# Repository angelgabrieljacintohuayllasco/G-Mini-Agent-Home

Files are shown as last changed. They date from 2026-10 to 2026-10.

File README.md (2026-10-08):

<p align="center">
  G-Mini Home: el compañero físico de G-Mini Agent
</p>

# G-Mini Home

**El compañero físico de [G-Mini Agent](https://github.com/angelgabrieljacintohuayllasco/G-Mini-Agent).**
Una carita con ojos animados que te escucha, te responde y muestra lo que
está haciendo el agente, mientras el trabajo real (controlar la PC, revisar el
correo, ejecutar tareas 24/7) corre en tu PC o en tu servidor.

Piensa en un "Alexa" con acceso a tu PC, tu laptop, tu celular y tu servidor:
el dispositivo pone la cara, el micrófono y el parlante; G-Mini pone el cerebro.

[English version](README.en.md)

## Variantes

| | Variante | Hardware | Dificultad | Costo aprox. | Guía |
|---|---|---|---|---|---|
| 1 | **Cara USB** | Arduino Uno o Nano + OLED 0,96" + 2 botones, conectado a la PC | Fácil | US$ 10-17 / S/ 55-95 | [usb-face](docs/guides/usb-face.md) |
| 2 | **Compañero WiFi** | ESP32-S3 + OLED (o TFT ST7789 / GC9A01) + micrófono I2S + parlante | Media | US$ 20-30 / S/ 115-185 | [esp32-wifi](docs/guides/esp32-wifi.md) |
| 3 | **Parlante con LEDs** | ESP32 + micrófono + parlante + anillo WS2812 (la cara son los LEDs) | Media | US$ 20-35 / S/ 115-220 | [speaker](docs/guides/speaker.md) |
| 4 | **Raspberry Pi** | Pi 4/5 o Zero 2 W + pantalla HDMI/SPI + audio USB | Fácil | US$ 75-140 / S/ 330-650 | [raspberry-pi](docs/guides/raspberry-pi.md) |
| 5 | **PC vieja o tablet** | El cliente de la Pi en cualquier PC, o la página de kiosco | Muy fácil | US$ 0 | [kiosk](docs/guides/kiosk.md) |
| | **Hologramas** | Pirámide y caja de Pepper, niebla, humo, LCD transparente, POV... | Variable | desde US$ 1 / S/ 3 | [hologramas](docs/holograms/README.md) |

<p align="center">
  Expresiones de la cara
</p>

## Cómo funciona

Arquitectura

Todos los dispositivos hablan con el núcleo de G-Mini por la **G-Mini Remote
API v1** (REST + WebSocket, puerto 8765):

- **Emparejamiento** con un código de 6 dígitos (o el enlace `gmini://pair?...`
  del QR): cada dispositivo tiene su propio token y se revoca por separado.
- **Estado del agente** por WebSocket (`idle`, `listening`, `thinking`,
  `acting`, `speaking` y la emoción) para animar los ojos, y avisos (`notify`).
- **Voz**: pulsar para hablar graba WAV de 16 kHz y lo envía a
  `/api/v1/voice/turn` (STT, agente y TTS en una sola llamada); la respuesta se
  reproduce mientras llega. "Oye G-Mini" opcional con `/api/v1/voice/wake`.
- **Superficies de nodo**: el agente puede usar el dispositivo (`display.face`,
  `display.text`, `led.set`, `relay.set`, `sensor.read`, `system.info`,
  `tts.speak`).

Los ojos salen de un mismo motor en C++ (AVR y ESP32), Python (Pi y PC) y
JavaScript (kiosco), generado desde [`common/expressions.json`](common/expressions.json):
parpadeo natural, mirada que se mueve, transiciones suaves a 30-40 cuadros por
segundo y nueve emociones. Detalles en [expresiones](docs/expressions.md).

## Empezar

Antes de nada: G-Mini tiene que ser accesible desde el dispositivo (modo
servidor o "Permitir conexiones" en Ajustes > Dispositivos > Este equipo). Ver
[conectar con G-Mini](docs/connect-gmini.md).

**Cara USB en 30 minutos** (Arduino + OLED + PC con G-Mini):

```bash
arduino-cli compile --fqbn arduino:avr:uno --library firmware/libraries/GMiniEyes firmware/arduino-usb-face
arduino-cli upload  --fqbn arduino:avr:uno -p COM5 firmware/arduino-usb-face
cd bridge && pip install -r requirements.txt
python gmini_serial_bridge.py --url http://127.0.0.1:8765 --pair 482913
```

**Compañero WiFi** (ESP32-S3): graba `gmini-home-esp32s3-oled-factory.bin` de
la release en `0x0` (o `pio run -e esp32s3-oled -t upload`), conéctate a la red
`G-Mini-Home-XXXX` (clave `gminihome`) y escribe tu WiFi, el servidor y el
código de emparejamiento.

**Raspberry Pi:**

```bash
cd raspberry-pi && sudo ./install.sh --url http://192.168.1.50:8765 --pair 482913
```

## Contenido del repositorio

```
firmware/
  esp32-companion/      firmware WiFi (PlatformIO, Arduino): 7 entornos + pruebas nativas
  arduino-usb-face/     sketch para Uno y Nano
  libraries/GMiniEyes   motor de ojos, rasterizado y protocolo serie (C++ portable)
  libraries/GMiniLink   HTTP, JSON, base64 y WAV en flujo, VAD (C++ portable)
bridge/                 puente serie <-> G-Mini en Python
raspberry-pi/           cliente pygame, instalador y servicio systemd
kiosk/                  página de kiosco para tablets (sin dependencias)
common/                 expressions.json y la biblioteca Python gmini_link
hardware/               BOM, cableado, carcasas OpenSCAD, STL, renders y plantillas
docs/                   guías, hologramas, seguridad, problemas y preguntas frecuentes
tools/                  generadores de presets, diagramas, plantillas y renders
tests/                  pruebas de Python (pytest)
```

## Desarrollo

```bash
pip install -r requirements-dev.txt
pytest                                                   # 87 pruebas de Python
ruff check common bridge raspberry-pi tools tests

cd firmware/esp32-companion
pio test -e native                                       # 41 pruebas en el host (motor, protocolo, HTTP/JSON/WAV)
pio run -e esp32s3-oled                                  # o cualquiera de los 7 entornos

python tools/codegen/gen_expressions.py                  # tras editar common/expressions.json
python tools/diagrams/build_all.py                       # diagramas SVG y tablas de cableado
python tools/templates/pepper_pyramid.py                 # plantillas de la pirámide
python tools/render_enclosures.py                        # STL y renders (necesita OpenSCAD)
python tools/e2e_smoke.py --url http://IP:8765 --pair CODIGO   # prueba contra un G-Mini real
```

La CI compila los 7 entornos del ESP32, el sketch para Uno, Nano y Nano con
bootloader viejo, corre las pruebas nativas y de Python, verifica que los
archivos generados estén al día y renderiza las carcasas con OpenSCAD. Cada
etiqueta `v*` publica una release con los binarios (imagen completa para `0x0`
y piezas sueltas), los `.hex`, los STL, los diagramas y los zips del puente y
del cliente de la Pi.

## Estado

Verificado en esta versión: compilación de todos los entornos del firmware
(tamaños en [grabación](docs/flashing.md)), pruebas nativas y de Python, y una
prueba de punta a punta contra un G-Mini real en modo servidor
(emparejamiento, `/me`, WebSocket con registro de nodo, TTS, STT y
`/voice/wake`). Falta probar con el hardware físico armado: audio I2S, cada
pantalla y el anillo LED se validan al construir el primer prototipo de cada
variante.

## Documentación

- [Conectar con G-Mini](docs/connect-gmini.md) y [protocolo serie](docs/serial-protocol.md)
- [Lista de materiales](hardware/bom.md), [cableado](hardware/README.md#cableado) y [carcasas](hardware/README.md#carcasas)
- [Grabar el firmware](docs/flashing.md)
- [Hologramas](docs/holograms/README.md)
- [Seguridad](docs/safety.md), [solución de problemas](docs/troubleshooting.md) y [preguntas frecuentes](docs/faq.md)
- [Cómo contribuir](CONTRIBUTING.md), [seguridad del proyecto](SECURITY.md) y [cambios](CHANGELOG.md)

## Licencia

Código bajo [MIT](LICENSE). Diseños de hardware y documentación bajo
[CC BY-SA 4.0](LICENSE-hardware.md).

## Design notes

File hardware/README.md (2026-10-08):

# Hardware

Todo lo físico de G-Mini Home: listas de materiales, cableado, carcasas
imprimibles y plantillas de corte. Licencia de estos diseños: CC BY-SA 4.0
([LICENSE-hardware.md](../LICENSE-hardware.md)).

| Carpeta | Contenido | Se genera con |
|---|---|---|
| [bom.md](bom.md) | Lista de materiales por variante con precios USD y PEN | a mano |
| [wiring/](wiring/) | Diagramas SVG y tablas de conexión por variante | `python tools/diagrams/build_all.py` |
| [enclosures/](enclosures/) | Carcasas paramétricas en OpenSCAD | a mano |
| [stl/](stl/) | Piezas listas para imprimir (STL binario) | `python tools/render_enclosures.py` |
| [renders/](renders/) | Imágenes de piezas y conjuntos | `python tools/render_enclosures.py` |
| [templates/](templates/) | Plantillas de corte de la pirámide de Pepper (SVG 1:1 y DXF) | `python tools/templates/pepper_pyramid.py` |

## Cableado

| Variante | Diagrama | Tabla |
|---|---|---|
| ESP32-S3 + OLED | [SVG](wiring/esp32s3-oled.svg) | [esp32s3-oled.md](wiring/esp32s3-oled.md) |
| ESP32-S3 + ST7789 / GC9A01 | [SVG](wiring/esp32s3-tft.svg) | [esp32s3-tft.md](wiring/esp32s3-tft.md) |
| ESP32-S3 parlante con LEDs | [SVG](wiring/esp32s3-speaker.svg) | [esp32s3-speaker.md](wiring/esp32s3-speaker.md) |
| ESP32-S3 + relés y LDR | [SVG](wiring/esp32s3-relays.svg) | [esp32s3-relays.md](wiring/esp32s3-relays.md) |
| ESP32 clásico (DevKit V1) | [SVG](wiring/esp32dev.svg) | [esp32dev.md](wiring/esp32dev.md) |
| Arduino Uno / Nano por USB | [SVG](wiring/arduino-usb-face.svg) | [arduino-usb-face.md](wiring/arduino-usb-face.md) |
| Raspberry Pi (botones) | [SVG](wiring/raspberry-pi.svg) | [raspberry-pi.md](wiring/raspberry-pi.md) |

Cableado ESP32-S3 + OLED

## Carcasas

| Modelo | Piezas | Vista |
|---|---|---|
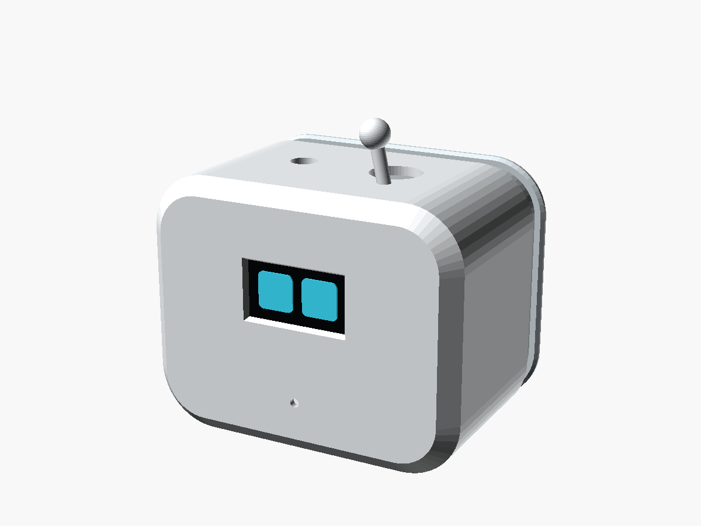
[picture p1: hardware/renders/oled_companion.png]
| [oled_companion.scad](enclosures/oled_companion.scad): cabecita para la OLED | [cuerpo](stl/oled_companion-shell.stl), [tapa](stl/oled_companion-back.stl) |  |
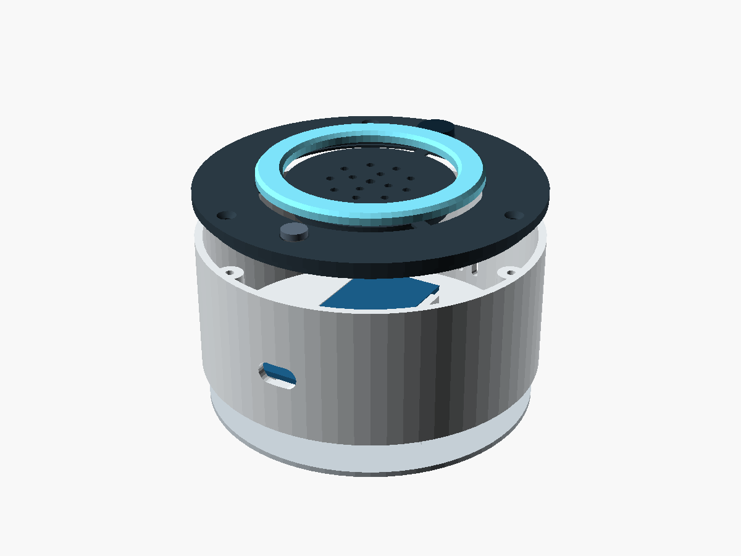
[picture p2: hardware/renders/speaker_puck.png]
| [speaker_puck.scad](enclosures/speaker_puck.scad): parlante con anillo LED | [cuerpo](stl/speaker_puck-base.stl), [tapa](stl/speaker_puck-top.stl), [difusor](stl/speaker_puck-diffuser.stl), [fondo](stl/speaker_puck-bottom.stl) |  |
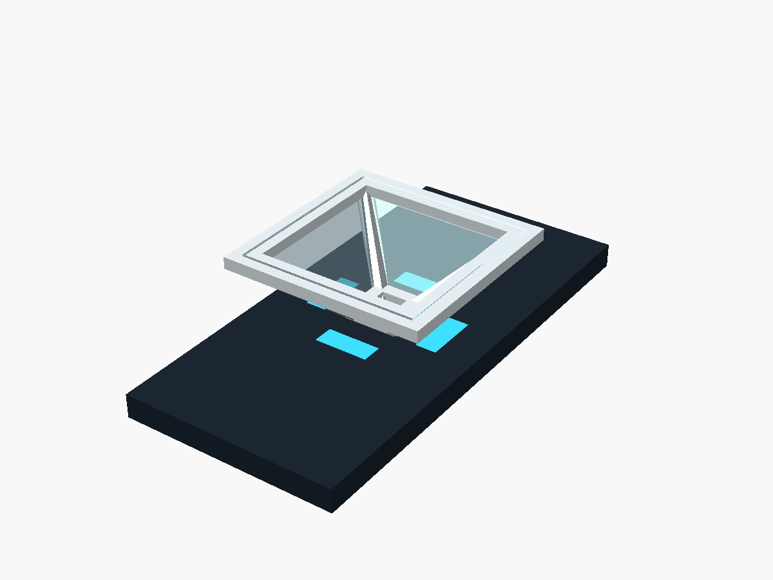
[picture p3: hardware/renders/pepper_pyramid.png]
| [pepper_pyramid.scad](enclosures/pepper_pyramid.scad): marco de la pirámide | [marco](stl/pepper_pyramid-frame.stl) |  |

### Impresión

- PLA o PETG, capa de 0,2 mm, 3 perímetros, 15-20 % de relleno.
- `oled_companion`: el cuerpo se imprime con la cara apoyada en la cama; la
  antena decorativa necesita un soporte pequeño (o ponla en `antenna = false`).
  La tapa se imprime con la cara exterior hacia abajo.
- `speaker_puck`: cuerpo y fondo sin soportes; la tapa boca abajo; el difusor
  en PETG natural o PLA blanco al 100 % de relleno para que la luz se reparta.
- `pepper_pyramid`: marco boca abajo (aro grande en la cama), sin soportes.
- Ajusta las medidas a tus módulos con el Customizer de OpenSCAD
  (Ventana > Personalizador): cada parámetro tiene un comentario.

### Exportar tus cambios

```bash
python tools/render_enclosures.py              # STL + PNG de todo
python tools/render_enclosures.py --only puck  # solo el parlante
```

El script busca OpenSCAD en `$OPENSCAD`, en el `PATH` o en
`E:\tools\openscad` (Windows). En Linux sin escritorio usa `xvfb-run`.

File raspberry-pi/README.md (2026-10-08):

# Cliente de pantalla de G-Mini Home

La cara de G-Mini a pantalla completa con voz, para Raspberry Pi (4, 5 o
Zero 2 W), mini PC o una PC vieja. Incluye la página de kiosco para tablets.

```bash
sudo ./install.sh --url http://192.168.1.50:8765 --pair 482913
```

Probar sin servidor: `python -m gmini_pi --demo --windowed` (desde esta
carpeta, con `PYTHONPATH=../common` si usas el repositorio).

| Archivo | Para qué |
|---|---|
| `install.sh` / `uninstall.sh` | Instala o quita el servicio `gmini-pi` |
| `config.example.toml` | Configuración comentada (se copia a `/etc/gmini-home/config.toml`) |
| `gmini-pi.service` | Plantilla del servicio de systemd |
| `gmini_pi/` | Código del cliente |

Guías: [Raspberry Pi](../docs/guides/raspberry-pi.md) y
[PC vieja o tablet](../docs/guides/kiosk.md).

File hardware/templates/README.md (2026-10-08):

# Plantillas de corte: pirámide de Pepper

Generadas por `tools/templates/pepper_pyramid.py` (no editar a mano). Todas las medidas en milímetros.
La guía completa está en [docs/holograms/pyramid.md](../../docs/holograms/pyramid.md).

| Pantalla | Lado corto útil | b (lado mayor) | a (lado menor) | Alto del trapecio | Altura | Material | Archivos |
|---|---|---|---|---|---|---|---|
| Teléfono 6,1" | 65 | 60 | 10 | 35.4 | 25.0 | PET o acetato de 0,5 mm (o tapa de CD) | [SVG](pyramid-phone-6.1-net.svg) · [DXF abanico](pyramid-phone-6.1-net.dxf) · [DXF piezas](pyramid-phone-6.1-pieces.dxf) |
| Teléfono 6,7" | 71 | 66 | 11 | 38.9 | 27.5 | PET o acetato de 0,5 mm | [SVG](pyramid-phone-6.7-net.svg) · [DXF abanico](pyramid-phone-6.7-net.dxf) · [DXF piezas](pyramid-phone-6.7-pieces.dxf) |
| Tablet 8" | 108 | 102 | 17 | 60.1 | 42.5 | PET de 0,5-0,75 mm | [SVG](pyramid-tablet-8-net.svg) · [DXF abanico](pyramid-tablet-8-net.dxf) · [DXF piezas](pyramid-tablet-8-pieces.dxf) |
| Tablet 10,1" | 136 | 128 | 21 | 75.7 | 53.5 | PET de 0,75 mm | [SVG](pyramid-tablet-10-net.svg) · [DXF abanico](pyramid-tablet-10-net.dxf) · [DXF piezas](pyramid-tablet-10-pieces.dxf) |
| Tablet 11" (4:3) | 168 | 158 | 26 | 93.3 | 66.0 | PET de 0,75-1 mm | [SVG](pyramid-tablet-11-net.svg) · [DXF abanico](pyramid-tablet-11-net.dxf) · [DXF piezas](pyramid-tablet-11-pieces.dxf) |
| Portátil 15,6" | 194 | 184 | 31 | 108.2 | 76.5 | PETG o acrílico de 2 mm | [SVG](pyramid-laptop-15.6-net.svg) · [DXF abanico](pyramid-laptop-15.6-net.dxf) · [DXF piezas](pyramid-laptop-15.6-pieces.dxf) |
| Monitor 24" | 299 | 282 | 47 | 166.2 | 117.5 | Acrílico de 2-3 mm | [SVG](pyramid-monitor-24-net.svg) · [DXF abanico](pyramid-monitor-24-net.dxf) · [DXF piezas](pyramid-monitor-24-pieces.dxf) |
| Monitor 27" | 336 | 318 | 53 | 187.4 | 132.5 | Acrílico de 3 mm | [SVG](pyramid-monitor-27-net.svg) · [DXF abanico](pyramid-monitor-27-net.dxf) · [DXF piezas](pyramid-monitor-27-pieces.dxf) |
| TV 32" | 398 | 378 | 63 | 222.7 | 157.5 | Acrílico de 3 mm con marco | [SVG](pyramid-tv-32-net.svg) · [DXF abanico](pyramid-tv-32-net.dxf) · [DXF piezas](pyramid-tv-32-pieces.dxf) |

- Las caras quedan a 45° de la pantalla: altura = (b - a) / 2 y alto del trapecio = altura x 1,414.
- Los lados del trapecio forman 54,74° con la base. En el abanico cada cara abre 70,53°.
- La imagen flotante puede medir como máximo la altura de la pirámide.
- Acrílico: las aristas se unen a 120°; bisela 30° los cantos laterales o une por fuera con cinta
  transparente o pegamento UV. Lámina fina: usa el abanico (SVG o DXF) y la pestaña de 8 mm.

## Caja de Pepper (una placa a 45°)

Pantalla boca arriba en el piso de una caja y una placa a 45° que cubre su profundidad.

| Pantalla | Pantalla (largo x ancho) | Placa (largo x ancho) | Alto interior mínimo |
|---|---|---|---|
| Teléfono 6,1" | 141 x 65 | 141 x 92 | 65 |
| Teléfono 6,7" | 155 x 71 | 155 x 101 | 71 |
| Tablet 8" | 172 x 108 | 172 x 152 | 108 |
| Tablet 10,1" | 218 x 136 | 218 x 192 | 136 |
| Tablet 11" (4:3) | 224 x 168 | 224 x 237 | 168 |
| Portátil 15,6" | 345 x 194 | 345 x 275 | 194 |
| Monitor 24" | 531 x 299 | 531 x 423 | 299 |
| Monitor 27" | 598 x 336 | 598 x 475 | 336 |
| TV 32" | 708 x 398 | 708 x 564 | 398 |

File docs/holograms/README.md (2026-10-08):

# Hologramas: la cara flotando en el aire

Ninguna de estas técnicas es holografía en sentido estricto (eso requiere
registrar la interferencia de un láser). Son ilusiones de **imagen flotante**:
reflejos en vidrio, proyección sobre medios casi invisibles o persistencia de la
visión. Bien hechas, convencen a cualquiera.

Todas usan las caras de G-Mini Home: el cliente de la Raspberry Pi o de una
PC (`display.layout = "pyramid"` o `"mirror"`), la página de kiosco en una
tablet (`?layout=pyramid`) o el video de la cara en un proyector o ventilador.

| Técnica | Dificultad | Costo (USD / PEN) | Tamaño | Lo mejor | Lo peor |
|---|---|---|---|---|---|
| [Pirámide de Pepper](pyramid.md) | Muy fácil | 1-25 / 3-90 | 3-15 cm | Barata, se ve desde 4 lados | Imagen chica, sala oscura |
| [Caja de Pepper](pepper-box.md) | Fácil | 10-40 / 35-150 | 10-40 cm | Muy brillante y nítida | Se ve desde un solo lado |
| [Pantalla de niebla](fog-screen.md) | Media | 60-200 / 220-750 | 30-100 cm | Imagen en el aire, se atraviesa | Agua, ruido, proyector |
| [Cortina de humo](smoke-curtain.md) | Media | 80-250 / 300-950 | 0,5-2 m | Grande, efecto de escenario | Humo, ventilación |
| [LCD transparente](transparent-lcd.md) | Media-alta | 0-60 / 0-230 | 15-60 cm | Imagen sobre objetos reales | Desarme delicado |
| [Ventilador POV](pov-fan.md) | Fácil (comprado) | 60-150 / 220-560 | 25-65 cm | Muy llamativo, en 3D aparente | Peligroso, ruidoso |
| [Volumétrica de barrido](volumetric.md) | Muy alta | 100-400 / 375-1500 | 10-20 cm | Volumen real, se ve desde todos lados | Proyecto de investigación |
| [Film o tul holográfico](holo-gauze.md) | Media | 30-150 / 110-560 | 0,5-3 m | Escala de escenario | Necesita proyector y oscuridad |
| [Imagen aérea](aerial-image.md) | Media | 30-70 / 110-260 | 5-20 cm | Imagen real "tocable" | Tenue, ángulo limitado |
| [Mirascopio con pantalla](mirascope.md) | Fácil | 15-40 / 55-150 | 3-6 cm | Imagen real nítida, curiosa | Muy chica |

Antes de empezar: [seguridad](../safety.md) (agua y niebla, humo, vidrio de
LCD, solventes, piezas giratorias).

## Recomendación

- **Primera vez:** pirámide de PET sobre el celular (15 minutos).
- **Para el escritorio:** caja de Pepper con una tablet o un monitor chico y el
  cliente en modo `mirror`: la mejor relación brillo/costo.
- **Para una feria o un evento:** cortina de niebla o tul con proyector.

Plantillas de corte de la pirámide: [hardware/templates/](../../hardware/templates/README.md).

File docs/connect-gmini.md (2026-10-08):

# Conectar un dispositivo con G-Mini

Todas las variantes hablan con el núcleo de G-Mini Agent por la
**G-Mini Remote API v1** (REST + WebSocket en el puerto `8765`). Esta página
explica qué tiene que estar listo del lado de G-Mini antes de armar nada.

## 1. ¿Dónde corre G-Mini?

| Núcleo | Quién puede conectarse | Uso típico |
|---|---|---|
| Escritorio (Windows), por defecto | Solo la misma PC (`127.0.0.1`) | Cara USB (variante 1) con el puente en esa PC |
| Escritorio con **Permitir conexiones** por Tailscale | Equipos de tu Tailscale (PC, Pi, celular) | Raspberry Pi, otra PC con el puente |
| Escritorio con **Permitir conexiones** en todas las redes | Cualquier equipo de tu red, incluido un ESP32 | ESP32 en la misma WiFi |
| Servidor 24/7 (`--headless --host 0.0.0.0`) | Tu red local (y Tailscale/VPN si lo configuras) | Todas las variantes |

"Permitir conexiones" está en **Ajustes > Dispositivos > Este equipo** de la
app de escritorio. Con Tailscale instalado, G-Mini escucha además en tu IP de
Tailscale sin abrirse a la WiFi. Un ESP32 **no puede** unirse a Tailscale:
para las variantes 2 y 3 usa "todas las redes" o un G-Mini en modo servidor en
tu red.

Modo servidor (Linux, mini PC o una laptop vieja):

```bash
python -m backend.main --headless --host 0.0.0.0 --port 8765
```

Comprueba desde otro equipo que responde (no necesita token):

```bash
curl http://IP-DEL-SERVIDOR:8765/api/v1/health
# {"ok": true, "protocol": 1, "mode": "server", ...}
```

Si no responde: firewall del sistema (permite el puerto TCP 8765 solo en tu red
privada), IP equivocada o el núcleo escuchando solo en `127.0.0.1`.

## 2. Emparejar

Cada dispositivo recibe su propio token y se puede revocar por separado.

1. En G-Mini: **Ajustes > Dispositivos > Este equipo > Emparejar un
   dispositivo**. Aparece un código de 6 dígitos y un QR con un enlace
   `gmini://pair?host=...&port=8765&code=...`. El código vence a los 5 minutos
   y sirve una sola vez.
2. En el dispositivo, según la variante:
   - ESP32: en el portal WiFi pega el código o el enlace completo, o por la
     consola serie: `emparejar 482913`.
   - Puente USB: `python gmini_serial_bridge.py --url http://IP:8765 --pair 482913`.
   - Raspberry Pi: `sudo ./install.sh --url http://IP:8765 --pair 482913`.
3. El dispositivo aparece en la lista de **Dispositivos**. Desde ahí lo
   revocas si lo pierdes o lo regalas.

Límites del servidor: 5 intentos por minuto por IP; al quinto fallo el código
se invalida. Pide uno nuevo.

Sin la app (por ejemplo, un servidor recién instalado), un token con permiso
`admin` puede pedir el código:

```bash
curl -X POST http://IP:8765/api/v1/pairing \
  -H "Authorization: Bearer $(cat ~/.local/share/g-mini/data/runtime/session_token)" \
  -H "Content-Type: application/json" \
  -d '{"label": "Cara de la sala", "device_type": "esp32", "scopes": ["chat", "voice", "node"]}'
```

## 3. Qué permisos usa cada variante

| Scope | Para qué |
|---|---|
| `voice` | Turnos de voz, palabra de activación y texto a voz |
| `chat` | Pedidos en texto después de "Oye G-Mini" y el turno de voz |
| `node` | Registrar la cara como superficie (`display.face`, `led.set`, `relay.set`...) |

`relay.set` controla cargas físicas: el agente lo pasa por su política de
aprobaciones igual que cualquier acción local.

## 4. Fuera de casa

Para usar un dispositivo fuera de tu red: Tailscale (PC, Pi) o un proxy con
TLS delante del servidor (Caddy, Nginx). El ESP32 acepta direcciones
`https://`, pero solo cifra: no verifica el certificado del servidor (ver
[seguridad](safety.md#red-y-tokens)). Nunca publiques el puerto 8765
directamente en tu router.

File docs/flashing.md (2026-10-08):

# Grabar el firmware

## ESP32 / ESP32-S3

### Entornos

| Entorno | Placa | Pantalla | Anillo |
|---|---|---|---|
| `esp32s3-oled` | ESP32-S3-DevKitC-1 N16R8 | SSD1306 128x64 | opcional |
| `esp32s3-sh1106` | ESP32-S3-DevKitC-1 N16R8 | SH1106 128x64 (1,3") | opcional |
| `esp32s3-st7789` | ESP32-S3-DevKitC-1 N16R8 | ST7789 240x280 | opcional |
| `esp32s3-gc9a01` | ESP32-S3-DevKitC-1 N16R8 | GC9A01 240x240 redonda | opcional |
| `esp32s3-speaker` | ESP32-S3-DevKitC-1 N16R8 | sin pantalla | sí |
| `esp32dev-oled` | ESP32 DevKit V1 (WROOM-32) | SSD1306 | opcional |
| `esp32dev-speaker` | ESP32 DevKit V1 (WROOM-32) | sin pantalla | sí |

### Con los binarios de la release

Cada release trae, por entorno:

- `gmini-home-<entorno>-factory.bin`: imagen completa, se graba en `0x0`.
- Las piezas sueltas por si prefieres grabarlas aparte:

| Archivo | ESP32-S3 | ESP32 clásico |
|---|---|---|
| `bootloader.bin` | `0x0` | `0x1000` |
| `partitions.bin` | `0x8000` | `0x8000` |
| `boot_app0.bin` | `0xe000` | `0xe000` |
| `firmware.bin` | `0x10000` | `0x10000` |

```bash
pip install esptool
# Imagen completa
esptool.py --chip esp32s3 --port COM7 --baud 921600 write_flash 0x0 gmini-home-esp32s3-oled-factory.bin
# Piezas sueltas (ESP32-S3)
esptool.py --chip esp32s3 --port COM7 --baud 921600 write_flash \
  0x0 bootloader.bin 0x8000 partitions.bin 0xe000 boot_app0.bin 0x10000 firmware.bin
```

Sin instalar nada: abre [esptool-js](https://espressif.github.io/esptool-js/)
en Chrome o Edge, conecta la placa, agrega el `factory.bin` en `0x0` y graba.

Si la placa no entra en modo de grabación: mantén **BOOT**, toca **RST** y
suelta BOOT. En el DevKitC-1 usa el conector USB marcado **UART** (o el
**USB** nativo; ambos sirven con esptool).

### Compilando con PlatformIO

```bash
pip install platformio
cd firmware/esp32-companion
pio run -e esp32s3-oled                 # compila
pio run -e esp32s3-oled -t upload       # compila y graba
pio device monitor                      # consola serie (115200)
pio test -e native                      # pruebas en la PC (necesita gcc)
```

Tamaños de referencia (PlatformIO, espressif32 7.1.3, Arduino-ESP32 2.0.17):

| Entorno | RAM | Flash |
|---|---|---|
| esp32s3-oled | 66,0 KB (20,1 %) | 1,09 MB de 6,25 MB (16,7 %) |
| esp32s3-st7789 / gc9a01 | 66,8 KB (20,4 %) | 1,17 MB (17,8 %) |
| esp32s3-speaker | 64,4 KB (19,6 %) | 1,06 MB (16,1 %) |
| esp32dev-oled | 66,1 KB (20,2 %) | 1,14 MB de 1,88 MB (58,0 %) |
| esp32dev-speaker | 64,5 KB (19,7 %) | 1,11 MB (56,2 %) |

Cambiar pines u opciones sin tocar el código: agrega `build_flags` al entorno,
por ejemplo `-DPIN_BTN_TALK=41 -DGMINI_RELAY_COUNT=0 -DGMINI_LED_COUNT=16`.
Todas las opciones están en `firmware/esp32-companion/include/config.h`.

## Arduino Uno / Nano

```bash
arduino-cli core install arduino:avr
arduino-cli lib install U8g2
arduino-cli compile --fqbn arduino:avr:uno --library firmware/libraries/GMiniEyes firmware/arduino-usb-face
arduino-cli upload  --fqbn arduino:avr:uno -p COM5 firmware/arduino-usb-face
```

La release incluye los `.hex` para Uno, Nano y Nano con bootloader viejo:

```bash
avrdude -p atmega328p -c arduino -P COM5 -b 115200 -U flash:w:arduino-usb-face-uno.hex:i
avrdude -p atmega328p -c arduino -P COM5 -b 57600  -U flash:w:arduino-usb-face-nano-old.hex:i
```

Tamaño: 29 300 bytes de flash (95 % de un Nano) y 1 644 bytes de RAM.

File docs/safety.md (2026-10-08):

# Seguridad

Lee esta página antes de construir. La mayoría de las variantes trabajan con
5 V de un cargador USB y son seguras; los riesgos reales están en los relés con
220 V, las baterías de litio, el agua cerca de la electricidad y los vidrios y
solventes de los hologramas.

## Tensión de red (relés)

- Los relés de los módulos para Arduino/ESP32 pueden conmutar 220 V, pero el
  **cableado de 220 V es peligroso**: una descarga puede matar y un mal empalme
  puede iniciar un incendio.
- Desenchufa todo antes de tocar los bornes. Usa caja cerrada (nada de
  protoboard con 220 V), cable de la sección adecuada, terminales con
  aislamiento, fusible y alivio de tensión en los cables.
- Respeta las distancias del módulo: no apoyes los bornes de 220 V sobre metal
  ni cerca de la placa del ESP32.
- Si no tienes experiencia, usa solo cargas de 5-12 V (tiras LED, ventiladores)
  o un enchufe inteligente comercial.
- `relay.set` pasa por la política de aprobaciones de G-Mini: no la desactives
  para cargas peligrosas (estufas, calentadores, bombas).

## Baterías de litio

- Usa celdas 18650 o LiPo con circuito de protección y un cargador para litio
  (TP4056 con protección, o un power bank). Nunca cargues una celda directa
  desde 5 V.
- No perfores, dobles ni aplastes baterías; si una se hincha, desconéctala y
  llévala a un punto de reciclaje.
- No dejes cargando sin supervisión dentro de carcasas cerradas de PLA: el PLA
  se deforma a ~60 °C.

## Herramientas y armado

- **Cautín**: superficie no inflamable, soporte, ventilación (el humo del
  flux irrita) y lávate las manos después de soldar (el estaño puede tener
  plomo).
- **Pistola de silicona**: la punta y la silicona queman (más de 150 °C).
  No la uses sobre cables de 220 V como aislante.
- **Cutter y acrílico**: regla metálica, corte hacia afuera del cuerpo, varias
  pasadas suaves. Lentes de protección al romper acrílico por la marca.
- **Impresora 3D**: no la dejes sola en las primeras capas; ventila si
  imprimes ABS o ASA.

## Agua, niebla y humo (hologramas)

- Los nebulizadores ultrasónicos funcionan en agua: alimenta siempre con una
  **fuente de 12/24 V de baja tensión** y deja la fuente de 220 V lejos del
  depósito y por encima del nivel del agua.
- Usa agua destilada: el agua de caño deja polvo blanco (minerales) en todo.
- Mantén proyectores, laptops y placas fuera del alcance de la niebla y de
  posibles derrames. Un trapo absorbente bajo el depósito ayuda.
- Máquinas de humo: el fluido de glicol irrita las vías respiratorias y activa
  detectores de humo; ventila la sala. El **hielo seco** desplaza el oxígeno:
  nunca en espacios cerrados ni en contacto con la piel (quema por frío).

## LCD transparente

- El vidrio de los LCD se rompe en astillas muy filosas: guantes anticorte y
  lentes durante todo el desarme.
- **Retroiluminación**: los monitores viejos con CCFL (tubos) tienen
  inversores de alta tensión (más de 1000 V) que retienen carga; desenchufa,
  espera varios minutos y no toques el inversor. Los tubos contienen mercurio:
  no los rompas y llévalos a reciclaje.
- **Polarizador**: para despegar adhesivos usa calor suave (secador de pelo) o
  alcohol isopropílico. **No uses acetona sobre el vidrio ni sobre plásticos**:
  disuelve los polarizadores y el acrílico. Trabaja ventilado y lejos de
  llamas (el alcohol es inflamable).
- No presiones el vidrio del LCD sin su marco: se agrieta y deja de funcionar.

## Ventiladores POV y piezas giratorias

- Las aspas giran a cientos de RPM: usa siempre la cúpula o protección,
  fíjalos firmes a la pared o a una base pesada y mantenlos fuera del alcance
  de niños y mascotas.
- Los proyectos volumétricos de barrido requieren equilibrado y una cubierta
  transparente cerrada: una pieza que se suelta a alta velocidad es un
  proyectil.

## Láser y proyectores

- No mires directo al haz de un proyector ni de un láser; en cortinas de humo
  apunta la proyección por encima de la altura de los ojos.

## Red y tokens

- Cada dispositivo tiene su propio token: si lo pierdes, lo regalas o lo
  desarmas, **revócalo** en Ajustes > Dispositivos.
- En el ESP32 el token se guarda en la NVS sin cifrar (lo puede leer quien
  tenga la placa en la mano). Para producción activa el cifrado de flash y de
  NVS de ESP-IDF; para casa, revocar alcanza.
- Las direcciones `https://` en el ESP32 cifran la conexión pero **no
  verifican el certificado** del servidor. Úsalas solo con tu propio proxy y
  prefiere la red local o una VPN.
- Con la palabra de activación encendida, frases cortas de lo que se dice cerca
  viajan a tu servidor G-Mini (no a terceros). Avisa a quienes vivan contigo.
- No expongas el puerto 8765 a internet ni actives "todas las redes" en una
  WiFi pública.

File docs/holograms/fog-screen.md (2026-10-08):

# Pantalla de niebla

Pantalla de niebla

Una cortina fina y laminar de niebla de agua recibe la imagen de un proyector
colocado detrás. La niebla es casi invisible a simple vista, pero dispersa la
luz: la cara aparece flotando en el aire y se puede atravesar con la mano.

**Dificultad:** media. **Costo:** US$ 60-200 / S/ 220-750 (sin proyector:
US$ 25-50 / S/ 90-190). **Tiempo:** un fin de semana.

## Materiales

| Material | Costo |
|---|---|
| Nebulizador ultrasónico de 12/24 V (1-3 cabezales) con su fuente | US$ 10-25 / S/ 40-95 |
| Recipiente plástico (40 x 20 x 15 cm aprox.) | US$ 3-8 / S/ 10-30 |
| 1-2 ventiladores de PC de 12 V (80-120 mm) | US$ 3-8 / S/ 10-30 |
| Pajillas (sorbetes) cortadas a 4-6 cm, como panal de flujo laminar | US$ 1-2 / S/ 3-8 |
| Tubo o canal de PVC de 30-60 cm con ranura de 5 mm | US$ 3-8 / S/ 10-30 |
| Proyector (mini LED o un proyector viejo) | US$ 40-150 / S/ 150-560 |
| Agua destilada | US$ 1-2 / S/ 3-8 |

## Pasos

1. Pon el nebulizador en el recipiente con agua destilada (nivel según su
   flotador).
2. Tapa el recipiente y monta los ventiladores soplando hacia adentro: empujan
   la niebla hacia la salida superior.
3. Encima, fija el canal con la ranura y llénalo de pajillas paradas, bien
   apretadas: convierten el flujo turbulento en una cortina lisa (laminar).
4. Regula los ventiladores (bajo voltaje o un regulador PWM) hasta que la
   cortina suba recta 30-60 cm sin abrirse.
5. Pon el proyector detrás de la cortina, a la altura del centro, y proyecta la
   cara a pantalla completa con fondo negro (`gmini_pi --windowed` en la PC del
   proyector, o la página de kiosco).
6. Oscurece la sala. El observador mira desde el lado opuesto al proyector.

## Ventajas y desventajas

- El efecto más "de película": la imagen está en el aire y se atraviesa.
- Se ve mejor de frente al proyector (la niebla dispersa más hacia adelante).
- Corrientes de aire la deforman; necesita oscuridad.
- Moja lo que está cerca si la cortina es muy densa.

## Seguridad

Baja tensión (12/24 V) dentro y cerca del agua; la fuente de 220 V afuera y
por encima del nivel del agua. Proyector y electrónica lejos de la niebla. Ver
[seguridad: agua y niebla](../safety.md#agua-niebla-y-humo-hologramas).

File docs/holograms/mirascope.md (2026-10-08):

# Mirascopio con pantalla redonda

Mirascopio

Dos espejos parabólicos enfrentados (el de arriba con un agujero en el centro)
forman la imagen real de lo que está en el fondo justo sobre la abertura. El
juguete clásico muestra una moneda "flotando"; si en el fondo pones una
pantalla redonda GC9A01 con la cara, los ojos aparecen flotando arriba.

**Dificultad:** fácil. **Costo:** US$ 15-40 / S/ 55-150. **Tiempo:** 1 hora.

## Materiales

| Material | Costo |
|---|---|
| Mirascopio de juguete de 15-23 cm | US$ 10-25 / S/ 35-95 |
| Pantalla GC9A01 de 1,28" y un ESP32-S3 (variante `esp32s3-gc9a01`) | US$ 10-15 / S/ 75-105 |
| Cable plano fino para sacar la conexión | US$ 1-2 / S/ 3-8 |

## Pasos

1. Abre el mirascopio y pega la pantalla en el centro del espejo inferior, mirando
   hacia arriba. Saca el cable por el borde (los espejos se unen a presión).
2. Graba el firmware `esp32s3-gc9a01` y sube el brillo al máximo
   (`brillo 255` en la consola).
3. Cierra el mirascopio: la cara aparece sobre la abertura superior. Mira desde
   un costado, un poco por encima.

## Ventajas y desventajas

- Imagen real nítida y sorprendente, ocupa muy poco.
- Muy pequeña (del tamaño de la pantalla) y sensible a la luz del techo.
- El cable de la pantalla tiene que pasar entre los espejos.

## Seguridad

Sin riesgos especiales. El ESP32 y la pantalla calientan poco, pero deja el
cable con algo de holgura para no doblarlo.

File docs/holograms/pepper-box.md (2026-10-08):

# Caja de Pepper (una placa a 45°)

Caja de Pepper

La versión de teatro del siglo XIX: una pantalla boca arriba en el piso de una
caja oscura y una placa transparente a 45° delante del observador. La pantalla
queda oculta y su reflejo aparece "dentro" de la caja, detrás del vidrio, con
lo que haya al fondo visible a través de la cara.

**Dificultad:** fácil. **Costo:** US$ 10-40 / S/ 35-150. **Tiempo:** 2-3 horas.

## Medidas

Para una pantalla de largo L y ancho (profundidad) P:

- Placa: L x (P x 1,41).
- Interior de la caja: L de ancho, P de profundidad y al menos P de alto.
- Tabla de tamaños comunes en [hardware/templates/README.md](../../hardware/templates/README.md#caja-de-pepper-una-placa-a-45).

## Materiales

| Material | Costo |
|---|---|
| Vidrio fino de 2 mm (vidriería), acrílico de 2 mm o PET de 0,5 mm | US$ 3-15 / S/ 10-55 |
| Cartón pluma o MDF de 3 mm para la caja | US$ 3-12 / S/ 10-45 |
| Pintura negra mate o cartulina negra | US$ 2-5 / S/ 6-18 |
| Tablet, monitor chico o pantalla HDMI | la que tengas |

## Pasos

1. Arma una caja abierta por delante, con el interior negro mate (cuanto más
   negro, más contraste).
2. Pon la pantalla boca arriba en el piso de la caja.
3. Fija la placa en diagonal: arriba contra la pared del fondo y abajo contra el
   borde frontal del piso (45°). Ranuras en las paredes laterales o dos listones
   triangulares sirven de guía.
4. Muestra la cara espejada: `python -m gmini_pi --layout mirror` o el kiosco
   con `?layout=mirror`. Si la cara sale cabeza abajo, gira la pantalla 180°.
5. Opcional: pon un objeto real al fondo de la caja (una figura, una planta):
   la cara flota delante de él.

## Ventajas y desventajas

- Muy brillante y nítida, incluso con algo de luz en la sala.
- Puede ser tan grande como la pantalla que pongas.
- Se ve bien desde un solo lado y en un ángulo de unos 60°.
- El vidrio refleja también la sala: cuanto más oscuro el frente, mejor.

## Seguridad

Lija o encinta los cantos del vidrio. No dejes la pantalla en una caja
cerrada sin ventilación durante horas.

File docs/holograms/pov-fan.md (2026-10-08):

# Ventilador holográfico (POV)

Ventilador POV

Aspas con tiras de LEDs que giran a 600-800 RPM; un controlador enciende cada
LED en el instante justo de cada vuelta y la persistencia de la visión
"pinta" una imagen que parece flotar en el aire, con mucha profundidad aparente.

**Dificultad:** fácil comprado, alta casero. **Costo:** US$ 60-150 / S/ 220-560
(25-65 cm). **Tiempo:** 1 hora (montaje).

## Materiales

| Material | Costo |
|---|---|
| Ventilador holográfico comercial de 30-65 cm con app o WiFi | US$ 60-150 / S/ 220-560 |
| Cúpula o carcasa protectora (muchos la traen) | US$ 10-30 / S/ 35-110 |
| Soporte de pared firme | US$ 5-15 / S/ 18-55 |

Casero: aspas impresas, tira APA102 (no WS2812: hace falta refresco rápido), un
ESP32, un sensor Hall con imán para sincronizar y un motor brushless con
variador. Es un proyecto avanzado por el equilibrado y la seguridad.

## Pasos (comercial)

1. Fija el soporte a la pared o a una base pesada y monta el ventilador con la
   protección puesta.
2. Exporta un video corto de la cara en formato cuadrado y fondo negro: graba
   la pantalla de `python -m gmini_pi --demo --windowed` (por ejemplo con OBS)
   o usa las imágenes de `docs/img/`.
3. Conviértelo con la herramienta del fabricante y súbelo por su app.
4. Para que reaccione en vivo: algunos modelos aceptan transmisión por WiFi o
   HDMI; si no, prepara un video por emoción y cámbialos desde el agente.

## Ventajas y desventajas

- Muy llamativo y brillante, se ve con luz ambiente.
- Imagen grande con poco espacio.
- Hace ruido, vibra y la integración en vivo depende del fabricante.
- Las aspas son peligrosas sin protección.

## Seguridad

Siempre con la cúpula o protección, fijación firme y fuera del alcance de
niños y mascotas. Ver [seguridad](../safety.md#ventiladores-pov-y-piezas-giratorias).

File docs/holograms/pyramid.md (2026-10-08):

# Pirámide de Pepper (4 caras)

Pirámide de Pepper

Cuatro trapecios transparentes forman una pirámide invertida apoyada sobre una
pantalla horizontal. Cada cara está a 45° y refleja una de las cuatro vistas
que muestra la pantalla; el observador ve la cara flotando dentro de la
pirámide, desde cualquiera de los cuatro lados.

**Dificultad:** muy fácil. **Costo:** US$ 1-25 / S/ 3-90. **Tiempo:** 15 min (PET) a 1 h (acrílico).

## Medidas

Plantillas listas para imprimir o cortar en [hardware/templates/](../../hardware/templates/README.md)
(SVG a escala 1:1 y DXF), para teléfono 6,1" y 6,7", tablets de 8", 10,1" y 11",
portátil de 15,6", monitores de 24" y 27" y TV de 32". Para otro tamaño:

- **b** (lado mayor) = 95 % del lado corto útil de la pantalla.
- **a** (lado menor) = b / 6.
- Altura de la pirámide = (b - a) / 2. Alto de cada trapecio = altura x 1,414.
- Los lados del trapecio forman 54,74° con la base.
- La imagen flotante mide como máximo la altura de la pirámide.

Ejemplo, teléfono de 6,1": b = 60 mm, a = 10 mm, trapecio de 35,4 mm de alto.

## Materiales

| Material | Para | Costo |
|---|---|---|
| Lámina PET o acetato 0,5 mm (tapa de carpeta, blíster transparente, caja de CD) | Teléfono y tablet | US$ 0-2 / S/ 0-8 |
| PETG o acrílico 2-3 mm | Monitor o TV | US$ 10-25 / S/ 35-90 por plancha |
| Cinta transparente o pegamento UV | Unir aristas | US$ 1-5 / S/ 3-20 |
| Opcional: marco impreso ([pepper_pyramid.scad](../../hardware/enclosures/pepper_pyramid.scad)) | Sin pegamento | ~10 g de PLA |

## Pasos

1. Imprime la plantilla al 100 % (sin "ajustar a la página") y comprueba la
   regla de 50 mm.
2. Lámina fina: pega la plantilla debajo, marca con cutter las líneas azules
   (pliegues) sin atravesar y corta las rojas. Dobla y cierra con la pestaña.
3. Acrílico: corta los cuatro trapecios del DXF de piezas (láser o sierra de
   calar), lija los cantos y únelos por fuera con cinta o pegamento UV. Las
   aristas quedan a 120°: un bisel de 30° en los cantos laterales mejora la
   unión.
4. En la pantalla abre la cara en disposición de pirámide:
   - Raspberry Pi o PC: `python -m gmini_pi --layout pyramid` (o
     `display.layout = "pyramid"`).
   - Tablet: `http://IP:8088/?layout=pyramid` (kiosco) o `?layout=pyramid&demo=1`.
5. Apoya la pirámide con la punta chica al centro de las cuatro vistas, apaga la
   luz y mira de frente a una de las caras, a la altura de la pirámide.

## Ventajas y desventajas

- Más barata imposible y se ve desde cuatro lados.
- Funciona con el celular que ya tienes.
- La imagen es chica (hasta la altura de la pirámide) y necesita poca luz.
- Las láminas gruesas dan imagen doble (reflejan ambas caras): usa la más
  fina que mantenga la forma.

## Seguridad

Cutter con regla metálica y corte hacia afuera del cuerpo. El acrílico astilla
al romperlo por la marca: lentes de protección.

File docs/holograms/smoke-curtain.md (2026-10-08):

# Cortina de humo y viento

Cortina de humo

Parecida a la pantalla de niebla, pero más grande: una máquina de humo
alimenta un túnel de viento con ventiladores y un difusor tipo panal, que
forma una lámina de humo vertical. Un proyector desde abajo o desde atrás pone
la cara sobre ella.

**Dificultad:** media. **Costo:** US$ 80-250 / S/ 300-950. **Tiempo:** un fin de semana.

## Materiales

| Material | Costo |
|---|---|
| Máquina de humo de 400-900 W con fluido | US$ 35-80 / S/ 130-300 |
| 4-6 ventiladores de PC de 12 V y una fuente de 12 V / 3 A | US$ 15-30 / S/ 55-110 |
| Caja de MDF o cartón pluma de 60-100 cm de largo | US$ 10-25 / S/ 35-95 |
| Panal de pajillas o malla de panal de abeja (honeycomb) | US$ 3-15 / S/ 10-55 |
| Proyector | US$ 40-150 / S/ 150-560 |

## Pasos

1. Arma un túnel largo y bajo; los ventiladores en la base soplan hacia arriba.
2. Cierra la salida superior con el panal (5-8 cm de profundidad) para que el
   aire salga parejo.
3. Conecta la salida de la máquina de humo a un costado del túnel.
4. Ajusta la velocidad de los ventiladores hasta que la lámina suba recta
   1-2 m; demasiado aire la rompe, muy poco la deja caer.
5. Proyecta la cara desde abajo en ángulo o desde atrás, en una sala oscura y
   sin corrientes.

## Ventajas y desventajas

- Tamaño de escenario y efecto espectacular.
- Consume fluido y la sala termina con humo: no es para todos los días.
- Las corrientes de aire la deforman.

## Seguridad

El fluido de glicol irrita y activa detectores de humo: ventila y avisa. El
hielo seco desplaza el oxígeno: nunca en espacios cerrados. No apuntes el
proyector a los ojos. Ver [seguridad](../safety.md#agua-niebla-y-humo-hologramas).

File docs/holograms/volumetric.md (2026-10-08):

# Volumétrica de barrido (espejo o pantalla giratoria)

Volumétrica

Una superficie (pantalla difusora o espejo inclinado) gira muy rápido mientras
un proyector de alta frecuencia dibuja en cada ángulo la "rebanada" de la imagen
3D que corresponde. El ojo integra todas las rebanadas: la cara ocupa un volumen
real y se ve en 3D desde cualquier lado, sin gafas.

**Dificultad:** muy alta (proyecto de investigación). **Costo:** US$ 100-400 /
S/ 375-1500. **Tiempo:** semanas.

## Materiales

| Material | Costo |
|---|---|
| Proyector DLP de alta frecuencia (kits de desarrollo DLP o un DMD reutilizado) | US$ 60-250 / S/ 220-940 |
| Motor brushless con variador y sensor de posición (encoder o Hall) | US$ 20-60 / S/ 75-225 |
| Superficie difusora rígida y liviana (acrílico esmerilado) | US$ 5-15 / S/ 18-55 |
| Cúpula de acrílico transparente | US$ 20-60 / S/ 75-225 |
| Microcontrolador para sincronizar motor y proyector | US$ 5-15 / S/ 18-55 |

## Pasos (resumen)

1. Monta la superficie centrada en el eje y equilíbrala con pesos hasta que no
   vibre a 600-1200 RPM.
2. Sincroniza la posición del motor con el proyector: cada cuadro se proyecta en
   un ángulo fijo (por ejemplo 100-200 rebanadas por vuelta).
3. Genera las rebanadas a partir de un modelo 3D de la cara (por ejemplo,
   extruyendo los ojos del motor como volúmenes) y envíalas al proyector.
4. Encierra todo en la cúpula antes de hacer girar el motor.

## Ventajas y desventajas

- Es la única técnica de la lista con volumen real.
- Requiere sincronización precisa, proyector especial y mucho ajuste.
- Imagen pequeña y tenue; el motor hace ruido.

## Seguridad

Superficie girando a alta velocidad: equilibrado, eje robusto y cúpula cerrada
siempre. Ver [seguridad](../safety.md#ventiladores-pov-y-piezas-giratorias).

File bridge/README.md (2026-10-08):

# Puente USB de G-Mini Home

Conecta la cara USB (Arduino Uno o Nano con OLED) con G-Mini Agent: reenvía el
estado del agente a la placa por el puerto serie y pone la voz con el
micrófono y los parlantes de la PC.

```bash
python -m venv .venv
.venv\Scripts\activate                 # Linux/macOS: source .venv/bin/activate
pip install -r requirements.txt
python gmini_serial_bridge.py --url http://127.0.0.1:8765 --pair 482913
```

Después del primer emparejamiento basta con `python gmini_serial_bridge.py`.
Opciones: `python gmini_serial_bridge.py --help`.

Guía completa: [docs/guides/usb-face.md](../docs/guides/usb-face.md).
Protocolo serie: [docs/serial-protocol.md](../docs/serial-protocol.md).

Requisitos: Python 3.11 o más nuevo; en Linux, `sudo apt install libportaudio2`.

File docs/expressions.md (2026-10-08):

# Expresiones de la cara

Las caras de todas las variantes (OLED, TFT, pygame, kiosco y anillo LED)
salen del mismo motor y de una única tabla: [`common/expressions.json`](../common/expressions.json).

Expresiones

Estados

## Cómo funciona el motor

- **Emoción** (campo `emotion` del protocolo) y **estado** (`status`) se
  combinan: la emoción define la forma de los ojos y el estado agrega
  comportamiento (escuchar agranda los ojos, pensar los entrecierra y mira
  arriba, trabajar barre la mirada de lado a lado, hablar muestra la boca).
- Todo cambio se interpola con suavizado exponencial (constante de tiempo de
  70 ms para la forma y 45 ms para la mirada): no hay saltos aunque el agente
  cambie de emoción varias veces por segundo.
- Parpadeo con curva de aceleración (70 ms cerrar, 35 ms cerrado, 110 ms
  abrir), cada 2-6 s al azar y a veces doble, como las personas.
- Movimientos de mirada ("sacadas") al azar en reposo.
- Los cambios de forma (corazones de `love`, cruces de `error`) ocurren con
  los ojos cerrados, en medio de un parpadeo.
- Después de 10 minutos en reposo los ojos se duermen; cualquier evento los
  despierta.
- Todo se calcula en un lienzo de referencia de 128 x 64 y cada pantalla lo
  escala.

Implementaciones: C++ en `firmware/libraries/GMiniEyes` (AVR, ESP32 y host),
Python en `common/gmini_link/face.py` y JavaScript en `kiosk/face.js`. Las
tres leen los presets generados desde el mismo JSON.

## Cambiar una expresión

1. Edita `common/expressions.json`. Por ejemplo, ojos alegres más "sonrientes":

   ```json
   "happy": { "h": 38, "dy": -1, "lid_bottom": 0.55, "bounce": 0.8 }
   ```

2. Regenera los presets y las hojas de referencia:

   ```bash
   python tools/codegen/gen_expressions.py
   python tools/diagrams/build_all.py
   ```

3. Vuelve a compilar el firmware. Las pruebas (`pytest` y
   `pio test -e native`) verifican que las salidas generadas estén al día y que
   los valores estén en rango.

| Campo | Rango | Efecto |
|---|---|---|
| `w`, `h`, `r` | px | Ancho, alto y radio de las esquinas de cada ojo |
| `gap`, `dy` | px | Separación entre ojos y desplazamiento vertical |
| `lid_top` | 0-1 | Párpado superior recto |
| `slant_in` / `slant_out` | 0-1 | Párpado inclinado hacia adentro (enojo) o hacia afuera (tristeza) |
| `lid_bottom` | 0-1 | Párpado inferior en arco (alegría) |
| `look_x`, `look_y` | -1..1 | Hacia dónde mira |
| `scale_l`, `scale_r` | | Tamaño relativo de cada ojo |
| `bounce`, `shake`, `pulse` | | Rebote, sacudida y latido |
| `blink`, `saccade` | [min, max] ms | Intervalos de parpadeo y de movimiento de mirada |
| `shape` | `round`, `heart`, `cross` | Forma del ojo |
| `accent` | bool | Usa el color de acento (rosa) en pantallas a color |

Los `aliases` permiten aceptar nombres extra (`curious` -> `surprised`).

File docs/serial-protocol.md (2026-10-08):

# Protocolo serie de la cara USB (versión 1)

Protocolo de texto por líneas entre la PC (puente) y una cara con
microcontrolador. Pensado para depurar a mano desde cualquier monitor serie.

- 115200 baudios, 8N1. Cada mensaje es una línea terminada en `\n` (se ignora `\r`).
- Texto en **ISO-8859-1** (Latin-1). El puente convierte desde UTF-8, cambia
  comillas tipográficas y guiones largos por sus equivalentes y descarta lo que
  no tiene representación (emojis).
- Longitud máxima de línea: 71 caracteres en el Uno/Nano. Una línea más larga
  se descarta y la placa responde `ERR:overflow`.
- Las órdenes desconocidas o con valores inválidos responden `ERR:unknown` o
  `ERR:value`; las válidas no responden nada (salvo `?` y `V`).
- Al abrir el puerto, el Uno/Nano se reinicia y saluda con `H:`. El puente
  reenvía el estado completo cada vez que detecta la placa.

## PC -> placa

| Orden | Ejemplo | Efecto |
|---|---|---|
| `S:<estado>` | `S:thinking` | Estado del agente: `idle`, `listening`, `thinking`, `acting`, `speaking` |
| `E:<emoción>` | `E:happy` | `neutral`, `happy`, `sad`, `surprised`, `angry`, `thinking`, `sleepy`, `love`, `error` (y los alias de `expressions.json`, p. ej. `curious`) |
| `T:<texto>` | `T:Son las 6` | Subtítulo bajo la cara (2 líneas de 21 caracteres). `T:` lo borra |
| `N:<título>\|<cuerpo>` | `N:Correo\|3 nuevos` | Tarjeta de aviso por 6 s |
| `L:<0-9>` | `L:7` | Nivel de audio: mueve la boca al hablar y agranda los ojos al escuchar |
| `G:<x>,<y>` | `G:-50,20` | Mirada manual (-100..100). `G:` vuelve a la automática |
| `K` | `K` | Parpadeo |
| `Z:<0\|1>` | `Z:1` | Dormir (1) o despertar (0) |
| `C:<0-255>` | `C:120` | Contraste de la OLED |
| `?` | `?` | Responde `OK` |
| `V` | `V` | Responde el saludo `H:` |

## Placa -> PC

| Mensaje | Significado |
|---|---|
| `H:gmini-usb-face;0.1.0;1` | Firmware, versión y versión del protocolo |
| `OK` | Respuesta a `?` |
| `B:<id>:down` | Botón presionado (id 1 = hablar, 2 = cancelar) |
| `B:<id>:up` | Botón soltado |
| `B:<id>:long` | Botón mantenido 1,5 s |
| `ERR:<código>` | `unknown`, `value` u `overflow` |
| `# ...` | Comentario de depuración: el puente lo ignora |

## Ejemplo de una sesión

```
<- H:gmini-usb-face;0.1.0;1
-> E:neutral
-> S:idle
-> T:Conectada a G-Mini
<- B:1:down
-> S:listening
-> L:3
-> L:6
<- B:1:up
-> S:thinking
-> E:happy
-> T:¡Claro! Son las seis y diez.
-> S:speaking
-> L:7
-> L:2
-> L:0
-> S:idle
```

## Implementación

- Placa: `firmware/libraries/GMiniEyes/src/GMiniSerialProto.*` (con pruebas
  nativas en `firmware/esp32-companion/test/test_eyes`).
- PC: `bridge/gmini_bridge/protocol.py` (pruebas en `tests/test_bridge.py`).

Los cambios dentro de la versión 1 son solo aditivos: una placa vieja ignora
órdenes nuevas con `ERR:unknown` y el puente sigue funcionando.

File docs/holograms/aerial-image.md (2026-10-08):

# Imagen aérea (retrorreflector + divisor de haz)

Imagen aérea

A diferencia de Pepper (imagen virtual detrás del vidrio), esta técnica forma
una **imagen real** delante del vidrio: la luz de la pantalla se refleja en un
divisor de haz, rebota en una lámina retrorreflectante (que devuelve cada rayo
por donde vino) y, al atravesar de nuevo el divisor, converge en el aire. La
cara queda flotando delante de todo y se puede "tocar".

**Dificultad:** media. **Costo:** US$ 30-70 / S/ 110-260. **Tiempo:** 2-3 horas.

## Materiales

| Material | Costo |
|---|---|
| Divisor de haz (vidrio o acrílico semiespejado 50/50, "vidrio de teleprompter") | US$ 15-40 / S/ 55-150 |
| Lámina retrorreflectante de microprismas (tipo señal de tránsito, gris o blanca) | US$ 10-25 / S/ 35-95 |
| Pantalla brillante (celular o tablet al máximo brillo) | la que tengas |
| Caja de cartón pluma negro | US$ 3-8 / S/ 10-30 |

## Pasos

1. Pon la pantalla boca arriba y el divisor de haz encima, a 45°.
2. Coloca la lámina retrorreflectante vertical, del lado hacia el que el
   divisor refleja la luz de la pantalla.
3. Mira a través del divisor desde el lado opuesto a la lámina: la cara aparece
   en el aire, delante del vidrio, a la misma distancia del divisor que la
   pantalla.
4. Ajusta distancias: cuanto más cerca está la pantalla del divisor, más cerca
   flota la imagen. Usa la cara con fondo negro y el brillo al máximo.

## Ventajas y desventajas

- Imagen real "tocable": ideal para interfaces sin contacto.
- Pierde mucha luz (cada paso por el divisor deja pasar la mitad): tenue.
- Ángulo de visión limitado; la imagen es algo borrosa con láminas baratas.

## Seguridad

Cantos del vidrio lijados o encintados.

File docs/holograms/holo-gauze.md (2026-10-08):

# Film holográfico o tul (holo-gauze)

Tul holográfico

Una lámina casi transparente (film de retroproyección "holográfico" o un tul
especial) tensada delante de un fondo negro recibe la imagen de un proyector.
Con la sala a oscuras, la lámina desaparece y queda solo la imagen suspendida:
es la técnica de los conciertos con artistas "en holograma".

**Dificultad:** media. **Costo:** US$ 30-150 / S/ 110-560 sin proyector.
**Tiempo:** 2-3 horas.

## Materiales

| Material | Costo |
|---|---|
| Film holográfico de retroproyección (transparente gris) por m² | US$ 20-60 / S/ 75-225 |
| *o* tul holográfico (holo-gauze) por m² | US$ 15-40 / S/ 55-150 |
| Marco de aluminio o PVC para tensar | US$ 10-30 / S/ 35-110 |
| Tela negra para fondo y paredes | US$ 10-30 / S/ 35-110 |
| Proyector de 2000 lúmenes o más | US$ 60-300 / S/ 225-1125 |

## Pasos

1. Tensa el film o el tul en el marco, sin arrugas (el film se pega sobre un
   acrílico o vidrio; el tul se tensa con resortes).
2. Fondo negro mate detrás, a 1-2 m, para que la lámina no se note.
3. Proyector: film de retroproyección, desde atrás; tul, desde adelante y algo
   arriba, para que el haz no deslumbre al público.
4. Proyecta la cara con fondo negro (`gmini_pi` en la PC del proyector). Todo
   lo negro desaparece; solo quedan los ojos.
5. Ilumina a las personas que estén "detrás" de la imagen desde los costados,
   sin que la luz toque la lámina.

## Ventajas y desventajas

- Escala de escenario y muy convincente para el público de frente.
- La lámina se ve si le da luz: exige control de la iluminación.
- Necesita un proyector brillante.

## Seguridad

No mires al haz del proyector. Fija bien el marco: una lámina grande hace
"vela" con el viento.

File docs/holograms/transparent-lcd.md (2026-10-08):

# LCD transparente

LCD transparente

Un panel LCD no emite luz: solo deja pasar o bloquea la luz de su
retroiluminación. Si se retiran la retroiluminación y el difusor, el panel se
vuelve una ventana que muestra la imagen sobre lo que haya detrás. Con una caja
de luz al fondo (o un objeto iluminado), la cara oscura "flota" sobre la
escena. Es la técnica de las vitrinas transparentes de las tiendas.

**Dificultad:** media-alta. **Costo:** US$ 0-60 / S/ 0-230 (un monitor viejo
sirve). **Tiempo:** 2-4 horas.

## Materiales

| Material | Costo |
|---|---|
| Monitor LCD viejo (mejor LED que CCFL) o panel con placa controladora HDMI | US$ 0-50 / S/ 0-190 |
| Caja de luz: tira LED blanca + acrílico opal, o un panel LED de techo | US$ 5-20 / S/ 18-75 |
| Guantes anticorte, lentes, destornilladores, espátulas plásticas | US$ 5-10 / S/ 18-38 |
| Alcohol isopropílico y secador de pelo | US$ 3-5 / S/ 10-18 |

## Pasos

1. Desenchufa el monitor y espera varios minutos (los CCFL tienen alta
   tensión). Ponte guantes y lentes.
2. Retira la carcasa y el marco metálico con cuidado: los flex del panel se
   cortan fácil.
3. Separa el panel LCD (vidrio con sus flex y placa) del bloque de
   retroiluminación: debajo hay láminas difusoras, prismáticas y el guía de luz.
   Retíralas todas; deja **solo el vidrio con sus dos polarizadores**.
4. Algunos paneles traen un polarizador trasero difusor (mate): si la imagen
   se ve lechosa, cámbialo por una lámina polarizadora transparente orientada
   igual que la original (marca la orientación antes de despegar). Despega con
   calor suave o alcohol isopropílico, **nunca con acetona**.
5. Reconecta la placa del panel a su controladora y monta el vidrio en un marco
   rígido, sin presionarlo.
6. Pon detrás una caja de luz o una escena iluminada. En un LCD
   transparente el blanco es transparente y el negro es opaco, así que invierte
   los colores: `display.invert = true` en el cliente de la Pi o
   `?invert=1` en la página de kiosco. Los ojos quedan oscuros sobre la escena.

## Ventajas y desventajas

- Mezcla la cara con objetos reales: la cara "habita" una vitrina.
- Reaprovecha un monitor viejo.
- Pierde mucho brillo: hace falta mucha luz detrás.
- Desarme delicado: un flex roto inutiliza el panel.

## Seguridad

Vidrio filoso, alta tensión en los CCFL y en sus inversores, mercurio en los
tubos, solventes inflamables. Ver [seguridad: LCD transparente](../safety.md#lcd-transparente).

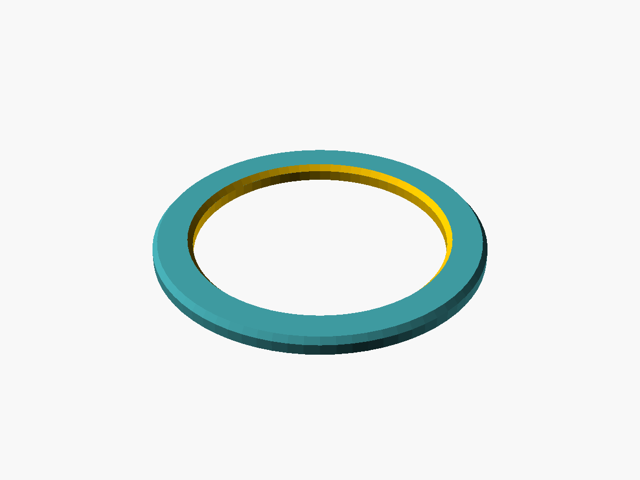
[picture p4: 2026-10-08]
hardware/renders/speaker_puck-diffuser.png

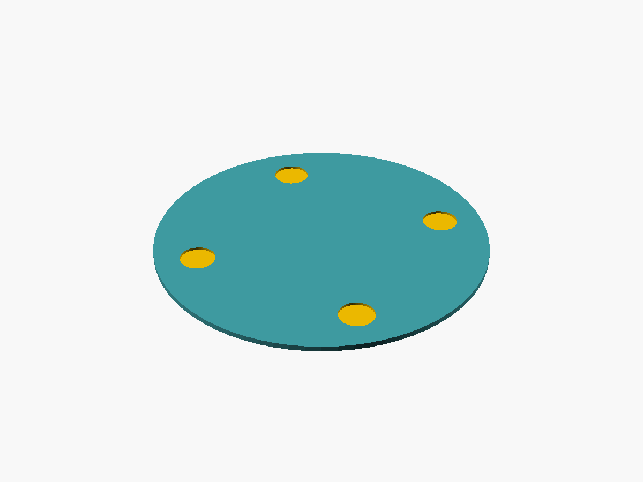
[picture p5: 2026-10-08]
hardware/renders/speaker_puck-bottom.png

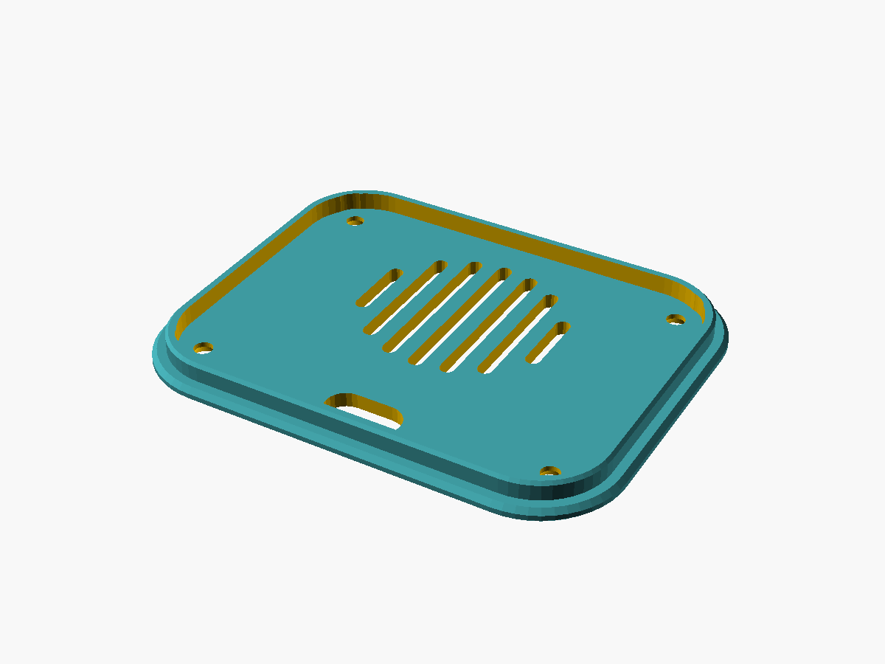
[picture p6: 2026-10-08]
hardware/renders/oled_companion-back.png

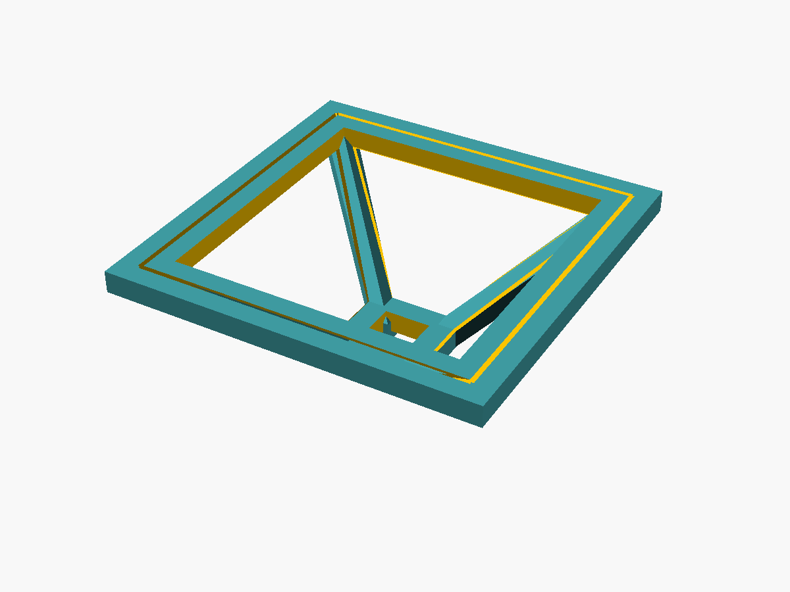
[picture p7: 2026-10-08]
hardware/renders/pepper_pyramid-frame.png

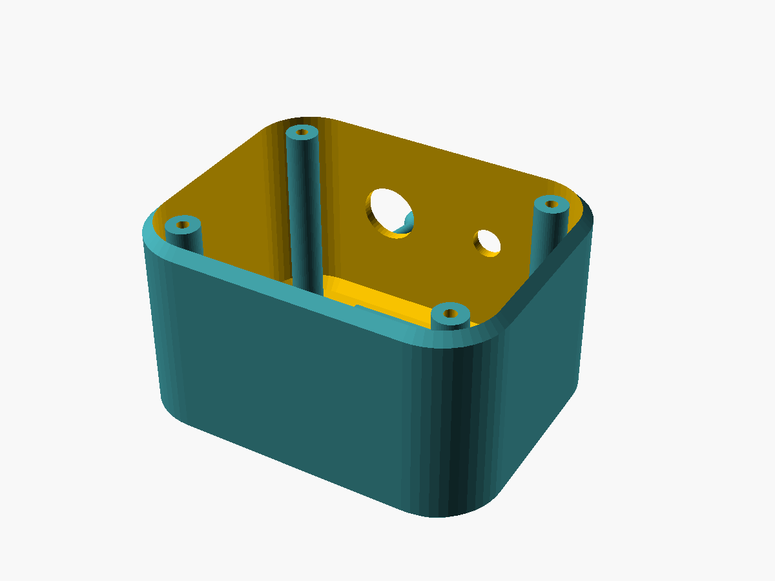
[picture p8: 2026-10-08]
hardware/renders/oled_companion-shell.png

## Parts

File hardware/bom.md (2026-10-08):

# Lista de materiales (BOM)

Precios referenciales de octubre de 2026 para piezas genéricas: **USD** en
tiendas en línea internacionales (envío aparte) y **PEN** en tiendas de
electrónica de Perú. Tipo de cambio usado para comparar: 1 USD ≈ S/ 3,75. Los
precios locales suelen ser más altos pero llegan el mismo día y aceptan
cambios; para un primer prototipo conviene comprar en local lo crítico (placa,
pantalla) y en línea lo barato (pulsadores, cables, tornillos).

La columna "Buscar como" es el término que mejor funciona en buscadores de
tiendas. Comprueba siempre la foto y los pines antes de pagar.

## Variante 1: cara USB (Arduino Uno o Nano)

| Pieza | Cant. | USD | PEN | Buscar como |
|---|---|---|---|---|
| Arduino Uno R3 (clon CH340) o Nano V3 | 1 | 4-7 | 22-40 | "arduino uno r3 ch340" / "arduino nano v3 type-c" |
| OLED 0,96" 128x64 I2C (SSD1306) | 1 | 2-3 | 15-20 | "oled 0.96 i2c ssd1306 4 pines" |
| Pulsadores 12x12 mm con capuchón | 2 | 0,5 | 2-4 | "pulsador tactil 12x12 capuchon" |
| Protoboard 400 puntos | 1 | 1,5-2 | 6-10 | "protoboard 400 puntos" |
| Cables dupont macho-macho y macho-hembra | 15 | 1-2 | 6-10 | "cables dupont 20 cm" |
| Cable USB de datos (no solo carga) | 1 | 1-2 | 5-10 | "cable usb b arduino" / "cable usb c datos" |
| **Total aproximado** | | **10-17** | **55-95** | sin carcasa |

Opcional: carcasa impresa ([oled_companion](enclosures/oled_companion.scad), ~45 g de PLA:
US$ 1-2 / S/ 5-10 de material) y 4 tornillos M2,5 x 8 autorroscantes.

## Variante 2: compañero WiFi (ESP32-S3 + OLED o pantalla a color)

| Pieza | Cant. | USD | PEN | Buscar como |
|---|---|---|---|---|
| ESP32-S3-DevKitC-1 N16R8 (16 MB flash, 8 MB PSRAM) | 1 | 6-9 | 45-65 | "esp32-s3 devkitc-1 n16r8" |
| OLED 0,96" I2C SSD1306 (o 1,3" SH1106) | 1 | 2-4 | 15-30 | "oled 0.96 ssd1306 i2c" / "oled 1.3 sh1106 i2c" |
| *o* pantalla ST7789 1,69" 240x280 SPI | 1 | 4-6 | 30-40 | "st7789 1.69 240x280 spi" |
| *o* pantalla redonda GC9A01 1,28" 240x240 | 1 | 4-6 | 30-40 | "gc9a01 1.28 round lcd" |
| Micrófono I2S INMP441 | 1 | 2-3 | 15-25 | "inmp441 i2s microfono" |
| Amplificador I2S MAX98357A | 1 | 2-4 | 18-30 | "max98357a i2s amplificador 3w" |
| Parlante 40 mm 4-8 ohm 3 W | 1 | 1-2 | 5-10 | "parlante 40mm 4 ohm 3w" |
| Pulsadores 12x12 mm | 2 | 0,5 | 2-4 | "pulsador tactil 12x12" |
| Anillo WS2812B 12-24 LEDs (opcional) | 1 | 3-6 | 20-35 | "ws2812b anillo 24 leds" |
| Resistencia 330 ohm + condensador 470-1000 uF (para el anillo) | 1 | 0,3 | 1-3 | "resistencia 330 ohm" "condensador 1000uf 16v" |
| Protoboard 830 puntos + cables dupont | 1 | 3-4 | 12-20 | "protoboard 830 puntos" |
| Fuente USB 5 V / 2 A + cable USB-C de datos | 1 | 4-6 | 15-30 | "cargador 5v 2a" "cable usb c datos" |
| **Total aproximado (OLED, sin anillo)** | | **20-30** | **115-185** | |

## Variante 3: parlante con LEDs (sin pantalla)

Igual que la variante 2 sin pantalla y con el anillo obligatorio:

| Pieza | Cant. | USD | PEN | Buscar como |
|---|---|---|---|---|
| ESP32-S3-DevKitC-1 N16R8 (o ESP32 DevKit V1, más barato y sin PSRAM) | 1 | 4-9 | 25-65 | "esp32-s3 devkitc-1 n16r8" / "esp32 devkit v1 30 pines" |
| INMP441 | 1 | 2-3 | 15-25 | "inmp441" |
| MAX98357A | 1 | 2-4 | 18-30 | "max98357a" |
| Parlante 40 mm 4 ohm 3-5 W | 1 | 1-3 | 5-15 | "parlante 40mm 4 ohm" |
| Anillo WS2812B 24 LEDs (66 mm) | 1 | 4-6 | 25-35 | "ws2812b ring 24" |
| Pulsadores 12x12 mm | 2 | 0,5 | 2-4 | |
| Patas de goma 10 mm | 4 | 0,5 | 2-4 | "patas de goma autoadhesivas 10mm" |
| Carcasa [speaker_puck](enclosures/speaker_puck.scad) (~110 g PLA + 6 g PETG natural) | 1 | 2-3 | 10-15 | |
| Fuente USB 5 V / 2 A | 1 | 4-6 | 15-30 | |
| **Total aproximado** | | **20-35** | **115-220** | |

## Variante 4: Raspberry Pi con pantalla

| Pieza | Cant. | USD | PEN | Buscar como |
|---|---|---|---|---|
| Raspberry Pi 4 (2 GB) / Pi 5 (4 GB) / Zero 2 W | 1 | 15-60 | 90-450 | "raspberry pi 4 2gb" / "raspberry pi zero 2 w" |
| Fuente oficial USB-C 5 V / 3 A (Pi 4) o 5 A (Pi 5) | 1 | 8-12 | 35-60 | "fuente raspberry pi 4 oficial" |
| microSD 32 GB clase A1 | 1 | 5-8 | 20-35 | "microsd 32gb a1" |
| Pantalla HDMI 7" 1024x600 (o SPI 3,5" para la Zero) | 1 | 15-40 | 70-250 | "pantalla 7 pulgadas hdmi raspberry" |
| Micrófono USB pequeño | 1 | 4-8 | 20-40 | "microfono usb mini" |
| Parlante USB o con jack 3,5 mm (Pi 4) | 1 | 6-12 | 30-60 | "parlante usb pequeño" |
| *o* altavoz manos libres USB (micrófono + parlante) | 1 | 15-25 | 80-150 | "speakerphone usb conferencia" |
| Pulsadores 12x12 + cables hembra-hembra | 2 | 1 | 4-8 | |
| **Total aproximado (Pi 4 + 7")** | | **75-140** | **330-650** | |

## Variante 5: PC vieja, mini PC o tablet

Sin compras obligatorias: el cliente de la Raspberry Pi corre en cualquier PC
con Linux o Windows, y la página de kiosco funciona en el navegador de una
tablet. Para voz en una tablet usa la PC o la Pi como "cerebro" y la tablet
solo como pantalla (estado por SSE).

## Hologramas

Costos de cada técnica en [docs/holograms/README.md](../docs/holograms/README.md).

## Herramientas

Cautín de 30-60 W con estaño 0,8 mm (si tus módulos vienen sin pines soldados),
multímetro básico, pelacables, cutter y regla metálica (pirámides), y acceso a
una impresora 3D (FDM, cama de 180 x 180 mm o más) para las carcasas.

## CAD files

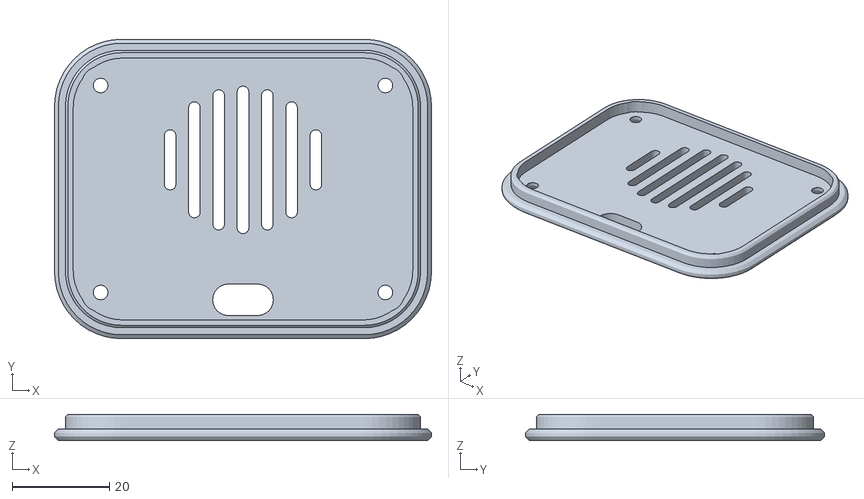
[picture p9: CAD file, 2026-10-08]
hardware/stl/oled_companion-back.stl
77.6 x 61.6 x 5.40

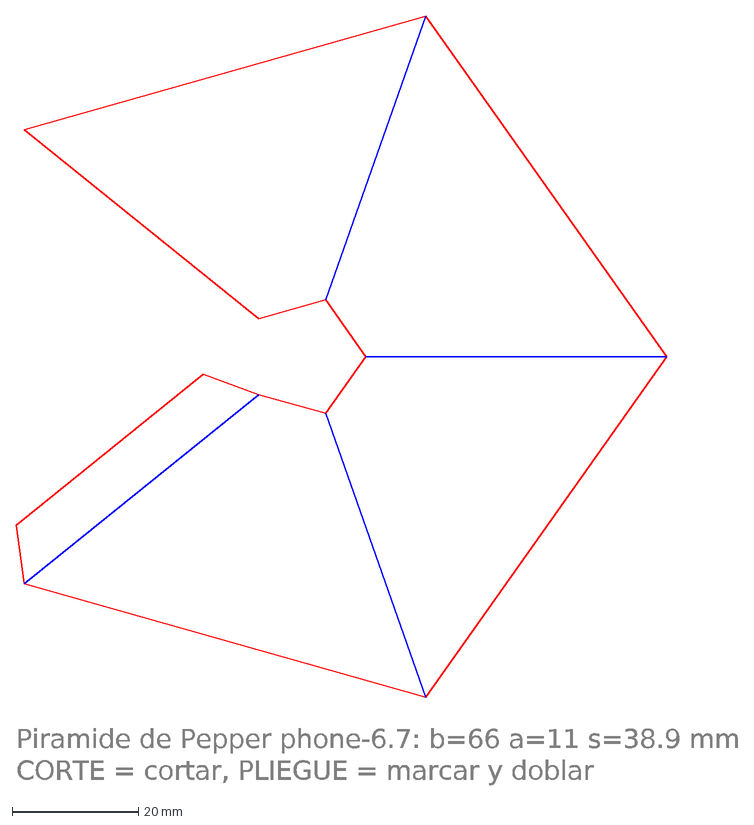
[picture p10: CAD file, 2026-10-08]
hardware/templates/pyramid-phone-6.7-net.dxf
Piramide de Pepper phone-6.7: b=66 a=11 s=38.9 mm
CORTE = cortar, PLIEGUE = marcar y doblar

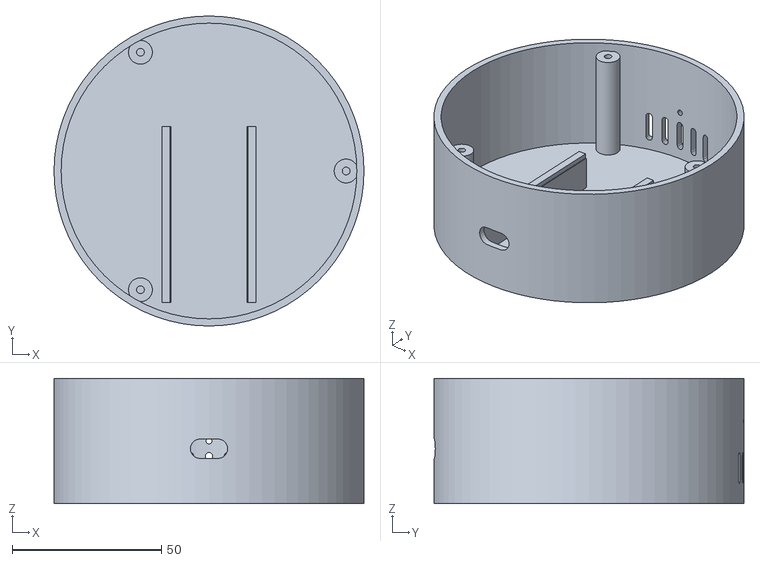
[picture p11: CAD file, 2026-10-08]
hardware/stl/speaker_puck-base.stl
104.0 x 104.0 x 42.0

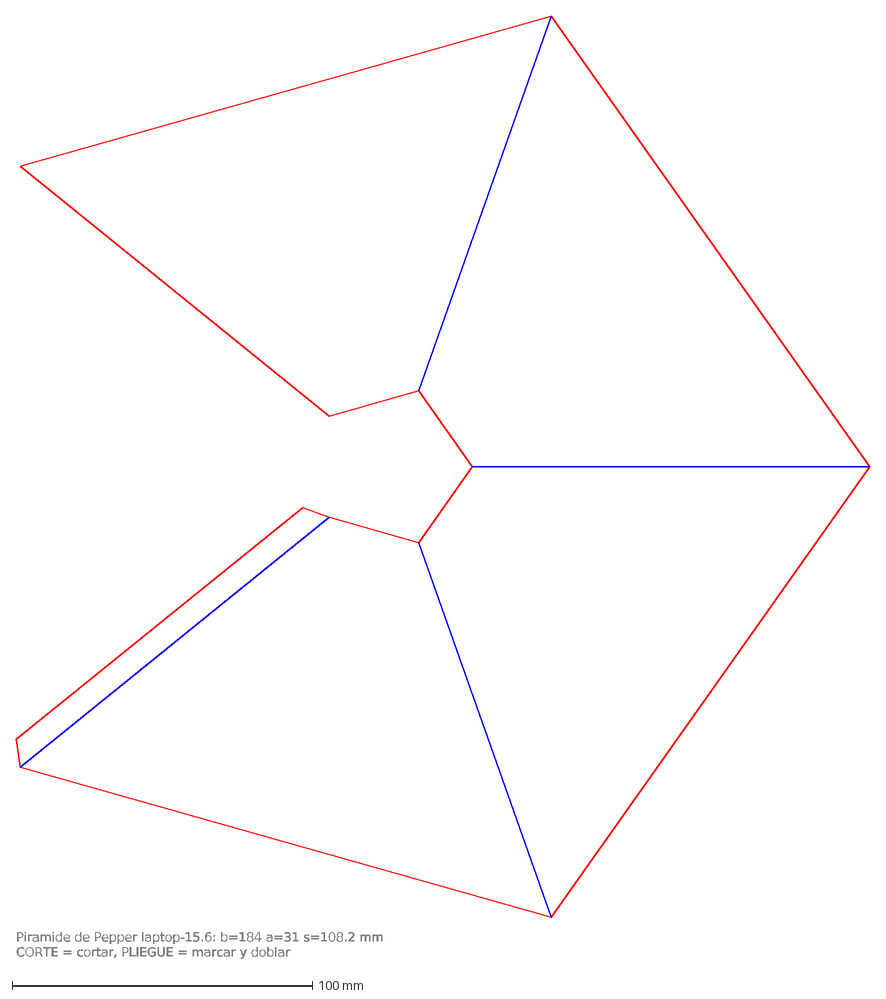
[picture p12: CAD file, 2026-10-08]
hardware/templates/pyramid-laptop-15.6-net.dxf
Piramide de Pepper laptop-15.6: b=184 a=31 s=108.2 mm
CORTE = cortar, PLIEGUE = marcar y doblar

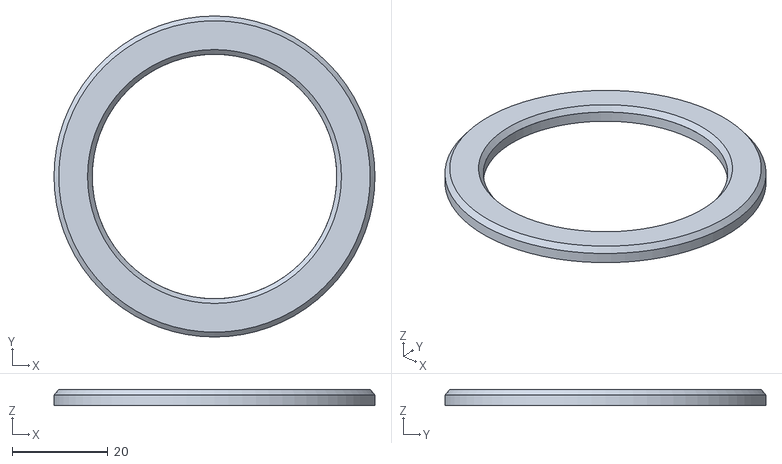
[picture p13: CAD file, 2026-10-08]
hardware/stl/speaker_puck-diffuser.stl
67.0 x 67.0 x 3.40

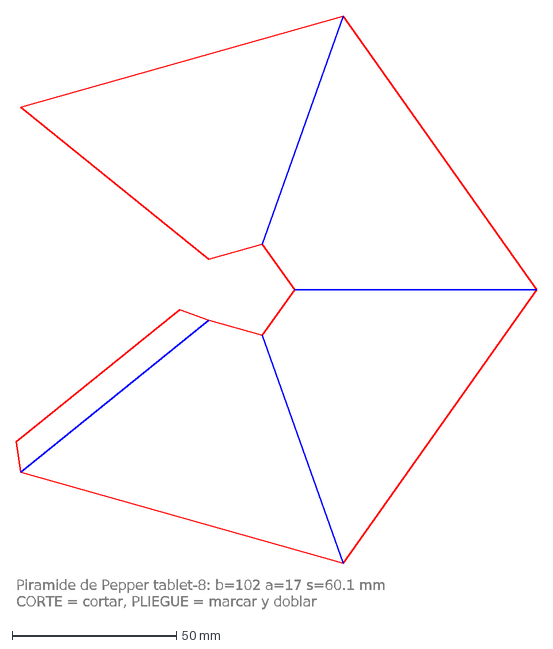
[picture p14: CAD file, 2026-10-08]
hardware/templates/pyramid-tablet-8-net.dxf
Piramide de Pepper tablet-8: b=102 a=17 s=60.1 mm
CORTE = cortar, PLIEGUE = marcar y doblar

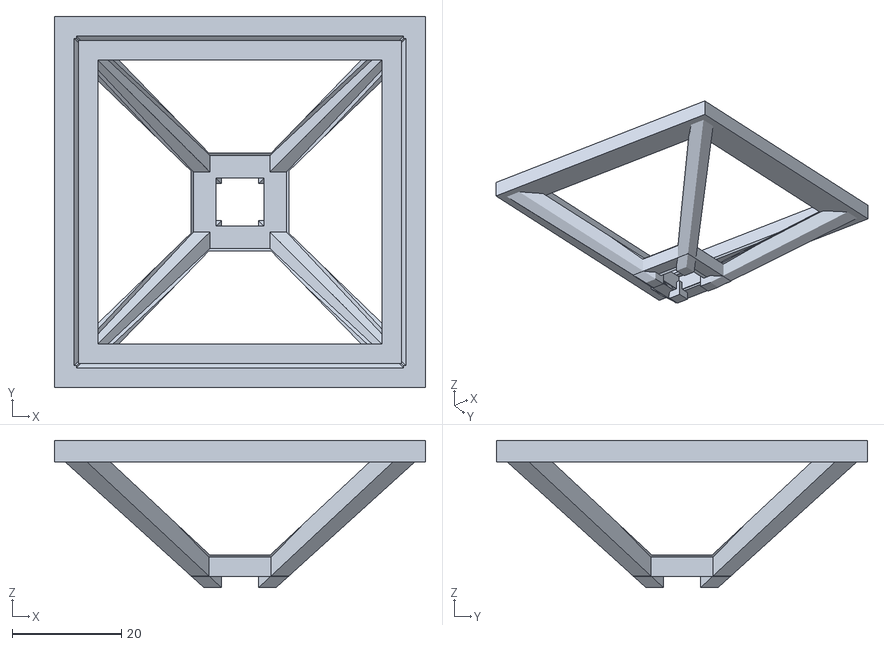
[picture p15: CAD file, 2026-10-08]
hardware/stl/pepper_pyramid-frame.stl
68.0 x 68.0 x 27.0

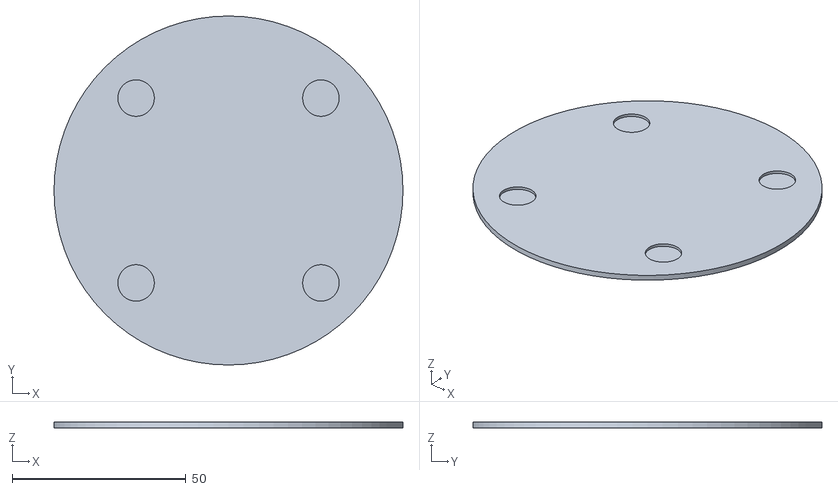
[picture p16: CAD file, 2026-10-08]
hardware/stl/speaker_puck-bottom.stl
100.4 x 100.4 x 1.60

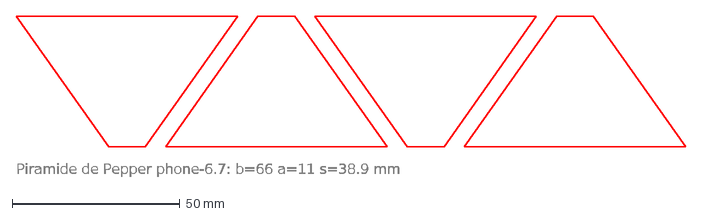
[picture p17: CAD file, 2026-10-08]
hardware/templates/pyramid-phone-6.7-pieces.dxf
Piramide de Pepper phone-6.7: b=66 a=11 s=38.9 mm

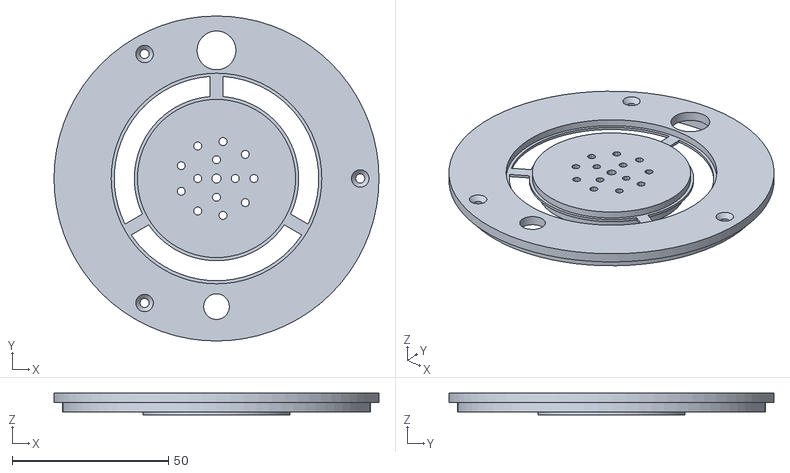
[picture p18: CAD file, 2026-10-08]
hardware/stl/speaker_puck-top.stl
104.0 x 104.0 x 7.00

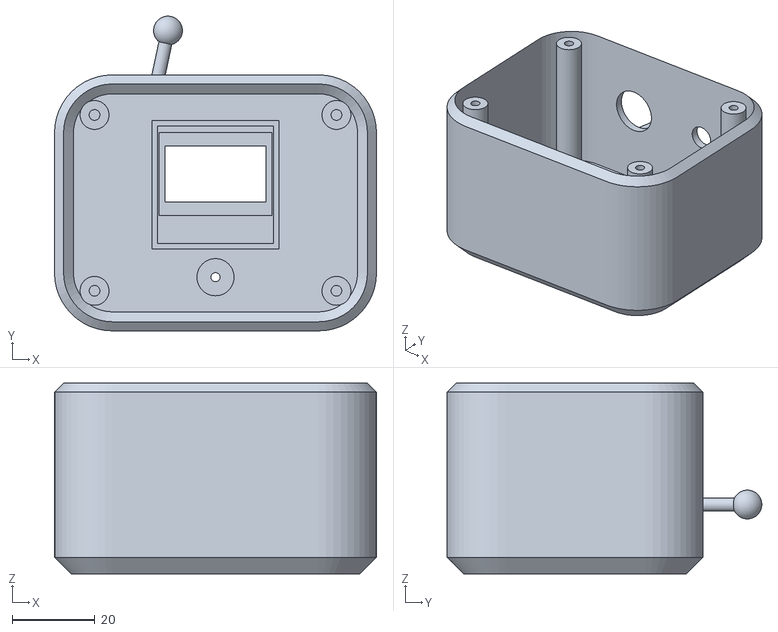
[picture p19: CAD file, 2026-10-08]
hardware/stl/oled_companion-shell.stl
78.0 x 76.2 x 46.2

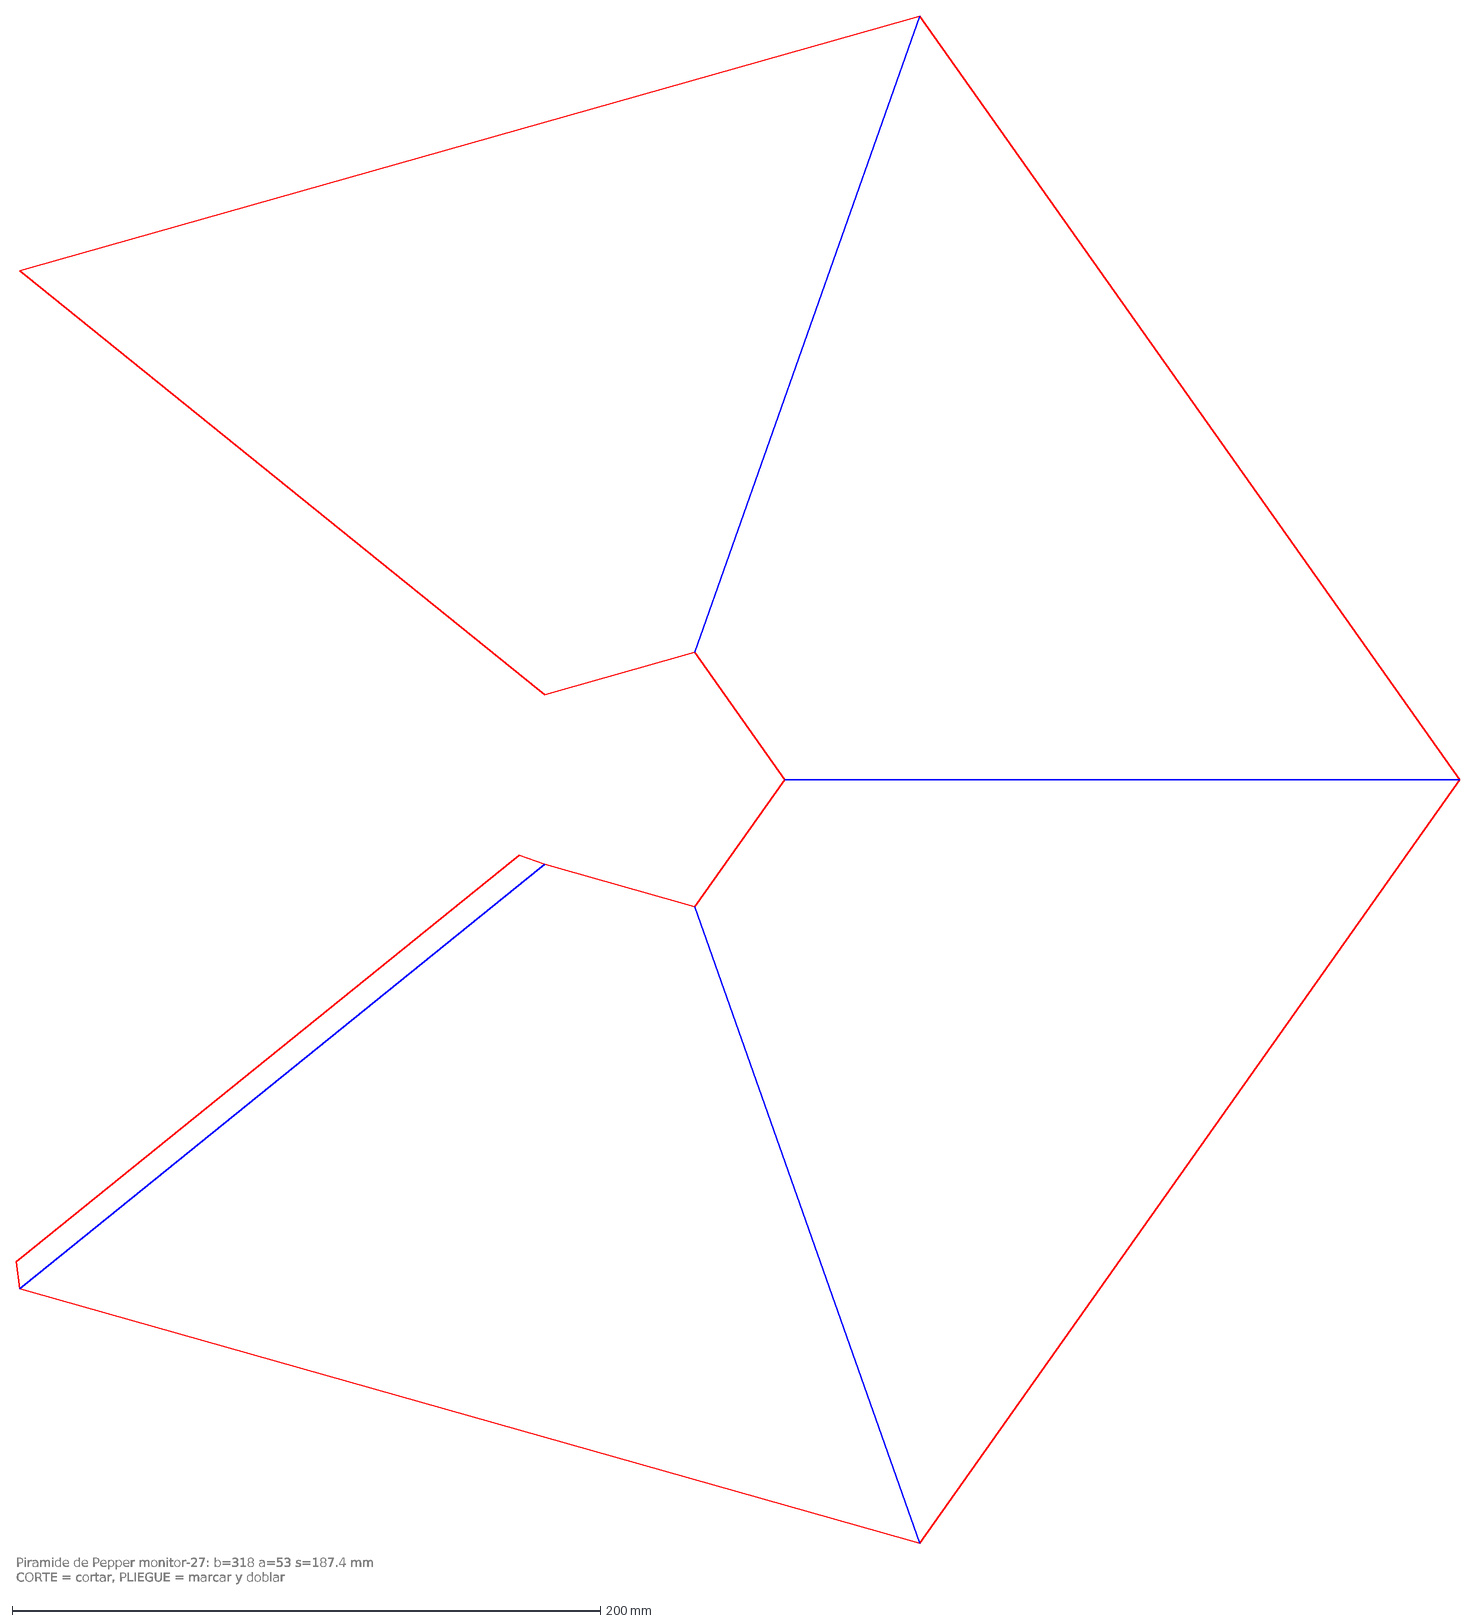
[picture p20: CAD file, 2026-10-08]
hardware/templates/pyramid-monitor-27-net.dxf
Piramide de Pepper monitor-27: b=318 a=53 s=187.4 mm
CORTE = cortar, PLIEGUE = marcar y doblar

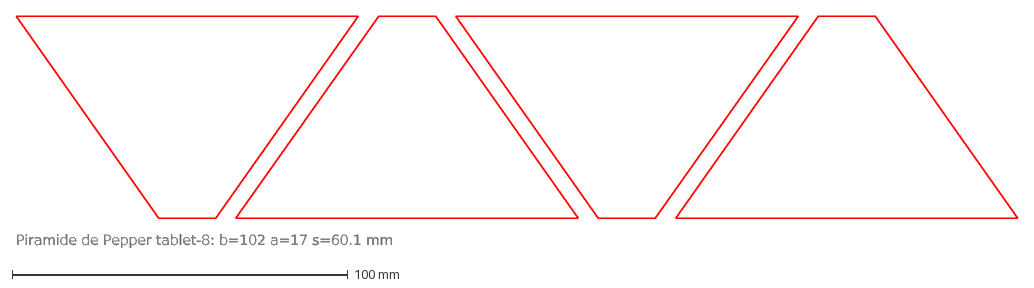
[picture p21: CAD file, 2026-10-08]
hardware/templates/pyramid-tablet-8-pieces.dxf
Piramide de Pepper tablet-8: b=102 a=17 s=60.1 mm

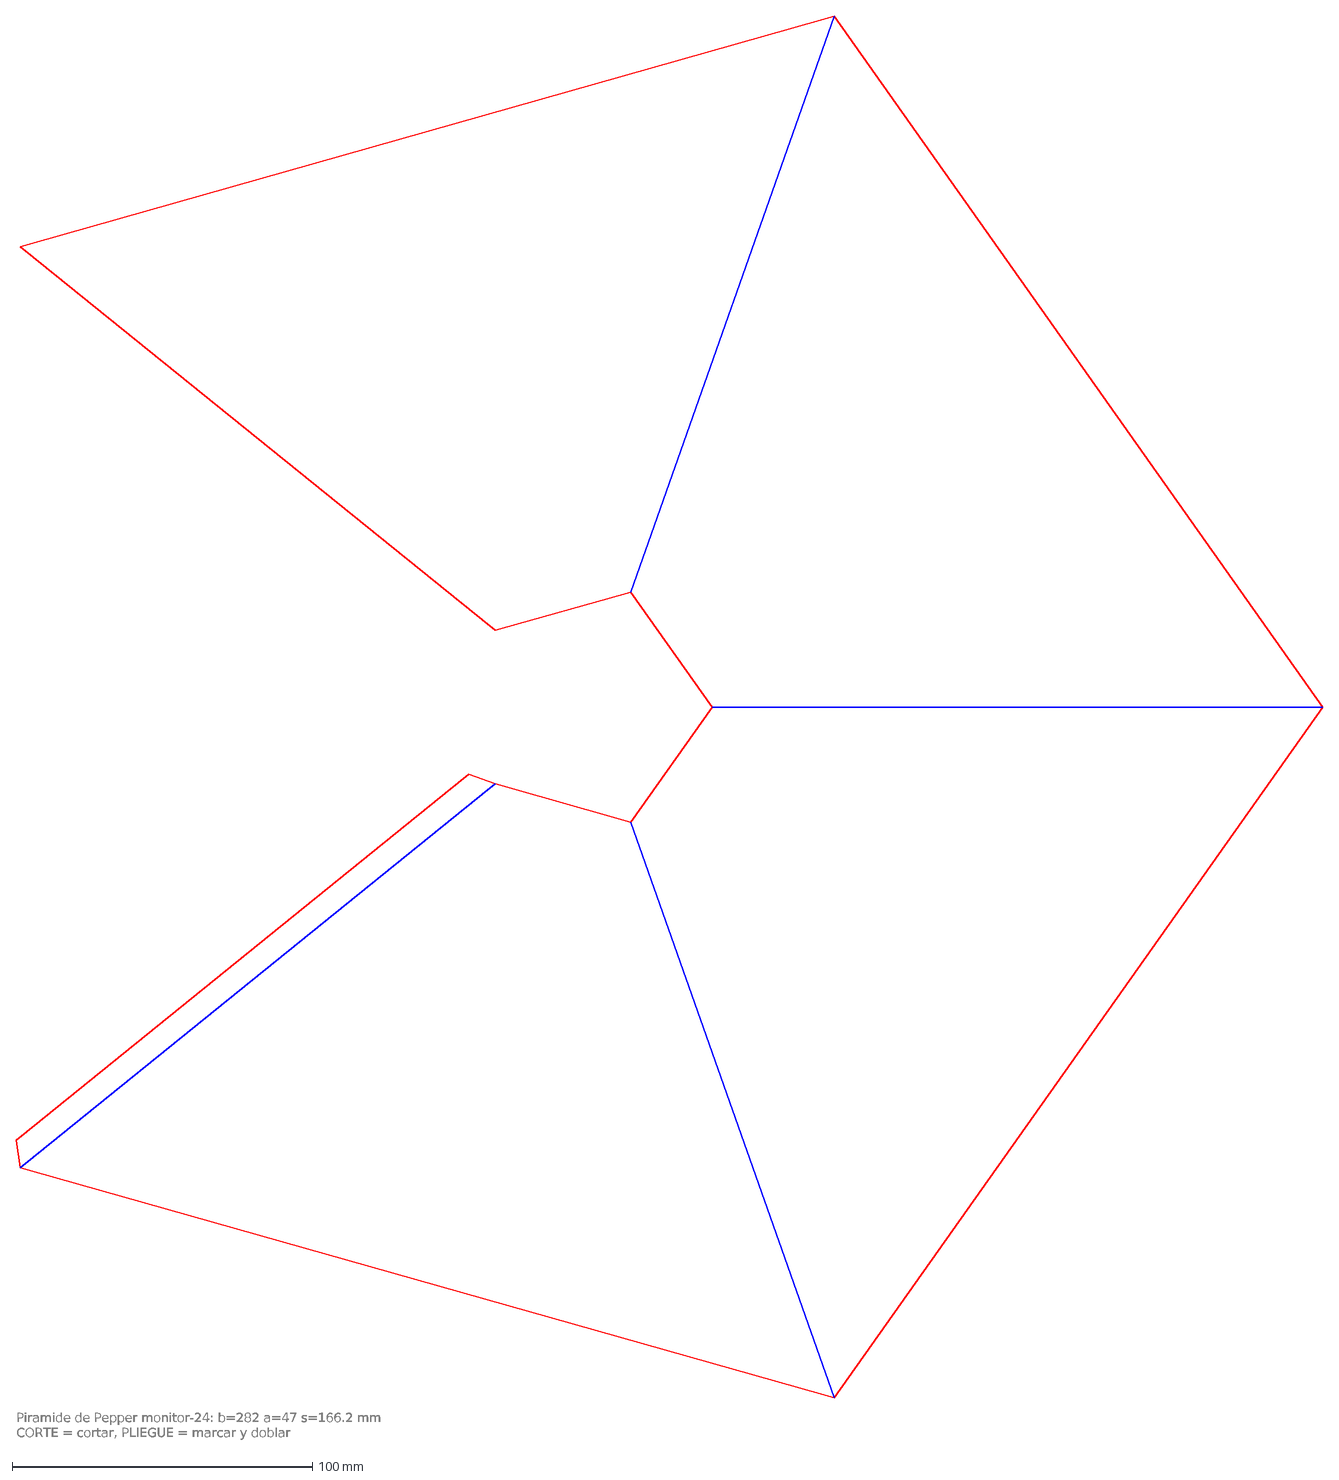
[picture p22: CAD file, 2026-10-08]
hardware/templates/pyramid-monitor-24-net.dxf
Piramide de Pepper monitor-24: b=282 a=47 s=166.2 mm
CORTE = cortar, PLIEGUE = marcar y doblar

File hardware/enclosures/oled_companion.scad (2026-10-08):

// G-Mini Home - carcasa del compañero OLED ("cabecita robot").
//
// Entra una OLED de 0,96" (o SH1106 de 1,3" cambiando oled_*), un ESP32-S3
// DevKitC-1 o un Arduino Nano, un INMP441, un MAX98357A, un parlante de 28-40 mm
// y dos pulsadores de 12 mm. Se imprime en dos piezas sin soportes:
//   part = "shell"    cuerpo con la ventana de los ojos (boca abajo sobre la cara)
//   part = "back"     tapa trasera con rejilla del parlante y salida USB
//   part = "assembly" vista de conjunto (solo para renders)
//
// Exportar:  openscad -D 'part="shell"' -o oled_companion_shell.stl oled_companion.scad
//
// Licencia: CC BY-SA 4.0 (ver LICENSE-hardware.md)

part = "assembly";            // [shell, back, assembly]

/* [Cuerpo] */
body = [78, 62, 48];          // ancho, alto, profundidad exteriores (mm)
corner_r = 14;                // radio de las esquinas vistas de frente
edge_r = 4;                   // redondeo de los cantos
wall = 2.2;

/* [OLED] */
oled_pcb = [27.6, 28.0];      // placa del modulo (mide la tuya)
oled_pcb_t = 1.7;             // espesor de la placa
oled_glass = [26.8, 19.6];    // vidrio
oled_glass_dy = 2.6;          // desplazamiento del vidrio hacia arriba respecto del centro de la placa
oled_window = [23.6, 12.6];   // abertura visible (zona activa de 21,7 x 10,9 + margen)
oled_center_z = 7;            // altura del centro de la pantalla sobre el centro del cuerpo

/* [Botones y audio] */
talk_d = 12.4;                // agujero del boton grande (capuchon de 12 mm)
mode_d = 6.6;                 // agujero del boton chico
mic_d = 2.2;
speaker_d = 40;               // parlante en la tapa trasera
usb = [12.5, 6.5];            // abertura USB-C / micro-USB en la tapa

/* [Tornillos] */
screw_d = 2.6;                // M2,5 autorroscante en el cuerpo
screw_head_d = 5.2;
boss_d = 7;

/* [Detalle] */
antenna = true;
$fn = 48;

eps = 0.01;
inner = [body[0] - 2 * wall, body[1] - 2 * wall];
lid_t = 2.4;
boss_inset = 7.5;

// Caja redondeada hecha con hull() de esferas y cilindros (rapida en CGAL).
module rounded_box(size, r, e) {
  hull() {
    for (x = [-1, 1], y = [-1, 1]) {
      translate([x * (size[0] / 2 - r), y * (size[1] / 2 - r), e])
        cylinder(r = r, h = size[2] - 2 * e);
      translate([x * (size[0] / 2 - r), y * (size[1] / 2 - r), 0])
        cylinder(r = r - e, h = size[2]);
    }
  }
}

module body_solid() {
  rounded_box([body[0], body[1], body[2]], corner_r, edge_r);
}

module cavity() {
  translate([0, 0, wall])
    rounded_box([inner[0], inner[1], body[2]], corner_r - wall, edge_r * 0.6);
}

module boss_positions() {
  for (x = [-1, 1], y = [-1, 1])
    translate([x * (inner[0] / 2 - boss_inset), y * (inner[1] / 2 - boss_inset), 0]) children();
}

// El cuerpo se modela con la cara apoyada en z = 0 (asi se imprime).
module shell() {
  difference() {
    union() {
      difference() {
        body_solid();
        cavity();
      }
      // Bosses para los tornillos de la tapa.
      boss_positions()
        translate([0, 0, wall - eps]) cylinder(d = boss_d, h = body[2] - wall - lid_t + eps);
      // Marco que sostiene la placa de la OLED contra la cara.
      translate([0, oled_center_z - oled_glass_dy, wall - eps])
        difference() {
          translate([-(oled_pcb[0] + 3.2) / 2, -(oled_pcb[1] + 3.2) / 2, 0])
            cube([oled_pcb[0] + 3.2, oled_pcb[1] + 3.2, oled_pcb_t + 2.2]);
          translate([-(oled_pcb[0] + 0.4) / 2, -(oled_pcb[1] + 0.4) / 2, -eps])
            cube([oled_pcb[0] + 0.4, oled_pcb[1] + 0.4, oled_pcb_t + 3]);
        }
    }
    // Ventana de los ojos con chaflan exterior.
    translate([0, oled_center_z, -eps])
      hull() {
        translate([-oled_window[0] / 2, -oled_window[1] / 2, 0]) cube([oled_window[0], oled_window[1], wall + 2 * eps]);
        translate([-(oled_window[0] + 2.4) / 2, -(oled_window[1] + 2.4) / 2, 0]) cube([oled_window[0] + 2.4, oled_window[1] + 2.4, eps]);
      }
    // Rebaje para el vidrio (queda al ras del interior de la cara).
    translate([-(oled_glass[0] + 0.6) / 2, oled_center_z - (oled_glass[1] + 0.6) / 2, wall - 0.8])
      cube([oled_glass[0] + 0.6, oled_glass[1] + 0.6, 1]);
    // Botones en la parte de arriba (lado +y).
    translate([-12, body[1] / 2 - wall / 2, body[2] * 0.55]) rotate([-90, 0, 0])
      cylinder(d = talk_d, h = wall * 3, center = true);
    translate([12, body[1] / 2 - wall / 2, body[2] * 0.55]) rotate([-90, 0, 0])
      cylinder(d = mode_d, h = wall * 3, center = true);
    // Microfono: agujero en la cara, abajo al centro, y "sonrisa" decorativa.
    translate([0, -body[1] / 2 + 13, -eps]) cylinder(d = mic_d, h = wall * 3);
    translate([0, -body[1] / 2 + 13, wall - 0.6]) cylinder(d = 9, h = 1);
    // Agujeros guia de los tornillos.
    boss_positions() translate([0, 0, wall + 3]) cylinder(d = screw_d, h = body[2]);
  }
  if (antenna) {
    translate([-14, body[1] / 2 - 1, body[2] * 0.35]) rotate([-90, 0, -12]) {
      cylinder(d = 3.2, h = 12);
      translate([0, 0, 12]) sphere(d = 7);
    }
  }
}

module back() {
  lip = 1.6;
  difference() {
    union() {
      translate([0, 0, 0]) rounded_box([body[0] - 0.4, body[1] - 0.4, lid_t], corner_r - 0.2, 0.8);
      // Pestaña que entra en el cuerpo y centra la tapa.
      difference() {
        rounded_box([inner[0] - 0.5, inner[1] - 0.5, lid_t + 3], corner_r - wall - 0.25, 0.5);
        translate([0, 0, -eps]) rounded_box([inner[0] - 0.5 - 2 * lip, inner[1] - 0.5 - 2 * lip, lid_t + 4], corner_r - wall - lip, 0.4);
        // Huecos de los bosses.
        boss_positions() translate([0, 0, -eps]) cylinder(d = boss_d + 1, h = lid_t + 4);
      }
    }
    // Rejilla del parlante: ranuras (mas livianas para CGAL que cientos de agujeros).
    for (i = [-3:3])
      translate([i * 5, 6, -eps])
        hull() {
          translate([0, -sqrt(max(1, pow(speaker_d / 2 - 3, 2) - pow(i * 5, 2))) + 3, 0]) cylinder(d = 2.4, h = lid_t + 5, $fn = 16);
          translate([0, sqrt(max(1, pow(speaker_d / 2 - 3, 2) - pow(i * 5, 2))) - 3, 0]) cylinder(d = 2.4, h = lid_t + 5, $fn = 16);
        }
    // USB.
    translate([0, -inner[1] / 2 + 6, -eps])
      hull() for (x = [-1, 1]) translate([x * (usb[0] - usb[1]) / 2, 0, 0]) cylinder(d = usb[1], h = lid_t + 5, $fn = 24);
    // Tornillos con avellanado.
    boss_positions() {
      translate([0, 0, -eps]) cylinder(d = screw_d + 0.4, h = lid_t + 5);
      translate([0, 0, -eps]) cylinder(d1 = screw_head_d, d2 = screw_d + 0.4, h = 1.6);
    }
  }
}

module oled_mock() {
  color("#1b5e8a") translate([-oled_pcb[0] / 2, -oled_pcb[1] / 2, 0]) cube([oled_pcb[0], oled_pcb[1], oled_pcb_t]);
  color("#05080a") translate([-oled_glass[0] / 2, oled_glass_dy - oled_glass[1] / 2, -1.2]) cube([oled_glass[0], oled_glass[1], 1.2]);
  // Ojos encendidos (dos rectangulos redondeados, como en la pantalla real).
  color("#3fe0ff") for (x = [-1, 1])
    translate([x * 5.6, oled_glass_dy, -1.6])
      hull() for (dx = [-1, 1], dy = [-1, 1]) translate([dx * 3.2, dy * 3.2, 0]) cylinder(r = 1.2, h = 0.4, $fn = 16);
}

if (part == "shell") {
  shell();
} else if (part == "back") {
  back();
} else {
  // Conjunto: cara hacia -y (la vista frontal de OpenSCAD) y la parte de arriba hacia +z.
  rotate([0, 0, 180]) rotate([90, 0, 0]) {
    color("#eef2f4") shell();
    translate([0, oled_center_z - oled_glass_dy, wall + 1.2]) oled_mock();
    color("#cfd8dd") translate([0, 0, body[2] + 6]) mirror([0, 0, 1]) back();
  }
}

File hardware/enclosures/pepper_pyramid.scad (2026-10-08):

// G-Mini Home - piramide de Pepper: marco imprimible y vista de conjunto.
//
// Las caras son laminas (PET o acrilico) cortadas con las plantillas de
// hardware/templates/. Este marco las sostiene a 45 grados sin pegamento:
//   part = "frame"    marco con ranuras (imprimir boca abajo, sin soportes)
//   part = "assembly" marco + laminas + pantalla (renders)
//
// Medidas por defecto: telefono de 6,1" (b = 60, a = 10). Para otra pantalla
// usa los valores de hardware/templates/README.md, p. ej. tablet de 10,1":
//   openscad -D b=128 -D a=21 -D sheet=0.75 -D 'part="frame"' -o marco.stl pepper_pyramid.scad
//
// Licencia: CC BY-SA 4.0 (ver LICENSE-hardware.md)

part = "assembly";            // [frame, assembly]

b = 60;                       // lado mayor (arriba)
a = 10;                       // lado menor (sobre la pantalla)
sheet = 0.5;                  // espesor de la lamina
slot_clear = 0.35;            // juego de la ranura
bar = 4;                      // ancho de las barras del marco
screen = [72, 152, 8];        // telefono de referencia para el render

$fn = 32;
eps = 0.01;
H = (b - a) / 2;              // altura (caras a 45 grados)

// Plano de una cara: trapecio inclinado 45 grados hacia afuera, del lado -y.
module face_plane(thick) {
  hull() {
    translate([-a / 2, -a / 2 - thick / 2, 0]) cube([a, thick, eps]);
    translate([-b / 2, -b / 2 - thick / 2, H]) cube([b, thick, eps]);
  }
}

// Ranura: la cara engrosada al espesor de la lamina mas el juego.
module slot() {
  face_plane(sheet + slot_clear);
}

module top_ring() {
  translate([0, 0, H - bar]) difference() {
    translate([-b / 2 - bar, -b / 2 - bar, 0]) cube([b + 2 * bar, b + 2 * bar, bar]);
    translate([-b / 2 + bar, -b / 2 + bar, -eps]) cube([b - 2 * bar, b - 2 * bar, bar + 2 * eps]);
  }
}

module bottom_ring() {
  difference() {
    translate([-a / 2 - bar, -a / 2 - bar, 0]) cube([a + 2 * bar, a + 2 * bar, bar]);
    translate([-a / 2 + 0.6, -a / 2 + 0.6, -eps]) cube([a - 1.2, a - 1.2, bar + 2 * eps]);
  }
}

// Aristas de la piramide: postes que unen los dos aros.
module edges() {
  for (r = [0, 90, 180, 270]) rotate(r)
    hull() {
      translate([-a / 2, -a / 2, 0]) cube([bar * 0.8, bar * 0.8, bar], center = true);
      translate([-b / 2, -b / 2, H - bar / 2]) cube([bar, bar, bar], center = true);
    }
}

module frame() {
  difference() {
    union() {
      top_ring();
      bottom_ring();
      edges();
    }
    for (r = [0, 90, 180, 270]) rotate(r) slot();
  }
}

module sheets() {
  for (r = [0, 90, 180, 270]) rotate(r) face_plane(sheet);
}

if (part == "frame") {
  frame();
} else {
  color("#1b2631") translate([-screen[0] / 2, -screen[1] / 2, -screen[2]]) cube(screen);
  color("#3fe0ff") for (r = [0, 90, 180, 270]) rotate(r) translate([-9, -a / 2 - H * 0.75, -0.2]) cube([18, 7, 0.3]);
  color("#e6eef2") frame();
  color("#bfefff", 0.35) sheets();
}

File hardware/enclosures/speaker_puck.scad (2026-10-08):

// G-Mini Home - "puck" parlante con ESP32-S3 y anillo de LEDs.
//
// Cilindro bajo con rejilla superior, anillo WS2812 de 24 LEDs bajo un aro
// difusor, dos botones arriba, microfono al frente y USB-C atras.
//   part = "base"     cuerpo con la cuna del ESP32-S3 DevKitC-1
//   part = "top"      tapa con rejilla del parlante y canal del difusor
//   part = "diffuser" aro difusor (PETG natural o PLA blanco, 100 % relleno)
//   part = "bottom"   fondo a presion con huecos para patas de goma de 10 mm
//   part = "assembly" vista de conjunto (renders)
//
// El INMP441 y el MAX98357A van pegados con cinta doble faz (no tienen
// agujeros de montaje). El anillo LED se pega bajo la tapa, centrado.
//
// Licencia: CC BY-SA 4.0 (ver LICENSE-hardware.md)

part = "assembly";            // [base, top, diffuser, bottom, assembly]

/* [Cuerpo] */
outer_d = 104;
height = 42;                  // alto del cuerpo (sin tapa)
wall = 2.4;
floor_t = 3.2;                // 1,6 mm de piso + 1,6 mm de rebaje para el fondo

/* [Parlante] */
speaker_d = 40;               // parlante de 40 mm, 3-5 W
speaker_mount_d = 44;         // aro donde apoya el parlante

/* [Anillo LED (24 LEDs: 66 / 52 mm)] */
ring_od = 66;
ring_id = 52;
diffuser_w = 8;

/* [Placa] */
board = [25.6, 69];           // ESP32-S3-DevKitC-1 (ancho, largo)
rail_h = 13;                  // alto de la cuna: los pines de los headers no tocan el fondo
ledge = 1.6;                  // escalon donde apoya la placa

/* [Botones y conectores] */
button_d = [12.4, 8.2];       // hablar, modo
usb = [12.5, 6.5];

$fn = 72;
eps = 0.01;
top_t = 3;
groove_d = 2.2;
r_out = outer_d / 2;
r_in = r_out - wall;
diff_r = (ring_od + ring_id) / 4;  // radio medio del anillo
board_y0 = -r_in + 1.5;            // extremo USB de la placa, contra la pared trasera
boss_r = r_in - 3.6;               // los bosses quedan unidos a la pared

module annulus(r1, r2, h) {
  difference() {
    cylinder(r = r2, h = h);
    translate([0, 0, -eps]) cylinder(r = r1, h = h + 2 * eps);
  }
}

module base() {
  difference() {
    union() {
      difference() {
        cylinder(r = r_out, h = height);
        translate([0, 0, floor_t]) cylinder(r = r_in, h = height);
      }
      // Bosses de la tapa a 120 grados, lejos de los botones (90 y 270 grados).
      for (a = [0, 120, 240]) rotate(a) translate([boss_r, 0, 0]) cylinder(d = 8, h = height - top_t);
      // Cuna de la placa: dos rieles con escalon.
      for (s = [-1, 1])
        translate([s * (board[0] / 2 + 1.5) - 1.5, board_y0 + 4, 0]) cube([3, board[1] - 10, floor_t + rail_h]);
    }
    for (a = [0, 120, 240]) rotate(a) translate([boss_r, 0, floor_t + 2]) cylinder(d = 2.6, h = height);
    // Escalon: la placa apoya a rail_h y queda trabada entre los rieles.
    translate([-board[0] / 2 - 0.3, board_y0, floor_t + rail_h - ledge]) cube([board[0] + 0.6, board[1], ledge + 1]);
    // USB-C atras (lado -y), a la altura del conector sobre la cuna.
    translate([0, -r_out + wall / 2, floor_t + rail_h + 2.2]) rotate([90, 0, 0])
      hull() for (x = [-1, 1]) translate([x * (usb[0] - usb[1]) / 2, 0, 0]) cylinder(d = usb[1], h = wall * 3, center = true, $fn = 24);
    // Microfono (INMP441 pegado por dentro, lado +y) y alivio del sonido.
    translate([0, r_out - wall / 2, height * 0.5]) rotate([90, 0, 0]) cylinder(d = 2, h = wall * 3, center = true, $fn = 16);
    // Ranuras de ventilacion/sonido en la parte baja del frente.
    for (i = [-2 : 2]) rotate(i * 7) translate([0, r_out - wall / 2, 8]) rotate([90, 0, 0])
      hull() for (z = [0, 8]) translate([0, z, 0]) cylinder(d = 2.4, h = wall * 3, center = true, $fn = 12);
    // Rebaje inferior donde encaja el fondo.
    translate([0, 0, -eps]) cylinder(r = r_in + 0.8, h = 1.6);
  }
}

module top() {
  difference() {
    union() {
      cylinder(r = r_out, h = top_t);
      // Pestaña que entra en el cuerpo.
      translate([0, 0, -3]) annulus(r_in - 2.1, r_in - 0.3, 3 + eps);
      // Aro de apoyo del parlante.
      translate([0, 0, -4]) annulus(speaker_mount_d / 2 - 0.8, speaker_mount_d / 2 + 1.5, 4 + eps);
    }
    // Rejilla sobre el parlante: anillos concentricos de agujeros.
    for (rr = [6 : 6 : speaker_d / 2 - 4])
      for (k = [0 : floor(2 * PI * rr / 8) - 1])
        rotate(k * 360 / floor(2 * PI * rr / 8)) translate([rr, 0, -eps]) cylinder(d = 2.6, h = top_t + 2 * eps, $fn = 12);
    translate([0, 0, -eps]) cylinder(d = 3, h = top_t + 1, $fn = 12);
    // Canal del difusor desde arriba...
    translate([0, 0, top_t - groove_d]) annulus(diff_r - diffuser_w / 2 - 0.2, diff_r + diffuser_w / 2 + 0.2, groove_d + eps);
    // ...y ventanas hacia el anillo LED, con tres rayos que sostienen el centro.
    difference() {
      translate([0, 0, -eps]) annulus(diff_r - diffuser_w / 2 + 0.8, diff_r + diffuser_w / 2 - 0.8, top_t);
      for (a = [90, 210, 330]) rotate(a) translate([0, -2, -1]) cube([r_out, 4, top_t + 2]);
    }
    // Botones entre el anillo y el borde.
    translate([0, r_out - 11, -eps]) cylinder(d = button_d[0], h = top_t + 2 * eps);
    translate([0, -(r_out - 11), -eps]) cylinder(d = button_d[1], h = top_t + 2 * eps);
    // Tornillos avellanados.
    for (a = [0, 120, 240]) rotate(a) translate([boss_r, 0, -eps]) {
      cylinder(d = 2.9, h = top_t + 1);
      translate([0, 0, top_t - 1.6 + 2 * eps]) cylinder(d1 = 2.9, d2 = 5.6, h = 1.6);
    }
  }
}

module diffuser() {
  annulus(diff_r - diffuser_w / 2, diff_r + diffuser_w / 2, groove_d);
  translate([0, 0, groove_d]) difference() {
    cylinder(r1 = diff_r + diffuser_w / 2, r2 = diff_r + diffuser_w / 2 - 1, h = 1.2);
    translate([0, 0, -eps]) cylinder(r1 = diff_r - diffuser_w / 2, r2 = diff_r - diffuser_w / 2 + 1, h = 1.2 + 2 * eps);
  }
}

module bottom() {
  difference() {
    cylinder(r = r_in + 0.6, h = 1.6);
    // Va a presion en el rebaje del cuerpo (o con tres puntos de pegamento).
    for (a = [0 : 90 : 270]) rotate(a + 45) translate([r_in - 12, 0, 0.8]) cylinder(d = 10.5, h = 1);
  }
}

if (part == "base") {
  base();
} else if (part == "top") {
  top();
} else if (part == "diffuser") {
  diffuser();
} else if (part == "bottom") {
  bottom();
} else {
  // Vista explotada.
  color("#e9eef1") base();
  color("#2b3a44") translate([0, 0, height + 12]) top();
  color("#7fe8ff") translate([0, 0, height + 12 + top_t - groove_d + 4]) diffuser();
  color("#c9d3da") translate([0, 0, -12]) bottom();
  color("#1b5e8a") translate([-board[0] / 2, board_y0, floor_t + rail_h - ledge]) cube([board[0], board[1], 1.6]);
  color("#0f2533") translate([0, r_out - 11, height + 12 + top_t]) cylinder(d = button_d[0] - 0.8, h = 3);
  color("#5b6b7b") translate([0, -(r_out - 11), height + 12 + top_t]) cylinder(d = button_d[1] - 0.8, h = 2);
}

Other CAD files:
hardware/templates/pyramid-monitor-27-pieces.dxf
hardware/templates/pyramid-monitor-24-pieces.dxf
hardware/templates/pyramid-tv-32-pieces.dxf
hardware/templates/pyramid-laptop-15.6-pieces.dxf
hardware/templates/pyramid-phone-6.1-net.dxf
hardware/templates/pyramid-phone-6.1-pieces.dxf
hardware/templates/pyramid-tablet-10-net.dxf
hardware/templates/pyramid-tablet-10-pieces.dxf
hardware/templates/pyramid-tablet-11-net.dxf
hardware/templates/pyramid-tablet-11-pieces.dxf
hardware/templates/pyramid-tv-32-net.dxf

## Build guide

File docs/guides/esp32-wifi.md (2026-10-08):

# Variante 2: compañero WiFi (ESP32-S3)

Un compañero independiente: escucha con su propio micrófono, habla por su
parlante y se conecta por WiFi a G-Mini. La cara puede ser una OLED de 0,96"
o 1,3", una ST7789 de 1,69" o una GC9A01 redonda de 1,28".

Cableado ESP32-S3 + OLED

**Dificultad:** media (soldar pines de los módulos). **Costo:** US$ 20-30 /
S/ 115-185 ([BOM](../../hardware/bom.md#variante-2-compañero-wifi-esp32-s3--oled-o-pantalla-a-color)).
**Tiempo:** 1,5-2 horas.

Antes de empezar: G-Mini tiene que ser accesible desde tu WiFi (modo servidor
o "Permitir conexiones" en todas las redes). Ver [conectar con G-Mini](../connect-gmini.md).

## 1. Cableado

Tabla completa en [hardware/wiring/esp32s3-oled.md](../../hardware/wiring/esp32s3-oled.md)
(pantalla a color: [esp32s3-tft.md](../../hardware/wiring/esp32s3-tft.md)).

| Función | GPIO | Notas |
|---|---|---|
| OLED SDA / SCL | 8 / 9 | 3,3 V |
| INMP441 SCK / WS / SD | 4 / 5 / 6 | VDD a 3,3 V, L/R a GND |
| MAX98357A BCLK / LRC / DIN | 15 / 16 / 7 | VIN a 5 V |
| Botón HABLAR / MODO | 17 / 18 | a GND |
| Anillo WS2812 | 47 | 5 V, 330 ohm en serie con DIN |
| Pantalla SPI SCL / SDA / CS / DC / RES / BLK | 12 / 11 / 10 / 13 / 14 / 21 | solo variantes TFT |
| Relés IN1 / IN2 | 39 / 40 | ver [relés](../../hardware/wiring/esp32s3-relays.md) |

No uses los GPIO 26-37 (flash y PSRAM octal del N16R8) ni 19/20 (USB nativo).
Todos los pines se pueden cambiar con `build_flags` (ver `include/config.h`).

Consejos de armado:

1. Primero solo la placa y la OLED: graba el firmware y comprueba que aparezcan
   los ojos. Después suma micrófono, amplificador y botones.
2. Cables cortos para el I2S (menos de 15 cm) y GND común para todo.
3. El amplificador consume picos de ~700 mA: alimenta con una fuente de 2 A.

## 2. Grabar el firmware

Opción A, binarios de la release (sin instalar nada): descarga
`gmini-home-esp32s3-oled-factory.bin` y grábalo en `0x0` con
[ESP Web Tool](https://espressif.github.io/esptool-js/) o con esptool:

```bash
pip install esptool
esptool.py --chip esp32s3 --port COM7 write_flash 0x0 gmini-home-esp32s3-oled-factory.bin
```

Opción B, compilar con PlatformIO:

```bash
pip install platformio
cd firmware/esp32-companion
pio run -e esp32s3-oled -t upload      # o esp32s3-sh1106, esp32s3-st7789, esp32s3-gc9a01
pio device monitor
```

Direcciones y entornos: [grabación del firmware](../flashing.md).

## 3. Configurar WiFi y emparejar

1. Al primer arranque la pantalla muestra **Configura tu G-Mini** con una red
   `G-Mini-Home-XXXX` (clave `gminihome`). Conéctate desde el celular; si no
   se abre solo, entra a `http://192.168.4.1`.
2. Elige tu WiFi y completa:
   - **Servidor G-Mini**: IP, nombre o URL (`192.168.1.50`, `http://tv-server:8765`).
   - **Código**: los 6 dígitos de Ajustes > Dispositivos, o pega el enlace
     `gmini://pair?...` completo (trae servidor y puerto).
   - **Nombre de este dispositivo**: cómo aparecerá en G-Mini.
3. Guarda. La placa se conecta, se empareja y muestra *Conectada a G-Mini*.

Volver a configurar: mantén **MODO** 3 s y suelta (o enciéndela con MODO
presionado). Borrar todo: mantén MODO 10 s.

## 4. Usarlo

- **HABLAR**: mantén presionado y habla; suelta para enviar. Suena un tono al
  empezar. La respuesta se reproduce mientras llega (no espera el audio entero).
- **MODO** (pulsación corta): corta la respuesta en curso y muestra la IP.
- Los ojos siguen el estado del agente aunque la conversación venga de otro
  dispositivo, y los avisos (`notify`) aparecen como tarjeta.
- Después de 10 minutos sin actividad los ojos se duermen; cualquier botón o
  mensaje los despierta.

### "Oye G-Mini" (opcional)

Por la consola serie: `activacion si`. El ESP32 detecta voz por energía y
manda frases cortas (menos de 4 s) a `/api/v1/voice/wake`; si empiezan con
"Oye G-Mini", atiende el pedido. Implica que **frases cortas de lo que se
dice cerca viajan a tu servidor G-Mini** (no a terceros). Desactívala con
`activacion no`.

## 5. Consola serie (115200 baudios)

| Comando | Qué hace |
|---|---|
| `estado` | WiFi, servidor, emparejamiento, memoria |
| `emparejar 482913` o `emparejar gmini://pair?...` | Empareja |
| `servidor 192.168.1.50:8765` | Cambia el servidor |
| `olvidar` | Borra el token (revócalo también en G-Mini) |
| `wifi` | Abre el portal |
| `activacion si/no`, `avisos-voz si/no` | Palabra de activación y avisos hablados |
| `volumen 0-100`, `brillo 0-255` | Ajustes de audio y pantalla |
| `cara happy`, `cara thinking` | Prueba expresiones y estados |
| `decir Hola` | Prueba la voz del servidor |
| `reiniciar`, `fabrica` | Reinicia o borra todo |

## 6. Lo que el agente puede usar

Al conectarse, el ESP32 se registra como nodo con estas superficies:

| Superficie | Ejemplo |
|---|---|
| `display.face` | `{"expression": "love", "text": "Te extrañé"}` |
| `display.text` | `{"text": "Reunión en 5 minutos", "seconds": 20}` |
| `led.set` | `{"color": "#ff8800", "effect": "breathe"}` (efectos: solid, breathe, blink, spin, rainbow, off, auto) |
| `relay.set` | `{"channel": 1, "on": true}` (pasa por las aprobaciones del agente) |
| `sensor.read` | `{"name": "chip_temp"}` (también `wifi_rssi`, `uptime`, `free_heap`, `light`) |
| `system.info` | firmware, IP, memoria y señal |
| `tts.speak` | `{"text": "Ya terminé el informe"}` |

## 7. Carcasa

[oled_companion.scad](../../hardware/enclosures/oled_companion.scad):
cabecita con ventana para la OLED, botones arriba, micrófono al frente y
parlante en la tapa trasera.

Carcasa del compañero OLED

Problemas comunes: [solución de problemas](../troubleshooting.md#esp32).

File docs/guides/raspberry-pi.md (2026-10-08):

# Variante 4: Raspberry Pi con pantalla

La cara a pantalla completa en cualquier resolución, con voz por micrófono y
parlante USB, botones en los GPIO y palabra de activación opcional. Corre como
servicio de systemd y arranca solo.

Cableado de la Raspberry Pi

**Dificultad:** fácil. **Costo:** US$ 75-140 / S/ 330-650 con Pi 4 y
pantalla de 7" ([BOM](../../hardware/bom.md#variante-4-raspberry-pi-con-pantalla)).
**Tiempo:** 1 hora.

Modelos probados por diseño: Pi 4 y Pi 5 (30-60 cuadros/s), Pi Zero 2 W
(20-24 cuadros/s con `supersample = 1`). Necesita Raspberry Pi OS Bookworm
(Python 3.11).

## 1. Preparar la Pi

1. Graba Raspberry Pi OS (Lite o con escritorio) con Raspberry Pi Imager,
   configurando WiFi, usuario y SSH.
2. Conecta la pantalla (HDMI, o una SPI con su controlador), el micrófono y
   el parlante USB.
3. Botones opcionales entre **GPIO17** (pin 11) y GND (pin 9), y **GPIO27**
   (pin 13) y GND.

## 2. Instalar

```bash
git clone https://github.com/angelgabrieljacintohuayllasco/G-Mini-Agent-Home.git
cd G-Mini-Agent-Home/raspberry-pi
sudo ./install.sh --url http://192.168.1.50:8765 --pair 482913
```

(O descarga el zip `gmini-pi` de la release y ejecuta su `install.sh`.)

El instalador:

- instala Python, PortAudio y SDL;
- copia el código a `/opt/gmini-home` con su propio entorno virtual;
- crea `/etc/gmini-home/config.toml` (no lo pisa al actualizar);
- guarda el token en `/var/lib/gmini-home` (solo lo lee el usuario del servicio);
- registra y arranca `gmini-pi.service`.

Con escritorio (X11/Wayland) agrega `--desktop`. Sin escritorio la cara se
dibuja directo con KMS/DRM.

```bash
systemctl status gmini-pi
journalctl -u gmini-pi -f
```

## 3. Configurar

`/etc/gmini-home/config.toml` (comentado en
[config.example.toml](../../raspberry-pi/config.example.toml)). Lo más usado:

| Clave | Para qué |
|---|---|
| `server.url` | Dirección de G-Mini |
| `display.layout` | `normal`, `mirror` (caja de Pepper) o `pyramid` (pirámide de 4 caras) |
| `display.rotate` | Pantalla montada de costado |
| `display.fps`, `display.supersample` | Fluidez contra consumo de CPU |
| `audio.input`, `audio.output` | Dispositivos (lista: `python -m gmini_pi --list-audio`) |
| `buttons.gpio_talk`, `buttons.gpio_cancel` | Pines BCM de los botones |
| `wake.mode` | `off`, `server` u `openwakeword` |
| `kiosk.enabled`, `kiosk.listen` | Página para tablets ([variante 5](kiosk.md)) |

Después de editar: `sudo systemctl restart gmini-pi`.

## 4. Usarla

- **Espacio** (teclado) o el botón de GPIO17: mantener para hablar.
- **C** o GPIO27: cancelar. **F**: pantalla completa. **Esc**: salir.
- Probar la pantalla sin servidor: `python -m gmini_pi --demo --windowed`.

## 5. Palabra de activación

- `wake.mode = "server"`: igual que en el ESP32, frases cortas viajan a tu
  G-Mini (`/voice/wake`), que decide si dijiste "Oye G-Mini". No necesita
  entrenar nada.
- `wake.mode = "openwakeword"`: detección local con
  [openWakeWord](https://github.com/dscripka/openWakeWord). Instala
  `/opt/gmini-home/venv/bin/pip install openwakeword`, entrena un modelo de
  "Oye G-Mini" con sus herramientas (o prueba con uno de los modelos en
  inglés que trae) y pon la ruta en `wake.model`. El audio no sale de la Pi
  hasta que se detecta la palabra.

## 6. Hologramas

Con `display.layout = "pyramid"` la pantalla muestra cuatro vistas giradas
para una [pirámide de Pepper](../holograms/pyramid.md); con `"mirror"` la cara
sale espejada para una [caja de Pepper](../holograms/pepper-box.md).

## 7. Desinstalar

```bash
sudo ./uninstall.sh            # conserva configuración y token
sudo ./uninstall.sh --purge    # borra todo
```

Revoca también el dispositivo en G-Mini.

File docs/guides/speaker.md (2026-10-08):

# Variante 3: parlante con LEDs (sin pantalla)

El "Alexa" de G-Mini: un cilindro con parlante, micrófono y un anillo de LEDs
que hace de cara. Mismo firmware que la variante 2, compilado sin pantalla.

Cableado del parlante

**Dificultad:** media. **Costo:** US$ 20-35 / S/ 115-220
([BOM](../../hardware/bom.md#variante-3-parlante-con-leds-sin-pantalla)).
**Tiempo:** 2 horas más la impresión de la carcasa (~6 h).

## 1. Qué expresa el anillo

| Estado | Anillo |
|---|---|
| Reposo | Respira muy suave en el color de la emoción |
| Escuchando | Encendido, el brillo sigue tu voz |
| Pensando | Un punto violeta que gira |
| Trabajando (acting) | Dos puntos ámbar girando rápido |
| Hablando | El brillo late con la voz |
| Aviso | Tres pulsos azules |
| Error | Rojo parpadeante |
| Configuración (portal) | Azul girando |
| Sin red o sin servidor | Destello ámbar cada 4 s |

El agente puede fijar un color y efecto con `led.set` (y volver al modo
automático con `{"effect": "auto"}`).

## 2. Armar

El cableado es el de la variante 2 sin la OLED
([tabla](../../hardware/wiring/esp32s3-speaker.md)). Detalles del anillo:

- Resistencia de 330 ohm en serie con DIN y un condensador de 470-1000 uF entre
  5 V y GND cerca del anillo (evita que el primer LED se queme al enchufar).
- El ESP32 da 3,3 V en DIN: con cables cortos funciona; si ves colores al azar,
  agrega un 74AHCT125 como adaptador de nivel.
- El firmware limita el brillo del anillo a la mitad: a pleno, 24 LEDs blancos
  piden ~1,4 A.

Con un **ESP32 clásico** (DevKit V1, sin PSRAM) usa el entorno
`esp32dev-speaker` y el [cableado del DevKit](../../hardware/wiring/esp32dev.md):
funciona igual pero las grabaciones duran como máximo 3 s y el botón MODO es
el botón BOOT de la placa.

## 3. Firmware y configuración

```bash
cd firmware/esp32-companion
pio run -e esp32s3-speaker -t upload      # o esp32dev-speaker
```

Sin pantalla, el portal se reconoce por el anillo azul girando: conéctate a
`G-Mini-Home-XXXX` (clave `gminihome`) y sigue los pasos de la
[variante 2](esp32-wifi.md#3-configurar-wifi-y-emparejar). La consola serie
es la misma.

Este es el formato ideal para la palabra de activación: `activacion si` desde
la consola. Lee la nota de privacidad en la [guía de la variante 2](esp32-wifi.md#oye-g-mini-opcional).

## 4. Carcasa

[speaker_puck.scad](../../hardware/enclosures/speaker_puck.scad): cuerpo con
cuna para el DevKitC-1 (los pines de los headers quedan en el aire), tapa con
rejilla y canal para el aro difusor, y fondo con patas de goma.

Carcasa del parlante

Orden de montaje:

1. Pega el anillo LED bajo la tapa, centrado en las ventanas, con los LEDs
   hacia arriba.
2. Atornilla o pega el parlante en el aro de la tapa.
3. Coloca la placa en la cuna con el USB-C hacia el agujero trasero.
4. Pega el INMP441 por dentro del frente, con su agujero frente al de la
   carcasa, y el MAX98357A con cinta doble faz.
5. Encastra el difusor en la tapa, cierra con 3 tornillos M2,5 x 8 y pon el
   fondo a presión.

Problemas comunes: [solución de problemas](../troubleshooting.md#esp32).

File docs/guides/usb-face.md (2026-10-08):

# Variante 1: cara USB (Arduino Uno o Nano)

La forma más barata y rápida: un Arduino con una OLED y dos botones,
conectado por USB a la PC donde corre G-Mini. El Arduino solo dibuja la cara;
el puente de Python (en la PC) recibe el estado del agente y usa el micrófono
y los parlantes de la PC para hablar.

Cableado de la cara USB

**Dificultad:** fácil (sin soldar si tu OLED trae pines). **Costo:** US$ 10-17 /
S/ 55-95 ([BOM](../../hardware/bom.md#variante-1-cara-usb-arduino-uno-o-nano)).
**Tiempo:** 30-45 minutos.

## 1. Armar en la protoboard

| OLED | Arduino |
|---|---|
| VCC | 5V (o 3V3 si tu módulo dice "3.3V only") |
| GND | GND |
| SCL | A5 |
| SDA | A4 |

Botón 1 (hablar) entre **D2** y **GND**; botón 2 (cancelar) entre **D3** y
**GND**. No hacen falta resistencias: el firmware activa el pull-up interno.
En el Nano los pines se llaman igual (A4, A5, D2, D3).

## 2. Grabar el sketch

Con arduino-cli (o abre `firmware/arduino-usb-face/arduino-usb-face.ino` en el
Arduino IDE y agrega la carpeta `firmware/libraries/GMiniEyes` como biblioteca
ZIP o cópiala a `Documentos/Arduino/libraries`):

```bash
arduino-cli core install arduino:avr
arduino-cli lib install U8g2
arduino-cli compile --fqbn arduino:avr:uno --library firmware/libraries/GMiniEyes firmware/arduino-usb-face
arduino-cli upload  --fqbn arduino:avr:uno -p COM5 firmware/arduino-usb-face
```

Para el Nano usa `--fqbn arduino:avr:nano` (o `arduino:avr:nano:cpu=atmega328old`
si la carga falla: muchos clones traen el bootloader viejo). Para una OLED de
1,3" (SH1106) agrega `--build-property "compiler.cpp.extra_flags=-DGMINI_OLED_SH1106=1"`.

Al encender verás dos ojos cian que parpadean y miran alrededor. Si abres el
monitor serie a 115200 baudios verás `H:gmini-usb-face;0.1.0;1`; escribe
`E:happy` y Enter para probar una emoción (ver [protocolo serie](../serial-protocol.md)).

Ocupa 29 300 bytes de flash (de 30 720 en el Nano) y 1 644 bytes de RAM.

## 3. Instalar el puente en la PC

Requisitos: Python 3.11 o más nuevo. Desde la raíz del repositorio (o desde la
carpeta del zip `gmini-bridge` de la release):

```bash
cd bridge
python -m venv .venv
.venv\Scripts\activate          # Linux/macOS: source .venv/bin/activate
pip install -r requirements.txt
```

En Linux instala también PortAudio: `sudo apt install libportaudio2`.

## 4. Emparejar y arrancar

Con G-Mini de escritorio en la misma PC tienes dos opciones:

```bash
# a) Token propio para el puente (recomendado: aparece en Dispositivos y se revoca aparte)
python gmini_serial_bridge.py --url http://127.0.0.1:8765 --pair 482913

# b) Token de sesión del escritorio (sin emparejar; solo en la misma PC)
python gmini_serial_bridge.py --session-token-file "C:/ruta/a/G-Mini-Agent/data/runtime/session_token"
```

El código sale de **Ajustes > Dispositivos > Este equipo**. Después del primer
emparejamiento basta con `python gmini_serial_bridge.py`: guarda el token en el
llavero del sistema (o en un archivo solo legible por tu usuario).

El puente busca la placa solo (Arduino, CH340, CP210x, FTDI). Si tienes varias,
elige el puerto con `--port COM5`; para listar: `--list-ports`.

## 5. Usarla

- Mantén presionado el **botón 1** y habla; suéltalo para enviar. La cara pasa
  por *escuchando*, *pensando* y *hablando* (con la boca siguiendo el audio).
- **Botón 2** corta la respuesta en curso.
- Cuando el agente trabaja en otra cosa (por ejemplo una tarea desde el
  celular), la cara muestra su estado igual.
- El agente puede cambiar la cara por su cuenta (superficie `display.face`) o
  mostrar un texto (`display.text`).

Opciones útiles: `--no-audio` (solo cara), `--mic` y `--speaker` (dispositivos
de `--list-audio`), `--wake` (activa "Oye G-Mini"; manda frases cortas a tu
G-Mini para detectarla) y `-v` (muestra el tráfico serie).

## 6. Carcasa

[oled_companion.scad](../../hardware/enclosures/oled_companion.scad) entra un
Nano, la OLED y los dos botones. Ver [hardware](../../hardware/README.md#carcasas).

Problemas comunes: [solución de problemas](../troubleshooting.md#cara-usb).

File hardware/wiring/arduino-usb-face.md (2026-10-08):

# Cableado: Arduino Uno / Nano por USB

La cara se conecta a la PC; el puente de Python pone la voz con el micrófono y los parlantes de la PC.

Arduino Uno / Nano por USB

| Módulo | Pin del módulo | Pin de la placa | Función |
|---|---|---|---|
| OLED 0,96" I2C | `VCC` | `5V` | 5 V |
| OLED 0,96" I2C | `GND` | `GND` | GND |
| OLED 0,96" I2C | `SCL` | `A5/SCL` | I2C SCL |
| OLED 0,96" I2C | `SDA` | `A4/SDA` | I2C SDA |
| Botones | `Botón 1 HABLAR` | `D2` | Botones |
| Botones | `Botón 2 CANCELAR` | `D3` | Botones |
| Botones | `Común` | `GND` | GND |

Notas:

- Los módulos OLED comunes aceptan 5 V (tienen regulador). Si el tuyo dice 3,3 V, usa 3V3.
- En el Nano los pines son los mismos: A4 = SDA, A5 = SCL, D2 y D3.

Guía paso a paso: [docs/guides/usb-face.md](../../docs/guides/usb-face.md). Seguridad: [docs/safety.md](../../docs/safety.md).

<!-- Generado por tools/diagrams/wiring.py: no editar a mano. -->

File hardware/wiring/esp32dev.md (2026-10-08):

# Cableado: ESP32 clásico (DevKit V1)

Versión económica sin PSRAM: grabaciones de hasta 3 s; la OLED es opcional.

ESP32 clásico (DevKit V1)

| Módulo | Pin del módulo | Pin de la placa | Función |
|---|---|---|---|
| INMP441 | `VDD` | `3V3` | 3,3 V |
| INMP441 | `GND` | `GND` | GND |
| INMP441 | `L/R` | `GND` | GND |
| INMP441 | `SCK` | `GPIO26` | I2S BCLK / SCK |
| INMP441 | `WS` | `GPIO25` | I2S WS / LRC |
| INMP441 | `SD` | `GPIO33` | I2S datos |
| MAX98357A | `VIN` | `VIN` | 5 V |
| MAX98357A | `GND` | `GND` | GND |
| MAX98357A | `DIN` | `GPIO13` | I2S datos |
| MAX98357A | `BCLK` | `GPIO27` | I2S BCLK / SCK |
| MAX98357A | `LRC` | `GPIO14` | I2S WS / LRC |
| OLED 0,96" I2C | `VCC` | `3V3` | 3,3 V |
| OLED 0,96" I2C | `GND` | `GND` | GND |
| OLED 0,96" I2C | `SCL` | `GPIO22` | I2C SCL |
| OLED 0,96" I2C | `SDA` | `GPIO21` | I2C SDA |
| Anillo WS2812 | `5V` | `VIN` | 5 V |
| Anillo WS2812 | `GND` | `GND` | GND |
| Anillo WS2812 | `DIN LED` | `GPIO18` | Datos LED |
| Botón HABLAR | `Botón HABLAR` | `GPIO4` | Botones |
| Botón HABLAR | `Común` | `GND` | GND |

Notas:

- VIN entrega los 5 V del USB: alimenta ahi el amplificador y el anillo.
- No uses GPIO12 para botones: decide el voltaje de la flash al arrancar.
- Anillo WS2812: Resistencia de 330 ohm en serie con DIN LED.
- Botón HABLAR: MODO = botón BOOT de la placa.

Guía paso a paso: [docs/guides/speaker.md](../../docs/guides/speaker.md). Seguridad: [docs/safety.md](../../docs/safety.md).

<!-- Generado por tools/diagrams/wiring.py: no editar a mano. -->

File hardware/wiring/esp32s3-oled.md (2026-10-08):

# Cableado: ESP32-S3 + OLED (variante WiFi)

Cara OLED, micrófono INMP441, amplificador MAX98357A, dos botones y anillo LED opcional.

ESP32-S3 + OLED (variante WiFi)

| Módulo | Pin del módulo | Pin de la placa | Función |
|---|---|---|---|
| INMP441 | `VDD` | `3V3` | 3,3 V |
| INMP441 | `GND` | `GND` | GND |
| INMP441 | `L/R` | `GND` | GND |
| INMP441 | `SCK` | `GPIO4` | I2S BCLK / SCK |
| INMP441 | `WS` | `GPIO5` | I2S WS / LRC |
| INMP441 | `SD` | `GPIO6` | I2S datos |
| MAX98357A | `VIN` | `5V` | 5 V |
| MAX98357A | `GND` | `GND` | GND |
| MAX98357A | `DIN` | `GPIO7` | I2S datos |
| MAX98357A | `BCLK` | `GPIO15` | I2S BCLK / SCK |
| MAX98357A | `LRC` | `GPIO16` | I2S WS / LRC |
| Botones | `Botón HABLAR` | `GPIO17` | Botones |
| Botones | `Botón MODO` | `GPIO18` | Botones |
| Botones | `Común` | `GND` | GND |
| OLED 0,96" I2C | `VCC` | `3V3` | 3,3 V |
| OLED 0,96" I2C | `GND` | `GND` | GND |
| OLED 0,96" I2C | `SCL` | `GPIO9` | I2C SCL |
| OLED 0,96" I2C | `SDA` | `GPIO8` | I2C SDA |
| Anillo WS2812 | `5V` | `5V` | 5 V |
| Anillo WS2812 | `GND` | `GND` | GND |
| Anillo WS2812 | `DIN LED` | `GPIO47` | Datos LED |

Notas:

- El INMP441 y la OLED van a 3,3 V; el amplificador y el anillo, a 5 V del USB.
- L/R del INMP441 a GND (canal izquierdo); el firmware detecta solo la ranura con señal.
- Entorno PlatformIO: esp32s3-oled (o esp32s3-sh1106 para pantallas de 1,3").
- MAX98357A: Parlante a los bornes + y - del módulo.
- Anillo WS2812: Resistencia de 330 ohm en serie con DIN LED.

Guía paso a paso: [docs/guides/esp32-wifi.md](../../docs/guides/esp32-wifi.md). Seguridad: [docs/safety.md](../../docs/safety.md).

<!-- Generado por tools/diagrams/wiring.py: no editar a mano. -->

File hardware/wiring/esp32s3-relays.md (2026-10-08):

# Cableado: ESP32-S3 + relés y sensor de luz

Superficies relay.set y sensor.read para domótica básica.

ESP32-S3 + relés y sensor de luz

| Módulo | Pin del módulo | Pin de la placa | Función |
|---|---|---|---|
| Módulo de 2 relés | `VCC` | `5V` | 5 V |
| Módulo de 2 relés | `GND` | `GND` | GND |
| Módulo de 2 relés | `IN1` | `GPIO39` | Relés |
| Módulo de 2 relés | `IN2` | `GPIO40` | Relés |
| LDR (opcional) | `AO` | `GPIO2` | Analógico |
| LDR (opcional) | `VCC` | `3V3` | 3,3 V |
| LDR (opcional) | `GND` | `GND` | GND |
- Módulo de 2 relés: Cargas de 220 V: ver docs/safety.md.

> **Tensión de red (220 V).** Desconecta la energía antes de tocar los bornes del relé. Usa caja cerrada, cable de sección adecuada y fusible. Si no tienes experiencia con 220 V, usa solo cargas de 5-12 V.

Guía paso a paso: [docs/guides/esp32-wifi.md](../../docs/guides/esp32-wifi.md). Seguridad: [docs/safety.md](../../docs/safety.md).

<!-- Generado por tools/diagrams/wiring.py: no editar a mano. -->

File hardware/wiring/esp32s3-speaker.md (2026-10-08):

# Cableado: ESP32-S3 parlante (sin pantalla)

La cara es el anillo de LEDs: respira en reposo, gira al pensar y late al hablar.

ESP32-S3 parlante (sin pantalla)

| Módulo | Pin del módulo | Pin de la placa | Función |
|---|---|---|---|
| INMP441 | `VDD` | `3V3` | 3,3 V |
| INMP441 | `GND` | `GND` | GND |
| INMP441 | `L/R` | `GND` | GND |
| INMP441 | `SCK` | `GPIO4` | I2S BCLK / SCK |
| INMP441 | `WS` | `GPIO5` | I2S WS / LRC |
| INMP441 | `SD` | `GPIO6` | I2S datos |
| MAX98357A | `VIN` | `5V` | 5 V |
| MAX98357A | `GND` | `GND` | GND |
| MAX98357A | `DIN` | `GPIO7` | I2S datos |
| MAX98357A | `BCLK` | `GPIO15` | I2S BCLK / SCK |
| MAX98357A | `LRC` | `GPIO16` | I2S WS / LRC |
| Botones | `Botón HABLAR` | `GPIO17` | Botones |
| Botones | `Botón MODO` | `GPIO18` | Botones |
| Botones | `Común` | `GND` | GND |
| Anillo WS2812 | `5V` | `5V` | 5 V |
| Anillo WS2812 | `GND` | `GND` | GND |
| Anillo WS2812 | `DIN LED` | `GPIO47` | Datos LED |

Notas:

- Alimenta con una fuente USB de 5 V / 2 A: anillo y amplificador suman picos de 1 A.
- Entorno PlatformIO: esp32s3-speaker.
- MAX98357A: Parlante a los bornes + y - del módulo.
- Anillo WS2812: Resistencia de 330 ohm en serie con DIN LED.

Guía paso a paso: [docs/guides/speaker.md](../../docs/guides/speaker.md). Seguridad: [docs/safety.md](../../docs/safety.md).

<!-- Generado por tools/diagrams/wiring.py: no editar a mano. -->

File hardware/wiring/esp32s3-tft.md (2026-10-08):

# Cableado: ESP32-S3 + pantalla a color

ST7789 de 1,69" o GC9A01 redonda de 1,28" por SPI, con el mismo audio que la variante OLED.

ESP32-S3 + pantalla a color

| Módulo | Pin del módulo | Pin de la placa | Función |
|---|---|---|---|
| INMP441 | `VDD` | `3V3` | 3,3 V |
| INMP441 | `GND` | `GND` | GND |
| INMP441 | `L/R` | `GND` | GND |
| INMP441 | `SCK` | `GPIO4` | I2S BCLK / SCK |
| INMP441 | `WS` | `GPIO5` | I2S WS / LRC |
| INMP441 | `SD` | `GPIO6` | I2S datos |
| MAX98357A | `VIN` | `5V` | 5 V |
| MAX98357A | `GND` | `GND` | GND |
| MAX98357A | `DIN` | `GPIO7` | I2S datos |
| MAX98357A | `BCLK` | `GPIO15` | I2S BCLK / SCK |
| MAX98357A | `LRC` | `GPIO16` | I2S WS / LRC |
| Botones | `Botón HABLAR` | `GPIO17` | Botones |
| Botones | `Botón MODO` | `GPIO18` | Botones |
| Botones | `Común` | `GND` | GND |
| Pantalla SPI | `VCC` | `3V3` | 3,3 V |
| Pantalla SPI | `GND` | `GND` | GND |
| Pantalla SPI | `SCL` | `GPIO12` | I2C SCL |
| Pantalla SPI | `SDA` | `GPIO11` | I2C SDA |
| Pantalla SPI | `RES` | `GPIO14` | Datos LED |
| Pantalla SPI | `DC` | `GPIO13` | Control (CS/DC/RST/BL) |
| Pantalla SPI | `CS` | `GPIO10` | Control (CS/DC/RST/BL) |
| Pantalla SPI | `BLK` | `GPIO21` | Datos LED |

Notas:

- Los pines SCL/SDA de estos módulos son SPI: SCL = reloj y SDA = datos (MOSI).
- Entornos PlatformIO: esp32s3-st7789 y esp32s3-gc9a01.

Guía paso a paso: [docs/guides/esp32-wifi.md](../../docs/guides/esp32-wifi.md). Seguridad: [docs/safety.md](../../docs/safety.md).

<!-- Generado por tools/diagrams/wiring.py: no editar a mano. -->

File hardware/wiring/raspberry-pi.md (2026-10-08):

# Cableado: Raspberry Pi: botones

Pantalla por HDMI o SPI y audio USB; los botones van a la cabecera GPIO.

Raspberry Pi: botones

| Módulo | Pin del módulo | Pin de la placa | Función |
|---|---|---|---|
| Botones | `Botón HABLAR` | `GPIO17` | Botones |
| Botones | `Botón CANCELAR` | `GPIO27` | Botones |
| Botones | `Común` | `GND` | GND |

Notas:

- Numeración BCM: GPIO17 es el pin físico 11 y GPIO27 el 13.
- Micrófono y parlante USB (o un parlante con micrófono por USB); la pantalla por HDMI.
- Configura los pines en /etc/gmini-home/config.toml ([buttons]).

Guía paso a paso: [docs/guides/raspberry-pi.md](../../docs/guides/raspberry-pi.md). Seguridad: [docs/safety.md](../../docs/safety.md).

<!-- Generado por tools/diagrams/wiring.py: no editar a mano. -->

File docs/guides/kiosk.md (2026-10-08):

# Variante 5: PC vieja, mini PC o tablet

Dos caminos según el equipo:

| Equipo | Qué usar | Voz |
|---|---|---|
| PC vieja o mini PC (Linux o Windows) | El cliente de la [Raspberry Pi](raspberry-pi.md) tal cual | Sí, con su micrófono y parlantes |
| Tablet o celular viejo | La página de kiosco en el navegador | No (la tablet solo muestra la cara) |

## PC vieja o mini PC

El cliente `gmini_pi` funciona en cualquier PC con Python 3.11:

```bash
cd raspberry-pi
python -m venv .venv
.venv/bin/pip install -r requirements.txt       # Windows: .venv\Scripts\pip ...
PYTHONPATH=../common .venv/bin/python -m gmini_pi --url http://IP:8765 --pair 482913
```

En Debian/Ubuntu también sirve `sudo ./install.sh --desktop`, que deja el
servicio de systemd configurado. Para arrancar en pantalla completa al
iniciar sesión en Windows, crea un acceso directo en `shell:startup` a
`pythonw -m gmini_pi` con la variable `PYTHONPATH` apuntando a `common`.

## Tablet: página de kiosco

La tablet no habla con G-Mini directamente: un cliente `gmini_pi` (en la Pi o
en una PC) le reenvía el estado de la cara por SSE. Así el token nunca llega al
navegador y no hay problemas de CORS ni del control de origen del núcleo.

1. En el equipo con `gmini_pi`, en `/etc/gmini-home/config.toml`:

   ```toml
   [kiosk]
   enabled = true
   listen = "0.0.0.0:8088"
   ```

   y reinicia el servicio. Con `0.0.0.0` cualquiera en tu red puede ver la cara
   **y los subtítulos** (que pueden incluir respuestas del agente). Déjalo en
   `127.0.0.1` si solo usas el navegador de ese mismo equipo.
2. En la tablet abre `http://IP-DEL-EQUIPO:8088` y toca **pantalla completa**
   (también pide mantener la pantalla encendida).
3. Opciones en la URL: `?layout=pyramid` o `?layout=mirror` para hologramas, y
   `?demo=1` para ver las expresiones sin servidor.

En Android, "Agregar a la pantalla principal" en Chrome la abre sin barras.
Para un kiosco dedicado, las apps tipo "Fully Kiosk Browser" bloquean la
tablet en esa página.

La página es HTML, CSS y JavaScript sin dependencias
([kiosk/](../../kiosk/)): usa el mismo motor de ojos que el resto, generado
desde `common/expressions.json`.

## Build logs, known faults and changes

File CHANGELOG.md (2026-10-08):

# Cambios

Formato basado en [Keep a Changelog](https://keepachangelog.com/es-ES/1.1.0/);
el proyecto sigue [versionado semántico](https://semver.org/lang/es/).

## [Sin publicar]

## [0.1.1] - 2026-10-08

### Cambiado

- Firmware ESP32 0.1.1: el portal WiFi queda entero en español. Los menús, botones y mensajes
  de WiFiManager usan una traducción propia (`include/gmini_wm_strings_es.h`).

## [0.1.0] - 2026-10-08

Primera versión.

### Agregado

- Motor de ojos compartido (`GMiniEyes`) con nueve emociones y cinco estados,
  parpadeo natural, movimientos de mirada, sueño automático y transiciones
  suaves; presets generados desde `common/expressions.json` para C++, Python y
  JavaScript, con pruebas en el host.
- Firmware WiFi para ESP32-S3 y ESP32 clásico (PlatformIO, 7 entornos): OLED
  SSD1306/SH1106, TFT ST7789 y GC9A01, variante sin pantalla con anillo
  WS2812; portal cautivo, emparejamiento con código o enlace `gmini://`, token
  en NVS, sesión WebSocket con superficies de nodo, pulsar para hablar con
  INMP441 y MAX98357A, reproducción en flujo y palabra de activación por el
  servidor.
- Biblioteca `GMiniLink`: HTTP, JSON, base64 y WAV en flujo, enlaces de
  emparejamiento y detector de voz, con pruebas en el host.
- Sketch para Arduino Uno y Nano con protocolo serie documentado (29 300 bytes
  de flash).
- Biblioteca Python `gmini_link`: cliente de la Remote API v1, sesión
  WebSocket con reconexión, almacén de tokens, WAV, detector de voz y flujos de
  voz compartidos.
- Puente USB (`bridge/`) con detección automática del puerto y voz por la PC.
- Cliente de pantalla (`raspberry-pi/`) con pygame, disposiciones normal,
  espejo y pirámide, colores invertidos para LCD transparente, botones GPIO,
  openWakeWord opcional, instalador y servicio systemd.
- Página de kiosco para tablets con el estado por SSE.
- Hardware: BOM con precios en USD y PEN, diagramas y tablas de cableado
  generados, carcasas OpenSCAD con STL y renders, y plantillas de corte de la
  pirámide de Pepper para nueve pantallas.
- Documentación en español: guías de las cinco variantes, diez técnicas de
  hologramas, seguridad, solución de problemas y preguntas frecuentes.
- CI (firmware, pruebas, archivos generados y OpenSCAD) y release por etiqueta.

[Sin publicar]: https://github.com/angelgabrieljacintohuayllasco/G-Mini-Agent-Home/compare/v0.1.1...HEAD
[0.1.1]: https://github.com/angelgabrieljacintohuayllasco/G-Mini-Agent-Home/releases/tag/v0.1.1
[0.1.0]: https://github.com/angelgabrieljacintohuayllasco/G-Mini-Agent-Home/releases/tag/v0.1.0

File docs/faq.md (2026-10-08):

# Preguntas frecuentes

**¿Qué es G-Mini Home?**
El compañero físico de G-Mini Agent: una carita que escucha y responde. El
"cerebro" (el agente, la memoria, las tareas y el control de la PC) sigue en tu
PC o en tu servidor; el dispositivo es la cara, el micrófono y el parlante.

**¿Necesito internet?**
Solo lo que necesite tu G-Mini (por ejemplo, el proveedor de IA). Los
dispositivos hablan únicamente con tu G-Mini, en tu red.

**¿Funciona sin la PC prendida?**
Las variantes WiFi y la Raspberry Pi necesitan un G-Mini encendido en algún
lado. Si quieres que esté siempre disponible, usa el modo servidor en una mini
PC o laptop vieja (24/7) y apunta los dispositivos ahí.

**¿Puedo conectar el ESP32 a G-Mini de escritorio?**
Sí, si activas "Permitir conexiones" en todas las redes (Ajustes > Dispositivos >
Este equipo). Con la opción de Tailscale no: el ESP32 no puede unirse a
Tailscale. Ver [conectar con G-Mini](connect-gmini.md).

**¿El micrófono escucha todo el tiempo?**
No por defecto: se graba solo mientras mantienes el botón. Si activas la
palabra de activación, el dispositivo detecta voz localmente y manda frases
cortas a tu G-Mini para ver si dijiste "Oye G-Mini". En la Raspberry Pi puedes
usar openWakeWord para que esa detección sea local.

**¿Por qué "Oye G-Mini" se detecta en el servidor y no en el ESP32?**
Un detector de palabra clave en el ESP32 necesita un modelo entrenado por
palabra (y memoria y trabajo de afinado). Con `/voice/wake` el servidor usa el
mismo reconocedor de voz que ya tiene, entiende el nombre que le hayas puesto
a tu agente y además devuelve lo que pediste en la misma frase.

**¿Puedo cambiar el nombre "G-Mini"?**
El nombre lo defines en la identidad del agente, dentro de los ajustes de
G-Mini. La cara muestra "Conectada a <nombre>" y la palabra de activación usa
ese nombre.

**¿Qué pasa si el agente quiere prender un relé?**
`relay.set` es una superficie sensible: pasa por la política de aprobaciones
del agente igual que cualquier acción local (te pedirá confirmación si así lo
configuraste).

**¿Puedo usar otra placa?**
Cualquier ESP32 con dos periféricos I2S sirve: cambia los pines con
`build_flags`. El ESP32-C3 tiene un solo I2S (micrófono o parlante, no ambos a
la vez con este firmware). Para pantallas, cualquier controlador soportado por
U8g2 o LovyanGFX se agrega en `src/ui.cpp`.

**¿Por qué el Uno usa una fuente sin tildes y dibuja las tildes aparte?**
La fuente con todos los caracteres de ISO-8859-1 ocupaba 1 KB más y el sketch
no entraba en el Nano. Las vocales con tilde, la ñ y la ü se dibujan como la
letra base más su marca.

**¿Es un holograma de verdad?**
No: ninguna técnica de la guía es holografía (interferencia de luz). Son
ilusiones de imagen flotante muy efectivas: reflejos (Pepper), proyección en
medios casi invisibles (niebla, humo, tul) o persistencia de la visión (POV).
Ver [hologramas](holograms/README.md).

**¿Puedo vender lo que construya?**
Sí. El código es MIT y los diseños CC BY-SA 4.0: puedes fabricar y vender,
dando crédito y publicando tus cambios a los diseños bajo la misma licencia.

**¿Dónde reporto un problema?**
En el repositorio, con la variante, el comando que usaste y la salida de la
consola. Problemas de seguridad: [SECURITY.md](../SECURITY.md).

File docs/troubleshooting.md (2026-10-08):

# Solución de problemas

## Conexión con G-Mini

| Síntoma | Causa probable | Qué hacer |
|---|---|---|
| "No encuentro a G-Mini" / `connect_failed` | El núcleo escucha solo en `127.0.0.1`, IP equivocada o firewall | `curl http://IP:8765/api/v1/health` desde otro equipo; activa "Permitir conexiones" o el modo servidor ([guía](connect-gmini.md)) |
| "Código inválido o vencido" | El código dura 5 minutos y sirve una vez | Pide uno nuevo y escríbelo sin espacios extra |
| "Demasiados intentos" | 5 intentos por minuto por IP | Espera un minuto |
| Se conecta y a los segundos se desconecta | Token revocado | El ESP32 lo detecta y pide emparejar; en el puente y la Pi usa `--pair` otra vez |
| "Me falta un permiso" | El código se creó sin el scope necesario | Empareja con `chat`, `voice` y `node` |
| Te entiende pero no contesta | El agente no tiene un proveedor de IA activo | Revisa el modelo en G-Mini; la cara muestra "G-Mini no respondió" |
| "Estoy ocupada" | El agente está en otro turno (409) | Espera o cancela con el botón de cancelar |

## Cara USB

| Síntoma | Qué hacer |
|---|---|
| OLED negra | Revisa VCC/GND, SDA en A4 y SCL en A5. Muchos módulos usan la dirección 0x3C (la que usa U8g2); si el tuyo es SH1106 compila con `GMINI_OLED_SH1106=1` |
| La imagen sale corrida 2 píxeles | Es una SH1106 grabada como SSD1306: recompila con `GMINI_OLED_SH1106=1` |
| El puente no encuentra la placa | `python gmini_serial_bridge.py --list-ports`; instala el driver CH340 en Windows; usa `--port COM5` |
| `ERR:overflow` en el monitor | Línea de más de 71 caracteres: el puente ya recorta, revisa scripts propios |
| Los botones disparan solos | Cables sueltos o botón entre pines equivocados: cada botón va de su pin a GND |
| El micrófono no graba | `--list-audio` y elige con `--mic`; en Windows revisa los permisos de micrófono para apps de escritorio |
| La carga falla en un Nano | Usa `arduino:avr:nano:cpu=atmega328old` |

## ESP32

| Síntoma | Qué hacer |
|---|---|
| No aparece la red `G-Mini-Home-XXXX` | Ya tiene WiFi guardado: mantén MODO 3 s y suelta, o enciéndela con MODO presionado |
| El portal no abre solo | Entra a `http://192.168.4.1`; desactiva los datos móviles mientras configuras |
| Pantalla negra (OLED) | SDA en GPIO8 y SCL en GPIO9; si ves rayas, baja el bus con `-DGMINI_OLED_I2C_HZ=400000` |
| Pantalla TFT blanca o con colores invertidos | Revisa CS/DC/RES; para colores invertidos cambia `cfg.invert` en `src/ui.cpp` |
| "audio no disponible" en la consola | Revisa los pines I2S del INMP441 y el MAX98357A |
| Grabación muda | L/R del INMP441 a GND; el firmware elige solo el canal con señal, pero si VDD no llega no hay nada que elegir |
| Se oye chasquido o ruido | GND común corto, fuente de 2 A, cables I2S cortos; baja el volumen (`volumen 50`) |
| Se reinicia al hablar | Caída de tensión: fuente de 2 A, cable USB corto y condensador de 470 uF en la alimentación del amplificador |
| LEDs con colores al azar | Falta GND común o la señal de 3,3 V no alcanza: resistencia de 330 ohm y, si sigue, un 74AHCT125 |
| "La voz del servidor no está lista" | G-Mini no tiene motor de voz: revisa TTS/STT en el núcleo |
| Responde muy lento | El servidor transcribe con CPU: usa un modelo de Whisper más chico o una PC más rápida |

Diagnóstico: `pio device monitor` y el comando `estado`. Para ver más
detalle compila con `-DCORE_DEBUG_LEVEL=4`.

## Raspberry Pi

| Síntoma | Qué hacer |
|---|---|
| El servicio no arranca | `journalctl -u gmini-pi -e`; prueba a mano con `python -m gmini_pi --demo --windowed` |
| "kmsdrm not available" | Con escritorio reinstala con `--desktop`; sin escritorio agrega el usuario al grupo `video` (lo hace el instalador) |
| Pantalla al revés o de costado | `display.rotate` en el config |
| Va lento | Baja `display.fps` o pon `display.supersample = 1` |
| Sin audio | `python -m gmini_pi --list-audio` y fija `audio.input` / `audio.output` |
| Los botones no responden | Pines BCM (no físicos) en `[buttons]`; el usuario debe estar en el grupo `gpio` |
| La tablet no ve el kiosco | `kiosk.listen = "0.0.0.0:8088"` y el puerto abierto en el firewall de la Pi |

## Hologramas

| Síntoma | Qué hacer |
|---|---|
| La imagen de la pirámide se ve doble | La lámina es gruesa: usa PET de 0,5 mm o acrílico más fino; los dos lados reflejan |
| La imagen sale al revés | Usa `layout = "pyramid"` (o `mirror` para la caja de Pepper); para la caja prueba girar la pantalla 180° |
| Se ve tenue | Apaga la luz de la sala, sube el brillo de la pantalla y usa fondo negro detrás de la pirámide |

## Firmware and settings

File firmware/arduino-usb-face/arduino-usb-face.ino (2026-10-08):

// G-Mini Home - cara USB para Arduino Uno / Nano.
//
// OLED SSD1306 (o SH1106) de 128x64 por I2C con dos ojos animados y dos
// botones. Se conecta por USB a la PC, donde gmini_serial_bridge.py traduce
// entre este protocolo serie y G-Mini (estado del agente, avisos y voz).
//
// Protocolo (115200 baudios, una orden por linea): ver docs/serial-protocol.md
//   PC -> placa: S:<estado> E:<emocion> T:<texto> N:<titulo>|<cuerpo> L:<0-9>
//                G:<x>,<y> K Z:<0|1> C:<0-255> ? V
//   placa -> PC: H:gmini-usb-face;<version>;1  OK  B:<id>:<down|up|long>  ERR:<codigo>
//
// Cableado (Uno/Nano): OLED SDA -> A4, SCL -> A5, VCC -> 5V, GND -> GND.
// Boton 1 (hablar) -> D2 y GND. Boton 2 (cancelar) -> D3 y GND.
//
// Requiere las bibliotecas U8g2 y GMiniEyes (firmware/libraries/GMiniEyes).

#include <Arduino.h>
#include <GMiniEyes.h>
#include <GMiniRaster.h>
#include <GMiniSerialProto.h>
#include <U8g2lib.h>
#include <Wire.h>

// 1 = controlador SH1106 (modulos de 1,3"). 0 = SSD1306 (0,96").
#ifndef GMINI_OLED_SH1106
#define GMINI_OLED_SH1106 0
#endif

// Saludo del protocolo: H:<firmware>;<version>;<protocolo>
#define GMINI_HELLO "H:gmini-usb-face;0.1.0;1"

static const uint8_t kButtonPins[] = {2, 3};
static const uint8_t kButtonCount = sizeof(kButtonPins);
static const uint16_t kLongPressMs = 1500;
static const uint8_t kFrameMs = 33;  // ~30 cuadros/s; el bus I2C a 400 kHz es el limite

// Bufer de 2 paginas (256 bytes): la RAM del Uno no alcanza para el cuadro completo.
#if GMINI_OLED_SH1106
U8G2_SH1106_128X64_NONAME_2_HW_I2C oled(U8G2_R0, U8X8_PIN_NONE);
#else
U8G2_SSD1306_128X64_NONAME_2_HW_I2C oled(U8G2_R0, U8X8_PIN_NONE);
#endif

class OledCanvas : public gmini::SpanCanvas {
 public:
  OledCanvas() : SpanCanvas(128, 64) {}

 protected:
  void span(int16_t x0, int16_t x1, int16_t y, uint8_t color) override {
    oled.setDrawColor(color == gmini::kColorBackground ? 0 : 1);
    oled.drawHLine(x0, y, x1 - x0 + 1);
  }
};

OledCanvas canvas;
gmini::EyesEngine eyes;
gmini::SerialLineReader<72> reader;

char caption[44] = "";
char notifyTitle[22] = "";
char notifyBody[66] = "";
uint32_t notifyUntil = 0;
float compact = 0.0f;
uint32_t lastFrame = 0;

struct ButtonState {
  bool stable;
  bool raw;
  bool longSent;
  uint32_t changedAt;
  uint32_t pressedAt;
};
ButtonState buttons[kButtonCount];

void sendLine(const char* line) { Serial.println(line); }

// B:<id>:<accion>. Con dos botones el id es un solo digito.
void sendButton(uint8_t index, const char* action) {
  char buf[12] = "B:1:";
  buf[2] = (char)('1' + index);
  strcat(buf, action);
  sendLine(buf);
}

void sendHello() { Serial.println(F(GMINI_HELLO)); }

void copyText(char* dst, size_t len, const char* src) {
  strncpy(dst, src, len - 1);
  dst[len - 1] = '\0';
}

void handleCommand(char* line) {
  gmini::SerialCommand c;
  const gmini::SerialError err = gmini::parseSerialLine(line, &c);
  if (err == gmini::SerialError::Empty) return;
  if (err != gmini::SerialError::None) {
    Serial.print(F("ERR:"));
    Serial.println(gmini::serialErrorCode(err));
    return;
  }
  switch (c.cmd) {
    case gmini::SerialCmd::Status: eyes.setActivity((gmini::Activity)c.value); break;
    case gmini::SerialCmd::Emotion: eyes.setEmotion((gmini::Emotion)c.value); break;
    case gmini::SerialCmd::Text: copyText(caption, sizeof(caption), c.text); break;
    case gmini::SerialCmd::Notify:
      copyText(notifyTitle, sizeof(notifyTitle), c.text);
      copyText(notifyBody, sizeof(notifyBody), c.text2);
      notifyUntil = millis() + 6000;
      eyes.wake();
      break;
    case gmini::SerialCmd::Level: eyes.setLevel(c.value / 9.0f); break;
    case gmini::SerialCmd::Look: eyes.lookAt(c.lookX / 100.0f, c.lookY / 100.0f); break;
    case gmini::SerialCmd::LookRelease: eyes.releaseLook(); break;
    case gmini::SerialCmd::Blink: eyes.blink(); break;
    case gmini::SerialCmd::Sleep: eyes.sleep(); break;
    case gmini::SerialCmd::Wake: eyes.wake(); break;
    case gmini::SerialCmd::Contrast: oled.setContrast(c.value); break;
    case gmini::SerialCmd::Ping: sendLine("OK"); break;
    case gmini::SerialCmd::Version: sendHello(); break;
    case gmini::SerialCmd::None: break;
  }
}

void pollSerial() {
  while (Serial.available() > 0) {
    if (!reader.feed((char)Serial.read())) continue;
    if (reader.overflowed()) {
      sendLine("ERR:overflow");
      continue;
    }
    handleCommand(reader.line());
  }
}

void pollButtons(uint32_t now) {
  for (uint8_t i = 0; i < kButtonCount; ++i) {
    ButtonState& b = buttons[i];
    const bool level = digitalRead(kButtonPins[i]) == LOW;
    if (level != b.raw) {
      b.raw = level;
      b.changedAt = now;
    }
    if (b.raw != b.stable && now - b.changedAt >= 25) {
      b.stable = b.raw;
      if (b.stable) {
        b.pressedAt = now;
        b.longSent = false;
        sendButton(i, "down");
        eyes.wake();
      } else {
        sendButton(i, "up");
      }
    }
    if (b.stable && !b.longSent && now - b.pressedAt >= kLongPressMs) {
      b.longSent = true;
      sendButton(i, "long");
    }
  }
}

// ------------------------------------------------------------------ texto
// La fuente _tr (solo ASCII) ocupa la mitad de flash que la _tf. Las vocales
// con tilde, la enie y la dieresis se dibujan como la letra base mas su marca.
// El texto llega en ISO-8859-1 (el puente convierte desde UTF-8).
enum Mark : uint8_t { kAcute = 1, kTilde = 2, kDiaeresis = 3 };
struct Latin1Glyph {
  uint8_t code;
  char base;
  uint8_t mark;
};
const Latin1Glyph kLatin1[] PROGMEM = {
    {0xE1, 'a', kAcute}, {0xE9, 'e', kAcute}, {0xED, 'i', kAcute},     {0xF3, 'o', kAcute},
    {0xFA, 'u', kAcute}, {0xF1, 'n', kTilde}, {0xFC, 'u', kDiaeresis}, {0xC1, 'A', kAcute},
    {0xC9, 'E', kAcute}, {0xCD, 'I', kAcute}, {0xD3, 'O', kAcute},     {0xDA, 'U', kAcute},
    {0xD1, 'N', kTilde}, {0xDC, 'U', kDiaeresis},
};
const uint8_t kCharW = 6;

// Los signos de apertura (inverted) no tienen glifo: se omiten.
bool skipChar(uint8_t c) { return c == 0xBF || c == 0xA1; }

void drawMark(int x, int y, uint8_t mark, bool upper) {
  const int top = upper ? y - 1 : y + 1;
  switch (mark) {
    case kAcute:
      oled.drawPixel(x + 3, top);
      oled.drawPixel(x + 2, top + 1);
      break;
    case kTilde:
      oled.drawPixel(x + 1, top + 1);
      oled.drawPixel(x + 2, top);
      oled.drawPixel(x + 3, top + 1);
      oled.drawPixel(x + 4, top);
      break;
    default:
      oled.drawPixel(x + 1, top + 1);
      oled.drawPixel(x + 3, top + 1);
      break;
  }
}

void drawText(int x, int y, const char* s) {
  for (; *s; ++s) {
    const uint8_t c = (uint8_t)*s;
    if (skipChar(c)) continue;
    if (c < 0x80) {
      if (c >= 32) oled.drawGlyph(x, y, c);
    } else {
      char base = '?';
      uint8_t mark = 0;
      for (uint8_t i = 0; i < sizeof(kLatin1) / sizeof(kLatin1[0]); ++i) {
        if (pgm_read_byte(&kLatin1[i].code) == c) {
          base = (char)pgm_read_byte(&kLatin1[i].base);
          mark = pgm_read_byte(&kLatin1[i].mark);
          break;
        }
      }
      oled.drawGlyph(x, y, base);
      if (mark) drawMark(x, y, mark, base < 'a');
    }
    x += kCharW;
  }
}

int textWidth(const char* s) {
  int n = 0;
  for (; *s; ++s) n += skipChar((uint8_t)*s) ? 0 : 1;
  return n * kCharW;
}

void drawCentered(const char* text, int y) { drawText((128 - textWidth(text)) / 2, y, text); }

// Corta el texto en lineas de hasta 21 caracteres (128 px / 6 px) por palabras.
void drawWrapped(const char* p, int y, uint8_t maxLines, bool centered) {
  char line[22];
  for (uint8_t row = 0; row < maxLines && *p; ++row) {
    size_t n = strlen(p);
    if (n > 21) {
      n = 21;
      while (n > 0 && p[n] != ' ') --n;
      if (n == 0) n = 21;
    }
    copyText(line, n + 1, p);
    if (centered) {
      drawCentered(line, y);
    } else {
      drawText(1, y, line);
    }
    y += 11;
    p += n;
    while (*p == ' ') ++p;
  }
}

void drawNotify() {
  oled.setDrawColor(1);
  oled.drawBox(0, 0, 128, 13);
  oled.setDrawColor(0);
  drawText(3, 1, notifyTitle);
  oled.setDrawColor(1);
  drawWrapped(notifyBody, 16, 4, false);
}

void renderFrame(uint32_t now) {
  const bool showNotify = notifyTitle[0] && (int32_t)(now - notifyUntil) < 0;
  const bool showCaption = caption[0] != '\0';
  compact += ((showCaption ? 1.0f : 0.0f) - compact) * 0.25f;
  const gmini::FaceLayout full = gmini::FaceLayout::fit(128, 64);
  const gmini::FaceLayout small = gmini::FaceLayout::fit(128, 40, 0.95f);
  gmini::FaceLayout layout;
  layout.scale = full.scale + (small.scale - full.scale) * compact;
  layout.originX = full.originX + (small.originX - full.originX) * compact;
  layout.originY = full.originY + (small.originY - full.originY) * compact;

  oled.firstPage();
  do {
    // Solo se rasterizan las filas de la pagina actual.
    const int16_t top = oled.getBufferCurrTileRow() * 8;
    canvas.setClipRows(top, top + oled.getBufferTileHeight() * 8 - 1);
    if (showNotify) {
      drawNotify();
    } else {
      gmini::drawFace(eyes.frame(), canvas, layout);
      if (showCaption && compact > 0.6f) {
        oled.setDrawColor(1);
        drawWrapped(caption, 42, 2, true);
      }
    }
  } while (oled.nextPage());
}

void setup() {
  Serial.begin(115200);
  for (uint8_t i = 0; i < kButtonCount; ++i) {
    pinMode(kButtonPins[i], INPUT_PULLUP);
    buttons[i].raw = buttons[i].stable = digitalRead(kButtonPins[i]) == LOW;
    buttons[i].longSent = true;
  }
  oled.setBusClock(400000);
  oled.begin();
  oled.setFont(u8g2_font_6x10_tr);
  oled.setFontPosTop();
  eyes.begin(millis());
  sendHello();
}

void loop() {
  const uint32_t now = millis();
  pollSerial();
  pollButtons(now);
  if (now - lastFrame >= kFrameMs) {
    lastFrame = now;
    eyes.update(now);
    renderFrame(now);
  }
}

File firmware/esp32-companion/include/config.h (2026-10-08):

// Configuracion de pines y valores por defecto de G-Mini Home (ESP32 / ESP32-S3).
//
// Todo se puede sobrescribir con build_flags en platformio.ini, por ejemplo:
//   -DPIN_BTN_TALK=41 -DGMINI_RELAY_COUNT=0 -DGMINI_OLED_SH1106=1
#pragma once

#define GMINI_DISPLAY_NONE 0
#define GMINI_DISPLAY_OLED 1
#define GMINI_DISPLAY_ST7789 2
#define GMINI_DISPLAY_GC9A01 3

#ifndef GMINI_DISPLAY
#define GMINI_DISPLAY GMINI_DISPLAY_OLED
#endif
#define GMINI_HAS_TFT (GMINI_DISPLAY == GMINI_DISPLAY_ST7789 || GMINI_DISPLAY == GMINI_DISPLAY_GC9A01)

#ifndef GMINI_FW_NAME
#define GMINI_FW_NAME "gmini-home-esp32"
#endif
#ifndef GMINI_FW_VERSION
#define GMINI_FW_VERSION "0.0.0-dev"
#endif

// --------------------------------------------------------------- pantalla OLED
#ifndef GMINI_OLED_SH1106
#define GMINI_OLED_SH1106 0  // 1 = controlador SH1106 (modulos de 1,3")
#endif
#ifndef GMINI_OLED_I2C_HZ
#define GMINI_OLED_I2C_HZ 800000  // baja a 400000 si ves rayas o el modulo no responde
#endif

// --------------------------------------------------------------- pantalla TFT
#ifndef GMINI_TFT_WIDTH
#define GMINI_TFT_WIDTH 240
#endif
#ifndef GMINI_TFT_HEIGHT
#define GMINI_TFT_HEIGHT 280
#endif
#ifndef GMINI_TFT_OFFSET_X
#define GMINI_TFT_OFFSET_X 0
#endif
#ifndef GMINI_TFT_OFFSET_Y
#define GMINI_TFT_OFFSET_Y 0
#endif
#ifndef GMINI_TFT_SPI_HZ
#define GMINI_TFT_SPI_HZ 40000000
#endif

// --------------------------------------------------------------- anillo LED
#ifndef GMINI_LED_RING
#define GMINI_LED_RING 0
#endif
#ifndef GMINI_LED_COUNT
#define GMINI_LED_COUNT 12
#endif

// --------------------------------------------------------------- reles
#ifndef GMINI_RELAY_COUNT
#define GMINI_RELAY_COUNT 2
#endif
#ifndef GMINI_RELAY_ACTIVE_LOW
#define GMINI_RELAY_ACTIVE_LOW 1  // la mayoria de modulos de rele se activan con nivel bajo
#endif

// --------------------------------------------------------------- pines
#if defined(GMINI_BOARD_S3)
// ESP32-S3-DevKitC-1 N16R8. Ojo: GPIO 26-37 son de la flash/PSRAM octal y 19/20 del USB nativo.
#ifndef PIN_I2C_SDA
#define PIN_I2C_SDA 8
#endif
#ifndef PIN_I2C_SCL
#define PIN_I2C_SCL 9
#endif
#ifndef PIN_TFT_SCLK
#define PIN_TFT_SCLK 12
#endif
#ifndef PIN_TFT_MOSI
#define PIN_TFT_MOSI 11
#endif
#ifndef PIN_TFT_CS
#define PIN_TFT_CS 10
#endif
#ifndef PIN_TFT_DC
#define PIN_TFT_DC 13
#endif
#ifndef PIN_TFT_RST
#define PIN_TFT_RST 14
#endif
#ifndef PIN_TFT_BL
#define PIN_TFT_BL 21
#endif
#ifndef PIN_MIC_SCK
#define PIN_MIC_SCK 4
#endif
#ifndef PIN_MIC_WS
#define PIN_MIC_WS 5
#endif
#ifndef PIN_MIC_SD
#define PIN_MIC_SD 6
#endif
#ifndef PIN_AMP_BCLK
#define PIN_AMP_BCLK 15
#endif
#ifndef PIN_AMP_LRC
#define PIN_AMP_LRC 16
#endif
#ifndef PIN_AMP_DIN
#define PIN_AMP_DIN 7
#endif
#ifndef PIN_BTN_TALK
#define PIN_BTN_TALK 17
#endif
#ifndef PIN_BTN_MODE
#define PIN_BTN_MODE 18
#endif
#ifndef PIN_LED_RING
#define PIN_LED_RING 47
#endif
#ifndef PIN_RELAY_1
#define PIN_RELAY_1 39
#endif
#ifndef PIN_RELAY_2
#define PIN_RELAY_2 40
#endif
#ifndef PIN_LIGHT_SENSOR
#define PIN_LIGHT_SENSOR -1  // GPIO 2 si conectas una LDR con divisor
#endif

#else
// ESP32 DevKit V1 (WROOM-32). GPIO 34-39 son solo entrada; 6-11 son de la flash; 12 es de arranque.
#if GMINI_HAS_TFT
#error "Las pantallas TFT solo estan configuradas para el ESP32-S3 (usa esp32s3-st7789 o esp32s3-gc9a01)"
#endif
#ifndef PIN_I2C_SDA
#define PIN_I2C_SDA 21
#endif
#ifndef PIN_I2C_SCL
#define PIN_I2C_SCL 22
#endif
#ifndef PIN_MIC_SCK
#define PIN_MIC_SCK 26
#endif
#ifndef PIN_MIC_WS
#define PIN_MIC_WS 25
#endif
#ifndef PIN_MIC_SD
#define PIN_MIC_SD 33
#endif
#ifndef PIN_AMP_BCLK
#define PIN_AMP_BCLK 27
#endif
#ifndef PIN_AMP_LRC
#define PIN_AMP_LRC 14
#endif
#ifndef PIN_AMP_DIN
#define PIN_AMP_DIN 13
#endif
#ifndef PIN_BTN_TALK
#define PIN_BTN_TALK 4
#endif
#ifndef PIN_BTN_MODE
#define PIN_BTN_MODE 0  // boton BOOT de la placa
#endif
#ifndef PIN_LED_RING
#define PIN_LED_RING 18
#endif
#ifndef PIN_RELAY_1
#define PIN_RELAY_1 23
#endif
#ifndef PIN_RELAY_2
#define PIN_RELAY_2 19
#endif
#ifndef PIN_LIGHT_SENSOR
#define PIN_LIGHT_SENSOR -1  // GPIO 34 si conectas una LDR con divisor
#endif
#endif

// --------------------------------------------------------------- audio
#define GMINI_SAMPLE_RATE 16000
#ifndef GMINI_MIC_SHIFT
#define GMINI_MIC_SHIFT 14  // ganancia del INMP441: menor = mas fuerte
#endif
#ifndef GMINI_MAX_RECORD_SECONDS
#if defined(BOARD_HAS_PSRAM)
#define GMINI_MAX_RECORD_SECONDS 15
#else
#define GMINI_MAX_RECORD_SECONDS 3
#endif
#endif
#define GMINI_MIN_RECORD_MS 350

// --------------------------------------------------------------- red y portal
#define GMINI_DEFAULT_PORT 8765
#define GMINI_AP_PREFIX "G-Mini-Home-"
#define GMINI_AP_PASSWORD "gminihome"
#define GMINI_PORTAL_TIMEOUT_S 300
#define GMINI_WS_PING_MS 25000
#define GMINI_HTTP_CONNECT_MS 6000
#define GMINI_HTTP_IDLE_MS 45000
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

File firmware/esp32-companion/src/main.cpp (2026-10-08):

// G-Mini Home: companero WiFi de G-Mini Agent para ESP32 / ESP32-S3.
//
// Bucle principal (nucleo 1): red, botones, consola y voz.
// Tarea de interfaz (nucleo 1, prioridad mayor): cara y LEDs a ~40 cuadros/s.
#include <Arduino.h>
#include <GMiniEyes.h>
#include <WiFi.h>

#include "api.h"
#include "audio.h"
#include "buttons.h"
#include "config.h"
#include "console.h"
#include "provision.h"
#include "remote.h"
#include "settings.h"
#include "ui.h"
#include "voice.h"

namespace {

Settings gSettings;
Button gTalk;
Button gMode;
uint32_t gLastNetCheck = 0;
uint32_t gLastTokenCheck = 0;
bool gWifiUp = false;
bool gNeedsPairing = false;
char gPendingSpeech[200] = "";

void showPairingHelp() {
  gNeedsPairing = true;
  ui::setEmotion(gmini::Emotion::Thinking);
  if (ui::hasDisplay()) {
    ui::setup("Falta emparejar",
              "Mantén MODO 3 s y escribe el código de G-Mini, o usa la consola: emparejar 123456");
  }
}

void onReady(const char* agentName) {
  if (strcmp(agentName, gSettings.agentName) != 0) {
    strlcpy(gSettings.agentName, agentName, sizeof(gSettings.agentName));
    settingsSave(gSettings);
  }
  ui::setOnline(true, true);
  ui::setEmotion(gmini::Emotion::Happy);
  char text[64];
  snprintf(text, sizeof(text), "Conectada a %s", agentName);
  ui::caption(text, 3000);
  log_i("sesion lista con %s", agentName);
}

void onState(const char* status, const char* emotion) {
  // Durante un turno local la cara la maneja el flujo de voz.
  if (voice::busy()) return;
  gmini::Activity activity;
  gmini::Emotion mood;
  if (gmini::parseActivity(status, &activity)) ui::setActivity(activity);
  if (gmini::parseEmotion(emotion, &mood)) ui::setEmotion(mood);
}

void onNotify(const char* title, const char* body, const char* priority) {
  const bool high = strcmp(priority, "high") == 0 || strcmp(priority, "urgent") == 0;
  const uint32_t ms = high ? 15000 : 8000;
  ui::notify(title, body, ms);
  if (gSettings.speakNotifications && !voice::busy()) {
    snprintf(gPendingSpeech, sizeof(gPendingSpeech), "%s. %s", title, body);
  }
}

void onDisconnected() { ui::setOnline(gWifiUp, false); }

void startSession() {
  remote::stop();
  api::configure(gSettings);
  if (!gSettings.paired()) {
    showPairingHelp();
    return;
  }
  gNeedsPairing = false;
  ui::setup("", "");
  remote::Callbacks cb = {onReady, onState, onNotify, onDisconnected};
  remote::begin(gSettings, cb);
}

void openPortal() {
  remote::stop();
  provision::connect(gSettings, true);
  gWifiUp = WiFi.status() == WL_CONNECTED;
  startSession();
}

void factoryReset() {
  ui::setup("Restableciendo", "Se borran WiFi, servidor y token");
  settingsErase();
  provision::forgetWifi();
  delay(1500);
  ESP.restart();
}

void handleButtons(uint32_t now) {
  switch (gTalk.poll(now)) {
    case Button::kPress:
      remote::sendButton("talk", "down");
      voice::talkPressed();
      break;
    case Button::kRelease:
      remote::sendButton("talk", "up");
      voice::talkReleased();
      break;
    default:
      break;
  }
  static bool longHeld = false;
  switch (gMode.poll(now)) {
    case Button::kRelease:
      if (longHeld) {
        // Soltar despues de 3 s (y antes de 10 s) abre el portal.
        longHeld = false;
        openPortal();
      } else if (!voice::busy()) {
        // Pulsacion corta: corta la respuesta en curso y muestra el estado.
        remote::sendCancel();
        char text[96];
        snprintf(text, sizeof(text), "%s  %s", WiFi.localIP().toString().c_str(),
                 remote::connected() ? gSettings.agentName : "sin servidor");
        ui::caption(text, 4000);
      }
      break;
    case Button::kLong:
      longHeld = true;
      ui::caption("Suelta para abrir el portal; 10 s borra todo", 4000);
      break;
    case Button::kVeryLong:
      factoryReset();
      break;
    default:
      break;
  }
}

void checkNetwork(uint32_t now) {
  if (now - gLastNetCheck < 2000) return;
  gLastNetCheck = now;
  const bool up = WiFi.status() == WL_CONNECTED;
  if (up != gWifiUp) {
    gWifiUp = up;
    log_i("wifi %s", up ? "conectado" : "perdido");
    if (!up) WiFi.reconnect();
  }
  ui::setOnline(gWifiUp, remote::connected());
  // Varias conexiones rechazadas seguidas: se comprueba si el token fue revocado.
  if (gWifiUp && gSettings.paired() && remote::failedAttempts() >= 3 && now - gLastTokenCheck > 60000) {
    gLastTokenCheck = now;
    api::Error err = {};
    if (!api::me(&err) && err.status == 401) {
      log_w("token revocado: hay que emparejar de nuevo");
      settingsForgetPairing(gSettings);
      remote::stop();
      ui::setEmotion(gmini::Emotion::Sad);
      showPairingHelp();
    }
  }
}

}  // namespace

void setup() {
  Serial.begin(115200);
  delay(50);
  settingsLoad(gSettings);
  ui::begin(gSettings.brightness, gSettings.sleepMinutes);
  if (!audio::begin()) log_w("audio no disponible: revisa el cableado I2S");
  audio::setVolume(gSettings.volume);
  gTalk.begin(PIN_BTN_TALK, GMINI_LONG_PRESS_MS, GMINI_FACTORY_PRESS_MS);
  gMode.begin(PIN_BTN_MODE, GMINI_LONG_PRESS_MS, GMINI_FACTORY_PRESS_MS);
  console::Hooks hooks = {startSession, openPortal, factoryReset};
  console::begin(&gSettings, hooks);
  voice::begin(&gSettings);

  Serial.printf("\n%s %s - escribe 'ayuda' para ver los comandos\n", GMINI_FW_NAME, GMINI_FW_VERSION);
  // MODO presionado al encender: portal de configuracion aunque haya WiFi guardado.
  const bool force = gMode.enabled() && digitalRead(PIN_BTN_MODE) == LOW;
  gWifiUp = provision::connect(gSettings, force);
  if (!gWifiUp) {
    ui::setEmotion(gmini::Emotion::Sad);
    ui::caption("Sin WiFi: mantén MODO 3 s para configurar", 0);
  }
  startSession();
}

void loop() {
  const uint32_t now = millis();
  handleButtons(now);
  console::loop();
  checkNetwork(now);
  remote::loop();
  voice::loop();
  char speech[200];
  if (remote::takePendingSpeech(speech, sizeof(speech))) voice::say(speech);
  if (gPendingSpeech[0] && !voice::busy()) {
    strlcpy(speech, gPendingSpeech, sizeof(speech));
    gPendingSpeech[0] = '\0';
    voice::say(speech);
  }
  delay(1);
}

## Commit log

2026-10-08 chore: estructura base del repositorio y licencias
    Codigo bajo MIT y disenos de hardware y documentacion bajo CC BY-SA 4.0.
2026-10-08 feat(ojos): motor de expresiones compartido con presets generados
    common/expressions.json es la unica fuente de las emociones y estados; gen_expressions.py genera el encabezado C++, el modulo Python y el JS del kiosko, y con --check detecta archivos desactualizados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
2026-10-08 feat(common): port en Python del motor de ojos
    Mismo comportamiento que la version C++ (suavizado, parpadeo, mirada y sueno) para el cliente de Raspberry Pi, el puente y las vistas previas.
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2026-10-08 feat(link): utilidades de protocolo en flujo para el firmware
    Lectura incremental de respuestas HTTP (Content-Length y chunked), extraccion de campos JSON sin construir el arbol, base64 y WAV en flujo, enlaces gmini://pair, direcciones de servidor y un detector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
2026-10-08 feat(esp32): companero WiFi con cara animada, voz y superficies de nodo
    Portal cautivo con WiFiManager, emparejamiento con codigo o enlace gmini://, token en NVS, sesion WebSocket con hello/ready/ping, estados y avisos, y superficies display.face, display.text, led.set, 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
2026-10-08 perf(ojos): menos flash en AVR sin cambiar el comportamiento
    La forma animable pasa a un arreglo que se copia de un bloque desde el preset, el suavizado usa la aproximacion racional de 1 - exp(-dt/tau), el seno es una aproximacion de error ~0,1 %, los triangulos usan bordes en punto fijo y el protocolo serie ya no depende de strtol. El port en Python sigue las mismas formulas.
2026-10-08 feat(usb): cara para Arduino Uno y Nano con protocolo serie
    OLED SSD1306 o SH1106 con bufer de 2 paginas, rasterizado solo de las filas de cada pagina, dos botones con eventos down/up/long y texto ISO-8859-1 con tildes dibujadas sobre la fuente ASCII. Ocupa 2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
2026-10-08 feat(common): cliente de la Remote API v1 y flujos de voz en Python
    Cliente REST asincrono (emparejamiento, me, voice/turn, voice/wake, tts, stt
    y chat) con errores tipados, sesion WebSocket con reconexion exponencial, ping
    de aplicacion e invocaciones de superficies, almacen de tokens con llavero o
    archivo 600, WAV y detector de voz sin dependencias, y el asistente compartido:
    pulsar para hablar y 'Oye G-Mini' detectado por el servidor.
2026-10-08 feat(puente): puente serie USB con voz desde la PC
    Detecta la placa por VID/PID y saludo, reabre el puerto si se desconecta,
    traduce estados, avisos y superficies a ordenes del protocolo serie (texto
    ISO-8859-1) y usa el microfono y el parlante de la PC para pulsar y hablar.
    Empareja con codigo o enlace gmini:// y tambien acepta el token de sesion del
    escritorio. Si el agente no contesta, la cara lo indica en vez de quedarse
    callada (tambien en el firmware).
2026-10-08 feat(pi): cliente de pantalla para Raspberry Pi, mini PC y tablets
    Cara con pygame a cualquier resolucion (normal, espejo para Pepper y
    piramide de cuatro vistas), boton GPIO y teclado, palabra de activacion por el
    servidor u openWakeWord, modo demostracion, instalador con venv y servicio
    systemd endurecido, y una pagina de kiosco que recibe el estado por SSE sin
    exponer el token.
2026-10-08 test: pruebas de Python con servidor WebSocket falso
    Motor de ojos, cliente REST con transporte simulado, sesion WebSocket
    (registro, estados, avisos, invocaciones, token rechazado y reconexion), puente
    de punta a punta con placa y G-Mini falsos, configuracion, kiosco, generador de
    presets y una prueba de humo del dibujo con pygame.
2026-10-08 test: prueba de punta a punta contra un G-Mini real
    Empareja un dispositivo, valida me, el WebSocket y la voz (tts, turn y
    wake) y revoca el dispositivo al terminar.
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2026-10-08 docs(hardware): diagramas de cableado reproducibles por variante
    Cada placa se dibuja con el orden real de pines de sus cabeceras (ESP32-S3
    DevKitC-1, ESP32 DevKit V1, Arduino Uno/Nano y Raspberry Pi) y los modulos
    van del lado que usan. Cables por carriles con color por funcion, uniones,
    saltos en los cruces, conexiones por debajo de la placa cuando el pin esta
    del otro lado, leyenda y notas.
2026-10-08 docs: arquitectura, imagen principal y esquemas de hologramas
    build_all.py regenera todos los SVG y con --check falla si alguno quedo
    desactualizado. Incluye las diez tecnicas de imagen flotante con rayos de luz
    coherentes con la geometria (piramide, caja de Pepper, niebla, humo, LCD
    transparente, ventilador POV, volumetrica, tul, imagen aerea y mirascopio).
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2026-10-08 feat(hologramas): plantillas de corte de la piramide de Pepper por pantalla
    Nueve tamanos (telefono 6,1" a TV 32") con caras a 45 grados: abanico de una
    pieza en SVG 1:1 y DXF para lamina fina, cuatro trapecios sueltos en DXF para
    acrilico, y una tabla con medidas, materiales y la placa de la caja de Pepper.
    El telefono de 6,1" da el diseno clasico de 6 x 1 x 3,5 cm. Pruebas de
    geometria y de archivos al dia.
    [pyramid-laptop-15.6-net.dxf, pyramid-laptop-15.6-pieces.dxf, pyramid-monitor-24-net.dxf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]
2026-10-08 feat(hardware): carcasas parametricas en OpenSCAD con STL y renders
    - oled_companion: cabecita con ventana para la OLED, marco que sujeta el
    modulo, botones arriba, microfono al frente y tapa con rejilla y USB.
    - speaker_puck: cilindro para el ESP32-S3 con cuna para la placa, rejilla del
    parlante, canal y aro difusor para un anillo WS2812 de 24 LEDs y fondo a
    presion con huecos para patas de goma.
    - pepper_pyramid: marco imprimible con ranuras a 45 grados para las laminas.
    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
    [oled_companion-back.stl, oled_companion-shell.stl, oled_companion.scad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]
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2026-10-08 feat(pi): colores invertidos para LCD transparente
    display.invert en el cliente y ?invert=1 en el kiosco: en un LCD sin
    retroiluminacion lo negro queda opaco, asi los ojos se ven oscuros sobre la
    escena de fondo.
    [config.py, renderer.py]
2026-10-08 docs: guias paso a paso de las cinco variantes y referencias
    Conexion con G-Mini (modos del nucleo, emparejamiento y permisos), guias
    de la cara USB, el companero WiFi, el parlante con LEDs, la Raspberry Pi y el
    kiosco, protocolo serie, expresiones, grabacion del firmware con direcciones
    de flash, seguridad, solucion de problemas y preguntas frecuentes.
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2026-10-08 fix(diagramas): orden fijo de los puntos de union en el cableado
    Los grupos de cada carril salian de un set de tuplas de cadenas, cuyo orden
    cambia con PYTHONHASHSEED; build_all.py --check fallaba en algunas
    ejecuciones (en CI, con hardware/wiring/esp32dev.svg). Ahora se recorren en
    el orden de los cables. Comprobado con ocho semillas distintas.
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
